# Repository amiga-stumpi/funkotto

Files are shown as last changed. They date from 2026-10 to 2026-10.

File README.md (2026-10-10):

# FunkOtto

WLAN-Adapter für den Amiga-Parallelport auf Basis des Raspberry Pi Pico 2 W.
Ziel sind eine eigene Firmware, ein SANA-II-Treiber für 68000/AmigaOS 1.3 und
ein Amiga-Konfigurationsprogramm.

## Aktueller Stand

**Aktuelle Hardwarebasis seit 08.10.2026:** Die KiCad-Dateien unter
[hardware/](hardware/) entsprechen bytegenau dem vom Nutzer bearbeiteten
`AmiWiFi_Pico2W.zip`. Dieser Stand ersetzt das zuvor importierte Rev-B2-Board.
[Importnachweis und Prüfsummen](docs/results/2026-10-08-nutzer-kicad-import.md).

Die vorhandenen Vorschauen, Bestückungsdaten und DRC-/ERC-Berichte beziehen sich
auf den vorherigen Rev-B2-Stand. Für diesen Dateiimport wurden sie nicht neu
erzeugt; die frühere DRC-Freigängigkeit ist damit kein Prüfnachweis für das
geänderte Board.

[Vorheriger Hardwarestand vom 07.10.2026](docs/results/2026-10-07-revb2.md):
Rev B2 mit U8 SN74LVC2G07DCKR (SC70-6), angepasstem Lötbild und
nativen DRC-/ERC-Prüfberichten. [Bisheriger Fortschritt](docs/results/2026-10-06-fortschritt.md).

Das Repository enthält den [Entwicklungsplan für Firmware v0.1](docs/firmware-v0.1-plan.md)
und das vollständige KiCad-Projekt mit lokalen Bibliotheken, Stückliste und Prüfberichten.
**Die erste Pico-Firmware M1 ist implementiert und als UF2 gebaut:** sichere
GPIO-Zustände, USB-Diagnose (`help`, `info`, `status`) und Watchdog.
[Build- und Testanleitung](firmware/README.md) ·
[Prüfergebnisse M1](docs/results/2026-10-08-firmware-m1.md).
**W1/W2 ist jetzt als WLAN-Testfirmware implementiert:** Scan, RAM-Konfiguration,
WPA2-Verbindung und Wiederverbindung. [Bedienung und Testablauf](firmware/WLAN_TEST.md).
Scan und erster WPA2-Join wurden am 08.10.2026 auf dem Pico bestätigt
(`LINK_UP`, erster Versuch, Join 2679 ms). Manuelles Wiederverbinden und automatische Erholung
nach AP-Ausfall sind ebenfalls bestätigt. Dauerlauf und weitere Fehlerfälle
bleiben offen. **W3 ist implementiert:** Ethernet-Rohtransport mit festen Puffern,
USB-Testprotokoll und PC-Werkzeug für ARP/ICMP. [W3-Testanleitung](firmware/W3_TEST.md) ·
[W3-Prüfstand](docs/results/2026-10-09-w3.md). Die realen ARP/ICMP-Tests sind bestanden:
12/12 und anschließend 1.000/1.000 Echo-Antworten einschließlich MTU 1500,
keine Verluste. Der 1.000er-Lauf ist anhand von JSON und PCAP geprüft.
AP-Ausfall, Wiederverbindung und erneuter Pakettest sind vom Nutzer bestätigt.
Langzeitbetrieb und die Ursache einzelner Latenzausreißer bleiben offen.
**W4 ist implementiert:** dauerhaftes Profil, `wifi save`/`wifi erase` und
Autoconnect nach Stromverlust. [W4-Anleitung](firmware/W4_TEST.md) ·
[W4-Prüfstand](docs/results/2026-10-09-w4.md). Gespeichertes Profil und erster
Kaltstart mit automatischer Wiederverbindung sind am Pico bestätigt. Auch Löschtest
und erneutes Einrichten/Verbinden/Speichern sind bestanden; die weitergehende Hardwareabnahme
bleibt offen.
Parallelport-Kommunikation und Amiga-Treiber folgen.
USB-Diagnose und Kaltstart ohne geöffnetes Terminal wurden am 08.10.2026 vom
Nutzer auf einem realen Pico bestätigt. Die elektrische M0-Abnahme bleibt offen.
**W5 wird auf Nutzerwunsch ausgelassen. M2 ist softwareseitig umgesetzt:**
PIO/DMA-Amiga-Link und 68000-Diagnosetool für HELLO/ECHO.
[M2-Testanleitung](firmware/M2_TEST.md) · [Prüfbericht](docs/results/2026-10-09-m2.md).
Standard-UF2 gesperrt, aktive Bustests nach M0. Der Nutzer hat den portfreien
`FunkOttoDiag SELFTEST` mit 64 ECHOs auf einem Amiga 500 mit 68020,
Kickstart 1.3 und Workbench 1.3 erfolgreich ausgeführt. M2 enthält noch kein WLAN.
[WLAN-Entwicklungsplan](docs/wlan-entwicklungsplan.md).

**M4-USB-Konfiguration:** eigenes Ziel `funkotto_m4_usb` auf W4-Basis,
versionierte Konfigurationsbefehle und PC-Werkzeug `tools/wifi_config.py`.
[Plan](docs/konfigurationsprotokoll-plan.md) · [Testanleitung](firmware/M4_USB_TEST.md) ·
[Protokoll](protocol/CONFIG.md) · [Prüfstand](docs/results/2026-10-10-m4-usb.md).
Trägerplatine noch nicht verfügbar; M0 und aktive M2-Abnahme bleiben offen.

**Amiga-Konfiguration vorbereitet:** `FunkOttoConfig SELFTEST` und `SIM` bieten
einen lokalen FOC1-Selbsttest und eine interaktive Adapter-Simulation mit
verdeckter Passworteingabe. Für 68000 / OS 1.3 gebaut, mit OS-Mocks geprüft;
realer A500-Test und Paralleltransport noch offen. Kein Firmwareupdate nötig.
[Umsetzungsplan](docs/amiga-konfiguration-plan.md) ·
[Amiga-Testanleitung](amiga/config/README.md) ·
[Prüfstand](docs/results/2026-10-10-amiga-config.md).

Die erste Firmware soll Parallelport-Kommunikation, WLAN-Rohpakete und ein
dauerhaft gespeichertes WLAN-Profil mit automatischer Wiederverbindung bieten.
Firmwareinstallation und Updates erfolgen vorerst über USB/BOOTSEL am Pico.
Firmwareupdates über den Amiga sind zurückgestellt.

Die Hardwarebasis ist der Nutzerstand vom 08.10.2026 unter [hardware/](hardware/),
auf Grundlage von Rev B2 und der zuvor bearbeiteten Rev-A-Datei. Ein zusätzlicher
Open-Drain-Resetpfad setzt den Pico bei Amiga-Reset oder fehlender Hostversorgung
über RUN zurück. Für v0.1 ist vorgesehen: Nach Reset startet die Firmware neu und verbindet WLAN
erneut; das gespeicherte Profil bleibt erhalten. M1 enthält diese WLAN-Funktion noch nicht.

Für USB/BOOTSEL im Sockel DB25 und USB-C-Trägerversorgung trennen und den
eigenen USB-Anschluss des Pico verwenden; alternativ den Pico herausnehmen.

Die Resetvariante ist in Schaltplan und Board umgesetzt. Pulsbreiten, Pegel,
Versorgungsfolgen und sichere Bustreiberfreigabe müssen vor aktiven Bustests
am Muster gemessen werden (M0 im Plan). Es gibt noch keine Fertigungsfreigabe.

Rev B1 bereinigt die KiCad-Netznamen, Schaltplan-/Footprintattribute,
Bibliothekskopien und Beschriftungen. DRC **mit Schaltplanvergleich** sowie ERC
melden in KiCad 10.0.6 jeweils 0 Fehler und 0 Warnungen. Bauteilpositionen und
Kupferrouting blieben bei B1 unverändert. B2 ändert U8 auf DCKR/SC70-6 und
passte ausschließlich sein lokales Routing an; die damaligen DRC- und ERC-Läufe waren fehlerfrei. Die frühere Rev-B-Prüfung war hinsichtlich
des nativen Schaltplanabgleichs unvollständig; Details und damalige Hardware-
Prüfsummen stehen im Firmwareplan. Aktuelle Prüfsummen stehen im oben verlinkten Importnachweis.

## Ideen und spätere Erweiterungen

Die [Ideenliste](docs/ideenliste.md) sammelt fortlaufend Erweiterungswünsche.
Erster Eintrag: eine später nachrüstbare Traffic-LED, optional getrennt für TX/RX.

## KiCad-Projekt öffnen

Repository herunterladen und `hardware/AmiWiFi.kicad_pro` mit KiCad 10 öffnen.
Die Bibliotheken in `hardware/` gehören zum Projekt.

- [Hinweise zum Hardwarestand Rev B2](docs/KICAD_REV_B2.txt)
- [Stückliste](docs/BOM.csv) und [Pinbelegung](docs/PINOUT.csv)
- [Vorschauen](preview/) und [Prüfberichte](validation/)

Am 08.10.2026 durch die KiCad-Dateien aus dem Nutzerarchiv ersetzt.
Die Dateien wurden beim Import nicht bearbeitet. Elektrische Musterprüfung
und Fertigungsfreigabe bleiben offen.

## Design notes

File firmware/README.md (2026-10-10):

> **M4_USB:** [WLAN-Konfiguration über USB testen](M4_USB_TEST.md). Eigenes Ziel auf W4-Basis, Parallelport gesperrt; erster realer HELLO-/Statustest mit gespeichertem Profil und LINK_UP bestanden; weitere Konfigurationsprüfungen offen.

> **M2 softwareseitig umgesetzt:** [Amiga-Diagnose und Laborablauf](M2_TEST.md).
> Nutzer-SELFTEST mit 64 ECHOs auf Amiga 500 / 68020 / Kickstart 1.3 / Workbench 1.3 bestanden.
> Standard-Build gesperrt, aktive M2-Abnahme offen; WLAN separat in W4.

> Neu: **W4** als Ziel `funkotto_w4`: dauerhaftes Profil und Autoconnect.
> [W4-Bedienung und Kaltstarttest](W4_TEST.md). Gespeichertes Profil und erster Kaltstart mit automatischer Wiederverbindung am Pico bestätigt; Löschtest und erneutes Einrichten/Verbinden/Speichern bestanden. Weitergehende Hardwareabnahme noch offen.

> W3 ist als zusätzliches Ziel `funkotto_w3` implementiert:
> [Roh-Ethernet über USB testen](W3_TEST.md). Die realen ARP/ICMP-Tests sind bestanden
> (12/12 und 1.000/1.000, MTU 1500; JSON/PCAP geprüft). AP-Ausfall mit
> Wiederverbindung und erneutem Pakettest ist vom Nutzer bestätigt.
> Langzeitbetrieb und Latenzausreißer bleiben offen.
> M1 und W1/W2 bleiben separat baubar; alle drei Ziele halten den Amiga-Bus gesperrt.

# FunkOtto – Pico-Firmware

**Neu: [W1/W2-WLAN-Testfirmware und Bedienung](WLAN_TEST.md).**
Der Standardbuild erzeugt zusätzlich `funkotto_w12.uf2` mit Scan, RAM-Profil
und WPA2-Verbindung auf Core 1. M1 bleibt als eigenes Diagnoseziel erhalten.
WLAN ist softwareseitig gebaut/getestet; der reale Funk-Test steht noch aus.

## M1-Grundversion

`0.1.0-m1` ist die erste USB-Diagnose-Firmware für **Pico 2 W / RP2350 Arm**.
Sie ist noch kein Netzwerkadapter. M1 liefert Build, sicheren Grundstart,
USB-Konsole und Watchdog. WLAN, Parallelport-Protokoll, Profilspeicherung und
SANA-II folgen in den nächsten Arbeitspaketen.

## Implementiert

- GPIO-Initialisierung vor USB/Diagnose: GP21 `FW_DATA_EN` und GP22 `FW_CTRL_EN`
  dauerhaft Low, GP20 `DATA_DIR` High (Amiga → Pico).
- GP0–GP11 und GP26 bleiben Eingänge; BUSY/ACK werden nur im Ausgangslatch
  vorbereitet. Es gibt in M1 keinen Befehl zum Einschalten der Bustreiber.
- Keine UART-Ausgabe auf den Datenpins GP0/GP1; keine Nutzung freier GP27/GP28.
- USB-CDC-Diagnose mit `help`, `info`, `status`, begrenztem Zeilenpuffer und
  begrenzter Eingabearbeit pro Hauptschleife.
- Start wartet nicht auf ein angeschlossenes USB-Terminal. USB-Ausgaben haben
  einen kurzen Timeout; ein verpasster Starttext lässt sich mit `info` abrufen.
- 8-s-Watchdog; unerwartete Pinzustände führen zur erneuten Sperrung und zum
  Watchdog-Neustart. Externe 4,7-kΩ-Pulldowns sichern die Zeit vor Firmwarestart.
- Letzte 8192 Byte des 4-MiB-Flashs für spätere Profile reserviert:
  Flashoffsets `0x003FE000` und `0x003FF000`, XIP ab `0x103FE000`.
  M1 schreibt oder löscht dort nichts. Linker und UF2-Prüfung sichern die Grenze.
- Ein weiterer 4-KiB-Sektor direkt davor (`0x103FD000`–`0x103FDFFF`) bleibt für
  den RP2350-E10-Kompatibilitätsblock reserviert. Die UF2 setzt diesen Block
  gezielt auf `0x103FDF00`; die SDK-Standardadresse `0x10FFFF00` wird vermieden.
  Diese Trennung ist vor der späteren Profilspeicherung am Muster zu testen.

Core 0 bedient Diagnose und Watchdog; Core 1 ist noch unbenutzt. Es gibt keine
eigenen PIO-/DMA-Belegungen. SDK/TinyUSB verwenden ihre USB-Interrupt- und
Timermechanismen. Die Ressourcenaufteilung mit CYW43 folgt vor M2/M3.
Die Traffic-LED und Polyfuse bleiben Einträge in der Ideenliste.

## Bauen (Linux, Referenz Ubuntu 24.04)

Versionen und Commit-IDs stehen in [`dependencies.json`](dependencies.json).
Der SDK-Build wird auf Pico SDK 2.2.0 und dessen TinyUSB-Commit geprüft;
picotool 2.2.0 wird anhand einer festen Commit-ID bezogen.

```sh
sudo apt-get update
sudo apt-get install --no-install-recommends git build-essential python3 python3-venv \
  gcc-arm-none-eabi=15:13.2.rel1-2 \
  binutils-arm-none-eabi=2.42-1ubuntu1+23 \
  libnewlib-arm-none-eabi=4.4.0.20231231-2 \
  libnewlib-dev=4.4.0.20231231-2 \
  libstdc++-arm-none-eabi-dev=15:13.2.rel1-2+26
python3 -m venv .venv
. .venv/bin/activate
python -m pip install cmake==3.31.6 ninja==1.11.1.4
python tools/bootstrap_sdk.py
python tools/check_board_contract.py
python tests/run_host_tests.py
python -m unittest discover -s tests -p 'test_*.py'
cmake -S firmware -B build/m1 -G Ninja \
  -DPICO_SDK_PATH="$PWD/.deps/pico-sdk" \
  -DCMAKE_BUILD_TYPE=Release \
  -DFUNKOTTO_SOURCE_ID="$(git rev-parse --short=12 HEAD)"
cmake --build build/m1 --parallel
python tools/check_firmware_artifacts.py build/m1
python tools/check_firmware_artifacts.py build/m1 --target funkotto_w12
```

Beim ersten Build werden SDK, TinyUSB, CYW43 und picotool benötigt; Netzwerkzugang ist
dafür erforderlich. Warnungen zu nicht initialisierten lwIP-/Bluetooth-Submodulen sind erwartbar:
W1/W2 nutzt CYW43 ohne diese Bibliotheken. Das SDK meldet dabei pauschal fehlende
volle WLAN-Unterstützung; unser eigenes Poll-Target wird trotzdem gebaut.
In einer Umgebung ohne Zugriff auf `/proc` kann LeakSanitizer nicht arbeiten;
für die heapfreien C-Tests dort `ASAN_OPTIONS=detect_leaks=0` setzen.
AddressSanitizer und UndefinedBehaviorSanitizer bleiben dabei aktiv.

Ergebnisse: `funkotto_m1.uf2`, `funkotto_m1.elf`, `funkotto_m1.elf.map`,
`funkotto_m1.bin` und `manifest.json` mit Quellen-/Artefaktprüfsummen und
Werkzeugversionen. W1/W2 liefert gleichnamige Dateien mit Präfix
`funkotto_w12` und `funkotto_w12-manifest.json`. Mit
`-DFUNKOTTO_BUILD_WIFI=OFF` lässt sich ausschließlich M1 bauen. Die CI baut und prüft dieselben Ziele. SDK-Dateipfade werden
im Zielcode normalisiert; eine Zusage für beliebige andere Toolchainstände
oder bitidentische Debug-Dateien ergibt sich daraus nicht.

## Erster Test am Pico

1. Am einfachsten den Pico aus dem Trägersockel nehmen. Für den USB-Service im
   Sockel **DB25 und USB-C-Trägerversorgung abziehen**. USB-C am Träger ist nur
   Versorgung, nicht die Programmierschnittstelle.
2. BOOTSEL gedrückt halten und den eigenen USB-Port des Pico mit dem PC verbinden.
3. `funkotto_m1.uf2` auf das BOOTSEL-Laufwerk kopieren. Der Pico startet neu.
4. Den neuen seriellen USB-Port öffnen (z. B. 115200, 8N1, keine Flusssteuerung).
   Befehle mit Enter abschließen. Die eingestellte Baudrate ist bei USB-CDC
   kein physischer UART-Takt.
5. `info`, danach `status` eingeben. Erwartet: `stage=M1`, `bus_locked=1`,
   `output_mask=0x00700000`. Nur die drei Steuer-GPIOs 20/21/22 sind Ausgänge.
6. Pico stromlos machen, erneut verbinden und wieder `status` abfragen.

`safe_init_us` ist der interne Timerstand nach GPIO-Initialisierung. Er ist
**keine Messung Versorgung → Parallelport-Bereitschaft**; M1 bietet noch keine
Parallelport-Antwort. Ohne WLAN-Initialisierung leuchtet auch die Pico-WLAN-LED
nicht automatisch. Ein ausgeschaltetes Terminal verhindert den Firmwarestart nicht.

Messungen am Träger gemäß M0 bleiben offen. Der Nutzer hat am 08.10.2026 USB-Status und Kaltstart ohne geöffnetes Terminal
auf dem Pico bestätigt ([Bericht](../docs/results/2026-10-08-firmware-m1.md)).
Elektrische Pegel, Reset-Pulsbreiten und Watchdog-Fehlerinjektion bleiben ungeprüft.
Die nächsten Schritte stehen im [WLAN-Plan](../docs/wlan-entwicklungsplan.md).

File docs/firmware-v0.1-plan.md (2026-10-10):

# FunkOtto: Plan für die erste funktionale Firmware v0.1

Stand: 10.10.2026 · Status: M1 und WLAN W1–W4 umgesetzt, Grundfunktionen am Pico bestätigt; M2 softwareseitig umgesetzt, W5 ausgelassen, M0 offen

## 1. Ziel und Entscheidung

FunkOtto verbindet den Amiga-Parallelport über einen Raspberry Pi Pico 2 W mit
WLAN. Die erste funktionale Firmware soll vom Amiga erkannt und konfiguriert
werden, Zugangsdaten stromausfallsicher speichern, sich nach dem Einschalten
selbstständig verbinden und Ethernet-Frames in beide Richtungen übertragen.

**Firmwareinstallation und Firmwareupdates erfolgen vorerst ausschließlich über
USB/BOOTSEL am Pico.** Kein Amiga-Flasher, kein SWD über DB25, kein OTA und keine
A/B-Firmwarepartitionen in v0.1. Zwei kleine Konfigurationssektoren dienen nur dem
WLAN-Profil; sie sind keine Firmware-Update-Slots.

Die Firmware wird als Ethernet-Adapter entwickelt: Der spätere Amiga-TCP/IP-Stack
übernimmt IP-Adresse, DHCP, DNS und TCP/UDP. Der Pico arbeitet als WLAN-Station mit
einer MAC-Adresse. Keine NAT-Funktion, kein WLAN-Modem mit AT-Kommandos und kein
Mehr-MAC-Bridging. Zunächst WPA2-Personal im 2,4-GHz-Netz und ein gespeichertes
Profil. Weitere Authentifizierungsarten erst nach gesonderter Prüfung.

Der SANA-II-Treiber und die Intuition-Oberfläche bleiben eigenständige Folgepakete.
Für v0.1 wird jedoch ein kleines 68000-/OS-1.3-kompatibles Diagnoseprogramm
benötigt, das reale Amiga-Kommunikation, Konfiguration und Rohpakete testet.
Ein erfolgreicher PC-Test allein erfüllt das Ziel nicht.

## 2. Definition: Wann ist v0.1 funktional?

- Der Amiga liest Identität, Firmware-/Protokollversion und Status zuverlässig.
- Ein ungeflashter Pico erhält eine reproduzierbar gebaute UF2 über USB.
- SSID und Passwort können über den Amiga gesetzt, geprüft, gespeichert und gelöscht werden.
- Nach vollständiger Stromunterbrechung verbindet sich der Pico ohne Konfigurationstool erneut.
- Bei unerreichbarem Access Point bleibt der Parallelport bedienbar; Verbindungsversuche werden wiederholt.
- Ethernet-Frames kommen vom Amiga zum WLAN und zurück. ARP und ein ICMP-Echo-Test mit dem Diagnoseprogramm sind nachgewiesen.
- Datenfehler, volle Puffer, Timeout, Hostneustart und WLAN-Ausfall erzeugen definierte Zustände statt Buskollisionen oder Hänger.
- Firmware, Buildanleitung, Protokoll, GPIO-Zuordnung und tatsächliche Messberichte sind versioniert.

Der Start unter 100 ms bis zur Parallelport-Bereitschaft ist ein **zu messendes
Optimierungsziel**, keine bestätigte Eigenschaft. WLAN-Verbindungszeit wird
separat gemessen. Höherer Durchsatz als eine Plipbox ist ein späteres Vergleichsziel.

## 3. Verbindliche Hardwarebasis: Nutzerstand vom 08.10.2026

Basis ist das vom Nutzer bearbeitete `AmiWiFi_Pico2W.zip`, unverändert importiert
mit Commit `d47ea64065e99507edfb3ae9dc4aa1727e00eb0b`. Es ersetzt den bisherigen
Rev-B2-Stand. [Importnachweis](results/2026-10-08-nutzer-kicad-import.md).
M1 prüft die folgende GPIO-Zuordnung und die Reset-/Freigabenetze direkt gegen
das aktuelle PCB. Dieser Netzabgleich ersetzt weder DRC/ERC noch Messungen.
Die Firmwarearbeit verändert keine KiCad-Dateien.

| Funktion | Pico-GPIO | Physische Modul-Pins |
| --- | --- | --- |
| Parallel D0–D7 | GP0–GP7 | 1, 2, 4, 5, 6, 7, 9, 10 |
| STROBE_N, Eingang | GP8 | 11 |
| SEL, Eingang | GP9 | 12 |
| BUSY, Ausgang | GP10 | 14 |
| POUT, Ausgang | GP11 | 15 |
| DATA_DIR | GP20 | 26 |
| FW_DATA_EN | GP21 | 27 |
| FW_CTRL_EN | GP22 | 29 |
| ACK_N, Ausgang | GP26 | 31 |
| Hardware-Reset RUN, aktiv Low | kein GPIO | 30 |

`DATA_DIR=1` bedeutet Amiga→Pico; `DATA_DIR=0` Pico→Amiga.
Der Datenbus darf erst nach einer bestätigten Richtungsübergabe aktiv werden.
Die Pico-Pins 16–25 sind im Trägersockel nicht vorhanden.

### Gewählte Resetvariante

**Jeder am Adapter anliegende Hardware-Amiga-Reset setzt auch den Pico zurück.**
U5/U6 sperren weiterhin die Bustreiber. Zusätzlich verknüpft U8, ein
SN74LVC2G07DCKR (SC70-6/DCK) mit zwei nichtinvertierenden Open-Drain-Ausgängen, `RESET_IN`
und `HOST_PRESENT`. Seine Ausgänge liegen gemeinsam an `PICO_RUN_N` und
Pico-Modulpin 30 (`RUN`). Ein Low an einem Eingang zieht RUN auf Low.
Nur bei beiden High gibt U8 RUN frei; der interne Pico-Pullup zieht auf 3,3 V.
Keine direkte 5-V-Verbindung an RUN; kein zusätzlicher Pico-GPIO erforderlich.

U8-Pins: 1 RESET_IN, 2 GND, 3 HOST_PRESENT, 4 PICO_RUN_N, 5 +3V3_IF,
6 PICO_RUN_N. C11: 100 nF an VCC/GND; R36: 100 kOhm RESET_IN/GND;
TP7: RUN-Messpunkt. Bestehende FW_ENABLE-Pulldowns R28/R29 bleiben 4,7 kOhm.
Keinen Push-Pull-Puffer als Ersatz für U8 einsetzen.

Nach Reset startet die Firmware vollständig neu: sichere GPIOs, leere
PIO-/DMA-Zustände und Queues, neue Protokollsitzung, gespeichertes WLAN-Profil
lesen, WLAN neu initialisieren und verbinden. **Die WLAN-Verbindung bleibt bei
einem Hardware-Amiga-Reset nicht bestehen.** Profile im Flash bleiben erhalten;
ein unterbrochener Schreibvorgang muss auf den letzten gültigen Stand zurückfallen.
Ein Software-Neustart ohne elektrischen Resetimpuls erfordert weiterhin die
Protokoll-Resynchronisation. `LINK_RESET` kann eine gesunde WLAN-Verbindung erhalten.

### USB/BOOTSEL mit eingebautem Pico

**DB25 und USB-C-Versorgung des Trägers trennen**, dann BOOTSEL halten und den
Pico über seinen eigenen USB-Anschluss verbinden. D1 isoliert VSYS von der
Trägerversorgung, U8 bleibt unversorgt und seine Ioff-Ausgänge hochohmig.
Alternativ den Pico aus dem Sockel nehmen. Ein versorgter Träger ohne Amiga
hält RUN absichtlich Low und verhindert diesen USB-Servicebetrieb.
Die USB-C-Buchse des Trägers liefert nur Strom, keine Firmware-Datenverbindung.
Diese Versorgungsfolge und fehlende Rückspeisung sind am Muster zu verifizieren.

### M0 bleibt die elektrische Abnahme

Die Resetarchitektur ist festgelegt und in KiCad umgesetzt. Das ist noch kein
Messnachweis. Vor dem ersten aktiven Bustest:

1. RESET_IN, HOST_PRESENT, RUN/TP7 und beide OE_N-Signale aufzeichnen;
   Pegel und RUN-Low-Dauer gegen die Datenblattanforderungen prüfen.
2. Amiga-Reset während Pico→Amiga und Amiga→Pico testen; kein Wiederanlauf
   alter Busausgänge nach Resetfreigabe. FW_ENABLEs bleiben beim Boot aus.
3. Steuerpfad erst mit vorbereiteten Idle-Pegeln aktivieren; neue HELLO-Sitzung
   und bestätigte Richtungsübergabe vor Datenausgabe verlangen.
4. Beide Einschaltreihenfolgen, Host aus/an, Trägerversorgung und Pico-USB sowie
   Reset während Flash-Schreiben/Löschen prüfen.

Bis zur Abnahme bleiben aktive Datenbustests gesperrt. Softwarebau, Parser-,
Speicher- und isolierte WLAN-Tests können bereits laufen.

**Historischer Nachweis, nicht für das aktuelle Nutzerboard:**
Digitale Prüfung von B2 mit KiCad 10.0.6: **0 DRC-Fehler/0 Warnungen, 0 offene
Verbindungen, 0 Schaltplanabweichungen; ERC 0 Fehler/0 Warnungen.** DRC ausdrücklich
mit `--schematic-parity --all-track-errors`. Exakte Netznamen inklusive `/` und
NC-Netzen abgeglichen; kein Entfernen von Namenspräfixen im Vergleich.

Korrektur gegenüber dem zuvor gelieferten Rev-B-Paket: Der alte CLI-Lauf ließ
den nativen Schaltplanvergleich aus. Daher blieben Netznamen- und Attributkonflikte
unentdeckt. B1 synchronisiert diese Daten und die projektlokalen Footprints,
kennzeichnet die realen Versorgungseinspeisungen mit PWR_FLAG und verwendet
für U4 ein Symbol für die fest verdrahtete Richtung B→A. Das U7-Symbol bildet
ausschließlich die 30 tatsächlich bestückten Sockelkontakte ab. Bestückungsdruck
und Bibliothekskopien sind bereinigt, ohne neue Prüfausnahmen anzulegen.
Diese B1-Korrektur ließ Padgeometrien, Platzierung und Kupfer unverändert.
B2 ändert ausschließlich das U8-Gehäuse und sein lokales Routing; die Resetfunktion
bleibt gleich. [B2-Prüfbericht](results/2026-10-07-revb2.md).
Keine Fertigungsfreigabe; elektrische Musterprüfungen bleiben offen.

Aktuelle Hardware-Referenzen, SHA-256:

- Schaltplan: `7c79beedb5473c872b8ad4855c7a03fb04484a50e73ab5bca5bac22929186a50`
- PCB: `b2f32df78c15e37ceb1bc0433f0356848106e7a86a1e82df63c3da5a7e26928c`
- Frühere Rev-B2-PCB-Prüfsumme: `a7a9cbb19c9f8817d6666fb08a87a784668ab8e951d3fde8aa5edc5f07c89981`

## 4. Architektur und Build

C/C++ mit Raspberry Pi Pico SDK, Ziel `PICO_BOARD=pico2_w`, Arm-Build für RP2350.
M1 legt SDK 2.2.0, TinyUSB, picotool und Buildwerkzeuge in
[`firmware/dependencies.json`](../firmware/dependencies.json) fest. Kein gleitendes `master` als reproduzierbare Buildabhängigkeit.
CI liefert UF2, ELF, MAP und ein Manifest mit Versions- und Prüfsummenangaben.
Keine WLAN-Zugangsdaten im Quelltext, Repository, Buildartefakt oder Testlog.

Geplante Aufteilung:

| Modul | Aufgabe |
| --- | --- |
| `board` | GPIOs, sichere Startpegel, Freigaben, Hardwarekennung |
| `parallel` | PIO, DMA, Byte-/Blocktransfer, Richtungswechsel und Timeout |
| `protocol` | Parser, CRC, Sitzungen, Kommandos, Antworten |
| `wifi` | CYW43-Initialisierung, Scan, Join, Wiederverbindung und Status |
| `ethernet` | Rohframes, MAC, TX/RX-Ringe, Filter und Zähler |
| `config` | RAM-Profil, zwei Flashsektoren, Speichern/Löschen |
| `diagnostics` | Laufzeit-/Fehlerzähler, Watchdog, optionale USB-Ausgaben |

Core 0 besitzt Parallelport, Protokoll und Pufferübergaben. Core 1 besitzt WLAN
und alle CYW43-Aufrufe. Die ersten Bring-up-Schritte dürfen noch einkernig laufen;
vor der Integration wird die Zuständigkeit verbindlich umgesetzt. Zwischen den
Kernen liegen begrenzte Queues und eindeutig übergebene Puffer. `volatile`
ersetzt keine Synchronisierung. Interrupts erledigen nur kurze Zustandsübergaben.
Flash-Schreiben erfordert einen koordinierten Stillstand beider Kerne und DMA.

PIO-State-Machines, DMA-Kanäle, IRQs und SRAM-Budget in einer Ressourcentabelle
festhalten. WLAN verwendet eigene SDK-Ressourcen; keine festen PIO-/DMA-Nummern
annehmen, die mit CYW43 kollidieren. Zunächst je acht feste 1600-Byte-TX-/RX-Puffer
als Budgetansatz; tatsächlichen Gesamtverbrauch einschließlich WLAN messen.

### Startfolge

1. Daten-GPIOs Eingang, beide FW_ENABLEs aus, DATA_DIR auf Amiga→Pico.
2. Steuer-Ausgangswerte vorbereiten, insbesondere ACK_N inaktiv; PIO/FIFOs leeren.
3. Timer, Protokoll, Linkzustand und sichere Freigabesequenz initialisieren.
4. Steuerpfad mit sicheren Idle-Pegeln freigeben und Parallelport-Status
   bereitstellen; Daten-Ausgabe erst nach neuer Sitzung/Richtungsübergabe.
   Kein Warten auf USB-Terminal oder WLAN.
5. Profil prüfen und WLAN auf seinem eigenen Ausführungspfad initialisieren.
6. Bei gültigem Profil automatisch verbinden, sonst `UNCONFIGURED` melden.

`GET_INFO` funktioniert vor WLAN-Bereitschaft. Noch unbekannte Stations-MAC mit
Gültigkeitsbit ausweisen und später erneut abfragbar machen; kein erfundener
MAC-Wert. Frühbereitschaft darf nicht durch einen blockierenden WLAN-Init auf
Core 0 vorgetäuscht werden. Der Watchdog überwacht den Fortschritt beider Kerne,
nicht nur einen regelmäßig laufenden Timer.

## 5. Parallelport-Protokoll v1

Die folgenden Angaben bleiben der Integrationsrahmen. M2 implementiert das
[Diagnoseprofil B1536](../protocol/M2.md) mit konkreter Host-Registerfolge,
PIO/DMA und Fehlerrückkehr. Reale Oszillogramme und Timingabnahme fehlen noch.

- Halbduplex, Amiga als Transaktionsmaster. Pico sendet Daten ausschließlich
  innerhalb eines ausdrücklich angeforderten Lesevorgangs.
- SEL steuert die Linkphase, STROBE markiert Portzugriffe. BUSY ist Handshake/
  Rückdruck; POUT zeigt wartende Daten oder Antworten. ACK_N ist zunächst
  optional und erst nach erfolgreichem Polling-Betrieb als Paketereignis aktiv.
- Zuerst langsamer Byte-Handshake für den Hardwaretest, danach begrenzte Blöcke
  mit einmaligem Block-Handshake. Keine garantierte Spitzenrate in v0.1.
- Datenrichtungen ausschließlich mit deaktiviertem Translator und abgestimmter
  CIA-Datenrichtung wechseln. Erstes Lesebyte vorladen; notwendige Dummy-Zyklen
  ausdrücklich definieren und prüfen. Automatische CIA-STROBE-Impulse nicht
  mit einer frei programmierbaren GPIO-Taktquelle verwechseln.
- Anfangs maximal ein offener Auftrag; große Pakete dürfen in bestätigte
  Teilblöcke zerlegt werden. Byteabstand und Timeout sind Mess-/Protokollwerte,
  keine von der Amiga-CPU-Geschwindigkeit abhängigen NOP-Schleifen.

Rahmenvorschlag: 8-Byte-Header mit Magic `0x4157`, Version, Opcode, Payload-Länge
und Sequenznummer, danach Payload und CRC16/CCITT-FALSE über Header+Payload.
Mehrbytewerte big endian. Explizit byteweise kodieren, keine C-Strukturen direkt
übertragen. Bei Protokollfreigabe alle Feldbreiten, Statuswerte und CRC-Testvektoren
festschreiben. Bisherige Magic bleibt zur Kontinuität des Hardwareplans erhalten.

Kontrollpayload maximal 1518 Bytes; Ethernet zunächst ungetaggt, MTU 1500,
maximal 1514 Bytes einschließlich Ethernet-Header, ohne FCS. VLAN wird nicht als
unterstützt gemeldet. Mindestlänge und Padding beim CYW43-Senden empirisch prüfen.
Parser prüft Länge vor jedem Kopieren, Versionsverträglichkeit und CRC vor jeder
Zustandsänderung. Unbekannte Kommandos erzeugen `UNSUPPORTED`.

| Kommandogruppe | Geplante Kommandos |
| --- | --- |
| Erkennung | `HELLO`, `GET_INFO`, `GET_STATUS`, `GET_STATS` |
| Diagnose | `ECHO`, `LINK_RESET` |
| WLAN | `WIFI_SCAN`, `SCAN_NEXT`, `CONNECT`, `DISCONNECT` |
| Profil | `SET_PROFILE`, `SAVE_PROFILE`, `ERASE_PROFILE` |
| Daten | `TX_FRAME`, `RX_FRAME` |

`HELLO` etabliert eine neue Sitzung mit Epochkennung. Alte Antworten, Sequenzen
und DMA-Reste dürfen nach Reset keine neue Sitzung beeinflussen. Wiederholung
desselben gültigen Auftrags liefert das gespeicherte Ergebnis statt erneutem
Senden eines Ethernet-Pakets. Genau-einmal-Zustellung über einen Pico-Stromausfall
wird nicht behauptet; bei unklarer TX-Zustellung Status entsprechend melden.

Timeout, abgebrochener Rahmen und verlorene Synchronisation führen zu BUSY,
gesperrtem Datenbus, geleerten Teilrahmen und neuer Synchronisation. Fehler beim
Parallelport sollen eine gesunde WLAN-Verbindung möglichst nicht neu starten.
Davon ausgenommen ist der elektrische Amiga-Reset: Er setzt über RUN den
gesamten Pico zurück und erfordert einen neuen WLAN-Verbindungsaufbau.

## 6. WLAN und Roh-Ethernet

V0.1 benötigt echte Ethernet-Rohframes. Die „RAW API“ von lwIP ist nicht dieselbe
Schnittstelle. Auch `pico_cyw43_arch_none` allein darf nicht ungeprüft als fertiger
Ethernet-Adapter behandelt werden. M3 enthält deshalb einen frühen Integrations-
versuch mit der festgelegten SDK-Version: TX über `cyw43_send_ethernet` und ein
eigener RX-Einstieg, etwa `cyw43_cb_process_ethernet`, mit überprüftem Callback-
Kontext, Puffereigentum und Linkzustandsbehandlung. Standard-Stub-Callbacks dürfen
nicht unbemerkt aktiv bleiben. SDK-Anpassungen in einem kleinen Adapter kapseln.

Pico-IP-Stack, eigener DHCP-Client oder ein lokaler Ping vom Pico sind kein Ersatz
für diesen Rohframe-Nachweis. Linkbereitschaft meint WLAN-Assoziation und
Authentifizierung, nicht eine vom Pico bezogene IP-Adresse. Die WLAN-Stations-MAC
wird später dem Amiga als Netzwerkkartenadresse mitgeteilt.

Nichtblockierender Zustandsautomat:
`UNCONFIGURED → INITIALIZING → CONNECTING → LINK_UP` sowie `RETRY_WAIT` und `ERROR`.
Ein Verbindungsversuch erhält zunächst 15 s als anpassbaren Grenzwert. Danach
Wiederholung mit 1/2/4/8/16/30 s Abstand, maximal 30 s. Manuelles `DISCONNECT`
verhindert automatische Neuversuche bis `CONNECT` oder Neustart. Falsches Passwort
wird als solches gemeldet, sofern der Treiber es unterscheidet; keine schnelle
Endlosschleife. Länderkennung für Deutschland korrekt konfigurieren.

Scan wird auf ausdrücklichen Auftrag gestartet, mit begrenzter Ergebniszahl und
Timeout. Scan unter Last darf für v0.1 mit `BUSY` abgewiesen werden. SSIDs sind
Bytefolgen bis 32 Bytes; keine ungeprüften C-Strings. Zunächst WPA2-Passphrasen mit
8–63 Zeichen; 64-stellige Hex-Schlüssel sind ohne separate Implementierung nicht
unterstützt. Das Statuskommando liefert niemals das Passwort.

Empfangene Frames werden vor Ende des Callbacks in eigene Puffer kopiert.
TX-Puffer erst nach der bestätigten Übernahme gemäß SDK-Vertrag freigeben.
Bei vollen Ringen: eindeutiger Rückdruck für Host-TX, gezählter Drop für WLAN-RX;
nie ungelesene Frames still überschreiben. Broadcast muss für ARP/DHCP funktionieren.
Multicast und optionale Filter erst nach eigenem Test als Fähigkeiten melden.

## 7. Dauerhafte WLAN-Konfiguration

Ein Profil enthält Schema-Version, SSID-Länge/-Bytes, Authentifizierung,
Passwort-Länge/-Bytes, Länderkennung, Sequenznummer und CRC32. Zwei getrennte
Flashsektoren mit jeweils 4096 Bytes am Flashende reservieren; Kapazität aus dem
Board-/SDK-Ziel übernehmen und im Build prüfen. Linkerskript und UF2 dürfen diese
8192 Bytes nicht als Firmware belegen. CI prüft die Adressbereiche.

In M1 bereits reserviert: Profile ab XIP `0x103FE000`; zusätzlich der davorliegende
4-KiB-Sektor ab `0x103FD000` ausschließlich für den RP2350-E10-UF2-Block bei
`0x103FDF00`. Der normale Firmwarebereich endet davor. Damit liegt auch dieser
SDK-Kompatibilitätsblock außerhalb der Profile. Der UF2-Prüfer kontrolliert
beide Blocktypen. Ein realer Profilerhalt über BOOTSEL-Updates ist in M4 zu testen.

`SET_PROFILE` ändert nur die RAM-Konfiguration, `CONNECT` testet sie.
`SAVE_PROFILE` speichert nach ausdrücklicher Benutzeraktion. Ablauf:

1. Neue Hostaufträge pausieren, Link/DMA beruhigen, Flash-Operation ankündigen.
2. Inaktiven Sektor löschen und Datensatz mit höherer Sequenz schreiben.
3. Inhalt zurücklesen und CRC prüfen; Commit-Marker in separater Flashseite zuletzt schreiben.
4. Erst danach Erfolg melden; bisheriges gültiges Profil bis dahin erhalten.
5. Betrieb und Hostkommunikation wieder freigeben.

Die RAM-Ausführung, Interrupts, zweiter Kern und sämtliche Flash-lesenden DMA-
Zugriffe müssen den Anforderungen von `flash_safe_execute` entsprechen.
Eine Funktionsmarkierung „läuft aus RAM“ allein genügt nicht. WLAN darf beim
seltenen Speichern kurz pausieren oder neu verbinden; das muss sichtbar sein.

Beim Start den neuesten vollständig gültigen Datensatz verwenden. Sind beide
ungültig, `UNCONFIGURED` statt Bootschleife. Sequenzüberlauf berücksichtigen.
`ERASE_PROFILE` schreibt zunächst einen gültigen, jüngeren Löschdatensatz,
bevor alte Zugangsdaten entfernt werden. Nach Stromausfall darf nicht versehentlich
das ältere Profil reaktiviert werden. Erfolg erst nach vollständigem Löschen melden;
unvollständige Bereinigung beim nächsten Start beenden. Keine automatische
Flash-Schreiboperation bei jedem Reconnect.

Zugangsdaten sind gegen versehentlichen Verlust abgesichert, nicht gegen physischen
Flash-Zugriff verschlüsselt. Normale USB-Updates sollen das Profil erhalten, wenn
Image und Speicherlayout es auslassen. Ein vollständiges Flash-Löschen entfernt es.
Dieses Verhalten mit dem konkreten Updateverfahren testen und dokumentieren.

## 8. Arbeitspakete, Reihenfolge und Abnahme

| Schritt | Ergebnis | Abnahme |
| --- | --- | --- |
| M0 Hardware-/Protokollreview | Reset-/Hostverhalten und sichere Freigaben geklärt | Rev-B-RUN-Pfad und OE-Gating gemessen; kein Wiederanlauf mit altem Datenbus |
| M1 Build und Grundstart | SDK-Pin, CI, UF2, sichere GPIOs, Versionsausgabe | Build aus frischem Checkout; Start ohne USB-Terminal; Datenbus bleibt gesperrt |
| M2 Amiga-Link | PIO/DMA, Polling-Diagnosetool, HELLO/ECHO, Fehlerfälle | Nach M0 reale 68000-/OS-1.3-Transfers in beide Richtungen, kein Buskonflikt |
| M3 WLAN-Rohdaten | Scan, Join, Stations-MAC, Roh-TX/RX | Frame-Nachweis an einem zweiten LAN-Rechner; kein Pico-IP-Stack als Ersatz |
| M4 Konfiguration | Amiga-Kommandos, Flashprofil, Autoconnect | 100 Kaltstarts; gezielte Stromunterbrechung und RUN-Reset in jeder Schreib-/Löschphase |
| M5 Integration | Ethernet-Ringe, Rückdruck, Status und Recovery | ARP/ICMP vom Amiga-Diagnosetool über FunkOtto; AP-Ausfall und Hostreset überstanden |
| M6 Freigabe v0.1 | Releasekandidat, Installationsanleitung, Messbericht | 24-h-Dauerlauf ohne Datenkorruption/Buskollision; alle Einschränkungen dokumentiert |

**Fortschritt am 08.10.2026:** M1-Quellen, USB-Konsole, GPIO-Sperre, Watchdog,
Buildworkflow und automatisierte Prüfungen sind vorhanden. Zwei lokale Builds
aus getrennten Quellverzeichnissen liefern bytegleiche UF2/BIN-Dateien.
GPIO-/Parser-Hosttests und Artefaktprüfungen bestehen. Der Nutzer hat USB-Status
und Kaltstart ohne geöffnetes Terminal am realen Pico bestätigt. Watchdog-
Fehlerinjektion und elektrische Musterabnahme bleiben offen.
Die vorgezogene isolierte M3-Entwicklung beschreibt der
[WLAN-Entwicklungsplan](wlan-entwicklungsplan.md).
**Fortschritt am 09.10.2026:** Die isolierte WLAN-Entwicklung W1–W4 ist
umgesetzt. Rohframe-Transport (1.000/1.000 Pings), Wiederverbindung sowie
Speichern, Kaltstart-Autoconnect, Löschen und erneutes Speichern sind am Pico
bestätigt. [W3-Prüfstand](results/2026-10-09-w3.md) ·
[W4-Prüfstand](results/2026-10-09-w4.md).
W5 (WLAN-Stabilisierung) wird auf ausdrücklichen Nutzerwunsch ausgelassen;
dies betrifft nicht M5 (Integration). M2 ist softwareseitig umgesetzt: eigener
PIO/DMA-Build, gemeinsame Protokolldefinitionen und 68000-HUNK-Diagnose.
[Prüfstand](results/2026-10-09-m2.md). Nutzer-SELFTEST mit 64 ECHOs bestanden;
Testsystem: Amiga 500 mit 68020, Kickstart 1.3 und Workbench 1.3.
Realer 68000-Lauf und aktive M2-Abnahme bleiben offen.
M0 bleibt vor aktiven Bustests erforderlich. M4 ist durch die vorhandene
Flashprofil-/Autoconnect-Basis vorbereitet; Amiga-Konfigurationskommandos und
die weitergehende Abnahme fehlen noch. M2-Hardwareabnahme sowie M5–M6 bleiben offen.

M1 und isolierte M3-Arbeiten können vor Abschluss M0 beginnen. M2-Bustests sind
von M0 abhängig; M5 benötigt M2–M4. Keine Kalenderzusage ohne verfügbares Muster,
Messungen und geklärten Resetpfad. Optimierung erfolgt nach funktionaler Abnahme.

Das Amiga-Diagnoseprogramm verwendet ausschließlich 68000-/V34-taugliche APIs,
reserviert die Parallelport-Ressourcen und stellt sie beim Beenden wieder her.
Es läuft zunächst exklusiv ohne SANA-II-Treiber; später greift das Prefs-Tool über
dessen Device-Schnittstelle zu. Beide dürfen nie gleichzeitig die CIA steuern.
Ein kleiner ARP/ICMP-Test verwendet eine explizit gewählte, freie Test-IP; ein
vollständiger TCP/IP-Stack wird nicht in das Diagnoseprogramm eingebaut.

### Vorbereitung ohne Trägerplatine (10.10.2026)

Der Nutzer hat noch keine FunkOtto-Trägerplatine zur Verfügung. M0-Messungen
sind deshalb noch nicht möglich; die zuvor beschriebene Messfolge ist eine
Anleitung, kein durchgeführter Test. Der einzelne Pico 2 W und der Amiga 500
mit 68020, Kickstart 1.3 und Workbench 1.3 stehen für getrennte Softwaretests
zur Verfügung. W5 bleibt ausgelassen.

Empfohlene Reihenfolge für die weitere Softwarearbeit; die folgenden Erweiterungen
waren zunächst geplant. Die Konfigurationsbefehle und der USB-Prüfzugang sind
inzwischen als eigenes Ziel `funkotto_m4_usb` softwareseitig umgesetzt;
[Umsetzungsplan](konfigurationsprotokoll-plan.md),
[Prüfstand](results/2026-10-10-m4-usb.md). Amiga-Client und SANA-II sind weiter offen:

1. **M4-Konfigurationsbefehle vorbereiten.** Gemeinsame Operationen für Status,
   Scan/Ergebnisse, RAM-Profil, Verbinden/Trennen sowie explizites Speichern/Löschen
   auf die bestehende W4-Basis aufsetzen. Binärformate, Versions-/Fähigkeitskennung,
   Auftragskennung und asynchrone Abschlussmeldung festlegen. Wiederholte
   Übertragung desselben Auftrags darf insbesondere keine erneute Flashoperation
   auslösen. M2-Diagnoseprotokoll und bestehende USB-Diagnose versioniert erhalten;
   neue Funktionen nur bei passender gemeldeter Fähigkeit verwenden.
2. **USB-Prüfzugang am einzelnen Pico.** Dieselben Kommandohandler über einen
   ausdrücklich aktivierten PC-Testtransport ansprechen, ohne Parallelportfreigabe.
   Vorhandene Konsole und WLAN-Profile erhalten. Längen-/Statusfehler, besetzte
   Auftragsqueue, Wiederholungen und veraltete Sitzungen prüfen. Passwörter niemals
   in Antworten, Konsolenlogs, Reports oder Testmitschnitten ausgeben; für
   Protokollmitschnitte ausschließlich synthetische Zugangsdaten verwenden.
3. **Amiga-Konfiguration zuerst als Shellprogramm.** 68000-/V34-kompatiblen Client
   mit austauschbarem Transport entwickeln. Ein expliziter Simulationsmodus
   erlaubt auf dem A500 Eingabe, SSIDs mit Leerzeichen, verdeckte Passworteingabe,
   Statusanzeige, Fehlerbehandlung und Abbruch zu testen, ohne CIA-Zugriffe.
   Er simuliert einen Adapter im Programm; damit ist noch keine Verbindung
   zwischen Amiga und USB-Pico hergestellt. Speichern/Löschen nur ausdrücklich.
   Danach kann die Intuition-Oberfläche auf derselben Clientlogik aufbauen.
4. **M5 und SANA-II vorbereiten.** Paket-/Konfigurationsschnittstelle, Pufferbesitz,
   Rückdruck und Fehlerabbildung mit simuliertem Transport prüfen. Anschließend
   Device-Grundgerüst und Request-/Abort-/Close-Lebenszyklen vorbereiten.
   Paketbenachrichtigung über ACK/CIA-Interrupt konzeptionell und in Simulation
   prüfen; die M2-Pollingdiagnose legt den späteren Treiberbetrieb nicht fest.
   Kein Durchsatz- oder Interrupt-Timingnachweis ohne Trägerplatine.

Abnahme dieser Vorarbeiten: PC/Pico-USB-Test und portfreier Amiga-Test werden
getrennt dokumentiert. M0 und die aktive M2-Abnahme bleiben offen. Sobald die
Platine vorliegt: Versorgung/Reset/Sperrzustände messen, danach kontrollierte
M2-Transfers und erst anschließend den vorbereiteten Konfigurationsclient über
den echten Parallelport testen. Diese Vorarbeiten ersetzen keine M5-Hardwareabnahme.

### Prüfmatrix

- Hosttests: Parser, CRC-Vektoren, Längengrenzen, abgeschnittene Rahmen,
  Duplikate, Sequenzüberlauf, Queue-Überlauf und simulierte Flashabbrüche.
- Hardware: beide Richtungen mit 00/FF/55/AA, Walking-Bit und Pseudozufallsdaten;
  mindestens 100.000 Transfers mit unterschiedlichen Längen und Langzeitlauf.
- WLAN: korrektes/falsches Passwort, fehlender AP, AP-Neustart, Funkverlust,
  nicht gespeichertes Profil und vollständiger Stromverlust.
- Reset: Amiga-Neustart während Kommando, Senden, Empfangen und Flashspeichern;
  beide Einschaltreihenfolgen sowie Pico-Neustart bei laufendem Amiga.
- Bootmessung: stabile Versorgung→erste Antwort, WLAN-Init, WLAN-Link und
  Amiga-Netzwerkbereitschaft getrennt; Minimum/Median/Maximum dokumentieren.
- OS-Test: echter 68000-Amiga mit OS 1.3. Emulator prüft ABI/Fehlerpfade,
  nicht das elektrische CIA-Timing.

Der vorhandene 8-Kanal-/24-MHz-Analysator kann Handshakeabläufe in mehreren
Messdurchgängen erfassen. Für Pegel, Überschwingen und genaue Flanken ist das
Oszilloskop nötig; eine digitale 24-MHz-Abtastung beweist keine analoge Signalgüte.

## 9. Geplante Repository-Ergebnisse

- `firmware/`: Build, Quellen und Boarddefinition.
- `protocol/`: freigegebene Protokollspezifikation und gemeinsame Definitionen.
- `amiga/diag/`: erstes Diagnose-/Konfigurationsprogramm.
- `tests/`: Hosttests, Prüfvektoren und Hardwaretest-Anleitungen.
- `docs/results/`: Messberichte mit Hardware-, Firmware- und Testumgebungsversion.
- `.github/workflows/`: reproduzierbare Builds und aussagekräftige Prüfungen.

Später: `amiga/device/` für SANA-II und `amiga/prefs/` für die OS-1.3-GUI.
Es werden keine Dummy-Treiber oder leeren Tests als fertige Funktionen ausgegeben.
Implementiert sind M1, WLAN W1–W4 sowie M2-Diagnoseprotokoll, PIO/DMA und
Amiga-CLI. SANA-II, Amiga-WLAN-Konfiguration, gemeinsame Integration und
weitergehende Hardwareabnahmen bleiben ausstehend.

## 10. Quellen und Referenzen

Technische Quellen geprüft am 05.10.2026. Vor Implementierung M1/M3 die tatsächlich
verwendeten SDK-/Treiberstände festschreiben; Beispiele ersetzen keine Messung.

- [Pico 2 W Datenblatt](https://datasheets.raspberrypi.com/picow/pico-2-w-datasheet.pdf)
- [Pico SDK: Netzwerk und CYW43](https://www.raspberrypi.com/documentation/pico-sdk/networking.html)
- [Pico SDK: Flash und Multicore](https://www.raspberrypi.com/documentation/pico-sdk/high_level.html)
- [CYW43-Treiber: Ethernet und Join](https://github.com/georgerobotics/cyw43-driver/blob/main/src/cyw43_ctrl.c)
- [Pico SDK Architekturdefinitionen](https://github.com/raspberrypi/pico-sdk/blob/master/src/rp2_common/pico_cyw43_arch/include/pico/cyw43_arch.h)
- [TI SN74LVC2G07: Open-Drain-Puffer, Ioff, Pinbelegung](https://www.ti.com/lit/gpn/sn74lvc2g07)
- Eigener PCB-Netzabgleich des Nutzerstands vom 08.10.2026 für die M1-Pinbelegung.
- [Festgelegter SDK-Stand und Werkzeuge](../firmware/dependencies.json).

Vor Wiederverwendung fremden Codes dessen Lizenz prüfen und Hinweise erhalten.
Dieser Plan entscheidet noch nicht über die Lizenz des späteren FunkOtto-Codes.

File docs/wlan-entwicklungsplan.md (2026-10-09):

# FunkOtto: Entwicklungsplan WLAN

Stand: 09.10.2026. Planung auf Grundlage von M1 (`ae67bce3b2dc`), Pico SDK 2.2.0
und dem unveränderten Nutzerboard. W1/W2 sind softwareseitig umgesetzt; Scan und erster WPA2-Join am Pico bestätigt.
Manuelles Wiederverbinden und automatische Erholung nach AP-Ausfall sind ebenfalls
am Pico bestätigt. Weitere Fehlerfälle und Dauerlauf bleiben offen.
[Implementierungsbericht](results/2026-10-08-wlan-w12.md) ·
[Testanleitung](../firmware/WLAN_TEST.md).

**Aktueller Beschluss (09.10.2026): W5 wird auf Wunsch des Nutzers ausgelassen.**
W1–W4 sind umgesetzt; Rohdatenübertragung und die W4-Grundfunktionen sind am
Pico bestätigt. W5 wird als übersprungen geführt, nicht als bestandener Test.
Der separate Stabilisierungsschritt einschließlich 24-h-Lauf und zusätzlicher
Treiberneustart-/Messarbeiten entfällt aus der aktuellen Umsetzung. Die bislang
nicht ausgeführten Tests bleiben im Prüfstand als ungetestet nachvollziehbar.
M2 (Amiga-Link) ist inzwischen softwareseitig umgesetzt;
[Prüfstand](results/2026-10-09-m2.md). Aktive Bustests setzen weiterhin M0 voraus. Die noch offenen erweiterten W4-Prüfungen werden separat geführt.

## Ziel und Ausgangspunkt

Der Pico soll WLAN-Netze finden, sich mit einem 2,4-GHz-WPA2-Personal-Netz verbinden,
Ethernet-Frames übertragen und später ein Profil dauerhaft speichern. Nach einem
Kaltstart oder Amiga-Hardware-Reset soll er damit automatisch erneut verbinden.
Die spätere IP-Konfiguration, DHCP, DNS und TCP/UDP übernimmt der Amiga-Stack.
Der Pico erhält für den normalen Betrieb keinen eigenen IP-Stack und arbeitet
mit einer Stations-MAC, die später auch der Amiga-Treiber verwendet.

Am 08.10.2026 hat der Nutzer USB-Diagnose und anschließend ausdrücklich den
Kaltstart ohne geöffnetes Terminal bestätigt. Beide Statusausgaben melden
`bus_locked=1`, `output_mask=0x00700000` und `watchdog_boot=0`.
[Nachweis und Grenzen](results/2026-10-08-firmware-m1.md).
Das bestätigt den Grundstart; Watchdog-Fehlerinjektion, elektrische Pegel und der
Resetpfad am Träger sind damit nicht gemessen.

Die WLAN-Stufen werden zunächst am einzelnen Pico über USB abgenommen. GP21/22
bleiben Low; GP0–11 und GP26 bleiben Eingänge. Die vorhandene Ausgangsmaske gilt
nur für die Adapter-GPIOs, nicht für die zusätzlich benötigten internen WLAN-Pins.
Die KiCad-Dateien bleiben unverändert. M0 sperrt weiterhin aktive Amiga-Bustests,
aber nicht isolierte WLAN-Arbeiten. M3 wird vor M2 begonnen; die USB-Teile von M4
können folgen, seine vollständige Amiga-Abnahme bleibt später erforderlich.

## Architekturentscheidung

Core 0 behält USB, Befehlsparser, sichere Adapter-GPIOs und die zentrale
Watchdog-Entscheidung. Core 1 besitzt WLAN-Zustandsautomat, CYW43-Treiber und
Ethernet-TX/RX. Aufträge, Ereignisse und Pakete werden über begrenzte Queues mit
klarer Pufferübergabe ausgetauscht. Keine CYW43-Aufrufe direkt aus der USB-Konsole;
keine USB-Ausgabe und kein Flash-Schreiben aus Empfangs-Callbacks.

Als Startarchitektur wird ein auf Core 1 initialisierter `async_context_poll`
mit CYW43 ohne lwIP gewählt. Die SDK-Arbeit wird dort regelmäßig ausgeführt;
zwischen Arbeiten wird auf Ereignis oder nächsten Termin gewartet. Dieses lokale
Pico-Polling erzeugt kein Amiga-Polling und legt dessen spätere IRQ-Strategie nicht fest.
Lange SDK-Aufrufe können Core 1 belegen: Initialisierung, Scan und Senden deshalb
messen; USB auf Core 0 darf dadurch nicht unbedienbar werden.

Besonderheiten des festgelegten SDK-Stands:

- `pico_cyw43_arch_none` benutzt einen Hintergrundkontext. Es ist kein fertiger
  Roh-Ethernet-Adapter: Standard-Callbacks für Link und Empfang können `panic`
  auslösen. Vor dem ersten Verbindungsversuch eigene Implementierungen für
  `cyw43_cb_tcpip_init/deinit`, `cyw43_cb_tcpip_set_link_up/down` und
  `cyw43_cb_process_ethernet` bereitstellen; Symbolauflösung im ELF prüfen.
- Das vorgefertigte Target `pico_cyw43_arch_poll` liegt in SDK 2.2.0 innerhalb der
  lwIP-Verfügbarkeitsbedingung. Für den geplanten Build ohne lwIP wird eine kleine
  projektlokale CMake-Verknüpfung aus `pico_cyw43_arch` und
  `pico_async_context_poll` mit `PICO_CYW43_ARCH_POLL=1`, `CYW43_LWIP=0` gebaut.
  Keine SDK-Quelldateien verändern. Dieser Build ist ein explizites W1-Prüftor.
- `LINK_UP` kommt aus dem authentifizierten STA-Link-Callback des Treibers.
  Ein bloß gestarteter Join oder ein TCP/IP-Status ohne IP-Adresse reicht nicht.
  Fehlerstatus und Linkverlust zusätzlich auswerten; Ereignisse einer alten
  Verbindung durch eine Sitzungskennung verwerfen.

Der Watchdog wird nur bei nachgewiesenem Fortschritt beider Kerne bedient.
Die reguläre Wiederverbindungswartezeit ist kein Stillstand: Core 1 arbeitet
weiter und liefert Lebenszeichen. Für WLAN-Initialisierung und Flash-Pausen
werden begrenzte, gemessene Sonderzustände vorgesehen. Kein dauerhaftes Füttern
allein aus einem Timer-IRQ. Die bestehende 8-s-Frist wird gegen die reale maximale
SDK-Blockierdauer geprüft, bevor sie für WLAN unverändert übernommen wird.

## Arbeitspakete und Abnahme

| Stufe | Umsetzung | Abnahme / Ergebnis |
| --- | --- | --- |
| W1 – Treiberbasis | CYW43-Abhängigkeit festlegen, Core 1, eigener SDK-Adapter und Callbacks, Initialisierung mit Länderkennung DE, MAC und Fehlerstatus | Neuer Build/CI bestehen; MAC gültig; USB ohne Terminal und bei Initialisierungsfehler bedienbar; Bus bleibt gesperrt |
| W2 – Scan und Verbindung | Asynchroner Scan, RAM-Profil, WPA2-Join, Status, Abbruch und Wiederverbindung | Reales Netz gefunden und authentifiziert; falsches Passwort/fehlender AP führen zu begrenzten Versuchen; AP aus/an erholt sich; USB bleibt bedienbar |
| W3 – Ethernet-Rohdaten | TX/RX-Adapter, feste Ringe, Längenprüfung, Zähler und USB-Testtransport | Rohframes in beide Richtungen mit LAN-Gegenstelle nachgewiesen; ARP/ICMP über den Testtransport; volle Puffer ohne Korruption |
| W4 – Dauerhaftes Profil | Zwei Flashsektoren, CRC/Sequenz/Commit, explizites Speichern/Löschen, automatischer Join nach Start | Kaltstart ohne USB-Konsole verbindet; unterbrochene Flashoperationen sind beherrscht; Profil bleibt beim normalen UF2-Update erhalten |
| W5 – Stabilisierung (**ausgelassen**) | Auf Nutzerwunsch vom 09.10.2026 kein eigener Umsetzungsschritt | Kein W5-Abnahmenachweis; kein vorgeschaltetes W5-Gate für M2/M5 |

**Erste auszuliefernde Test-UF2: W1 + W2.** Damit kann der Nutzer scan/connect/status
auf seinem einzelnen Pico prüfen. Zugangsdaten liegen dabei zunächst nur im RAM.
Erst nach erfolgreichem Rohframe-Nachweis W3 wird die dauerhafte Speicherung W4
freigegeben. Jede umgesetzte Stufe liefert Quellen, UF2, Manifest, Testanleitung und Bericht.

### W1: reproduzierbare Basis und Ressourcen

Den zum SDK gehörenden CYW43-Commit
`dd7568229f3bf7a37737b9e1ef250c26efe75b23` in `dependencies.json` ergänzen;
Bootstrap/CI und Manifest um Treiber- und Funkfirmware-Prüfsummen sowie benötigte
Lizenzhinweise erweitern. Bluetooth und lwIP bleiben ausgeschaltet. Den
bestehenden M1-Build als Diagnose-/Regressionstarget erhalten.

Vor und nach WLAN-Init Adapterpins prüfen. Interne CYW43-Pins GP23/24/25/29 gemäß
Pico-2-W-Boarddefinition nutzen; GP27/28 nicht zweckentfremden. Belegte PIO-Blöcke,
State Machines, DMA-Kanäle, IRQs, Timer, Flash, SRAM und beide Core-Stacks erfassen.
SDK-Ressourcen dynamisch reservieren, keine vermeintlich freien Nummern für den
späteren Parallelport fest eintragen. Belegungsfehler als Fehler melden.

### W2: Konfiguration und Wiederverbindung

Geplante USB-Bedienung (noch keine vorhandenen M1-Befehle):

| Befehl | Wirkung |
| --- | --- |
| `wifi status` | Zustand, gültige MAC, Link, RSSI soweit verfügbar, Fehler, Versuche und RAM/gespeichert-Status |
| `wifi scan` | Begrenzten Scan starten; Ergebnisliste mit SSID, BSSID, Kanal, RSSI und Authentifizierung |
| `wifi set` | Geführte Eingabe von SSID und Passwort; ausschließlich RAM ändern |
| `wifi connect` / `wifi disconnect` | Join starten beziehungsweise beenden und automatische Wiederholung stoppen |
| `wifi stats` | TX/RX, Drops, Queue-Höchststände und Linkwechsel |
| `wifi save` / `wifi erase` | Erst ab W4: ausdrücklich speichern beziehungsweise dauerhaft löschen |

SSID intern als Länge plus maximal 32 Bytes führen, Passwort zunächst als
8–63 Zeichen WPA2-Passphrase. Geführte Eingabe unterstützt Leerzeichen; zusätzlich
SSID als Hex-Bytes vorsehen, damit nicht druckbare Namen darstellbar bleiben.
Scan-Ausgaben sicher escapen, nie fremde Steuerzeichen ins Terminal übernehmen.
Versteckte SSIDs können manuell konfiguriert werden; ein Scan muss sie nicht finden.

Der bisherige 48-Byte-M1-Zeilenpuffer reicht für diese Eingaben nicht. WLAN-Konsole
mit eigenem begrenztem Puffer (zunächst 256 Bytes) und Zustandsparser ergänzen.
Überlange/ungültige Eingaben komplett verwerfen; kein Ausführen abgeschnittener
Reste. Passwort nicht zurücksenden, nicht in Status/Fehler/Logs aufnehmen;
Terminal-Lokalecho beim Eingeben ausschalten. Temporäre Kopien nach Nutzung
löschen. Keine echten Zugangsdaten in GitHub, Tests oder UF2 einkompilieren.

Zustände: `INITIALIZING`, `UNCONFIGURED`, `DISCONNECTED`, `CONNECTING`, `LINK_UP`,
`RETRY_WAIT`, `ERROR`; Scan läuft als gesonderter begrenzter Auftrag. Zunächst
höchstens 32 Scanergebnisse und 10 s Scanfrist, bei Überlauf sichtbarer Hinweis.
Scan während Join oder später unter Paketlast darf mit `BUSY` abgewiesen werden.

Join zunächst mit 15 s Frist; Wiederholung nach 1/2/4/8/16/30 s, danach maximal
30 s Abstand. Neue Konfiguration/Disconnect bricht alte Aufträge logisch ab.
`disconnect` unterdrückt automatische Versuche bis `connect` oder Neustart.
Fehlercode `BADAUTH` nur melden, wenn der Treiber ihn liefert; generischer Timeout
ist kein sicherer Beleg für ein falsches Passwort. Start mit gespeichertem Profil
verbindet automatisch, ohne Profil bleibt er bedienbar in `UNCONFIGURED`.
Energiesparen zunächst abschalten; Latenz und Verbrauch später gesondert bewerten.

### W3: Rohframes vor Amiga-Integration nachweisen

Stand 09.10.2026: als `funkotto_w3` implementiert, einschließlich USB-Testmodus,
PC-ARP/ICMP-Werkzeug und automatisierter Queue-/Protokolltests. **Reale ARP/ICMP-Tests
bestanden (12/12 und 1.000/1.000, MTU 1500, keine Verluste; JSON/PCAP geprüft)**.
AP-Ausfall mit Wiederverbindung und erneutem Pakettest ist vom Nutzer bestätigt.
Damit kann W4 als nächster Entwicklungsschritt beginnen. Langzeitbetrieb und
die Ursache einzelner Latenzausreißer bleiben offen: [Testablauf](../firmware/W3_TEST.md),
[Prüfstand](results/2026-10-09-w3.md). W4 beginnt nach dem realen Rohframe-Nachweis.

TX über `cyw43_send_ethernet(..., is_pbuf=false)`, RX über den eigenen Callback.
Die unteren Treiberfunktionen hinsichtlich Kopieren/Übernahmedauer prüfen:
TX-Puffer erst nach bestätigter Übernahme freigeben; RX-Daten vor Callback-Ende
in eigenen Speicher kopieren. Callback führt keine Warteoperation und keinen
rekursiven Sendebefehl aus. STA-Eingang und Paketlänge vor dem Kopieren prüfen.

Anfangs je acht 1600-Byte-Puffer für TX/RX: 25.600 Byte Nutzspeicher plus Metadaten.
Ungetaggte Frames bis 1514 Bytes ohne FCS, MTU 1500. Ethernet-Mindestlänge/Padding
mit dem konkreten Treiber nachweisen. TX voll ergibt `BUSY`; RX voll verwirft
gezählt. Keine ungelesenen Pakete überschreiben. Bei Linkwechsel alte Aufträge
und Pakete definiert beenden; erfolgreiches SDK-Senden bedeutet keine bestätigte
Zustellung bei der Gegenstelle. Broadcast für ARP/DHCP einplanen und testen.

Ein PC-Testwerkzeug nutzt eine explizit aktivierte gerahmte USB-Diagnosesitzung
mit Typ, Länge, Sequenz und CRC. In diesem Modus keine ungerahmten Textausgaben
zwischen Paketen; Binärdaten nicht durch den Kommandozeilenparser leiten.
Der PC erzeugt ARP/ICMP-Testframes mit Stations-MAC und freier Test-IP; der Pico
transportiert sie unverändert. Eine zweite LAN-Gegenstelle beantwortet/mitschneidet
sie. AP-Client-Isolation ausschließen oder als Umgebungsfehler dokumentieren.
Beide Richtungen durch Sequenzen/Nutzdatenvergleich und Mitschnitt belegen.
Dieser USB-Test ist kein SANA-II-Ersatz und kein Amiga-Durchsatzbenchmark.

### W4: Speichern und Autoconnect

Stand 09.10.2026: implementiert als `funkotto_w4`, einschließlich Journal,
Löschdatensatz/Bereinigung, SDK-Flashsperre und Boot-Autoconnect.
[Bedienung/Hardwaretest](../firmware/W4_TEST.md) · [Prüfbericht](results/2026-10-09-w4.md).
Ein realer Status bestätigt ein gültiges gespeichertes Profil und `LINK_UP`.
Der erste Kaltstart mit automatischer Wiederverbindung wurde vom Nutzer
ausdrücklich als bestanden bestätigt. Auch der Löschtest im beschriebenen
Neustartablauf und die erneute Einrichtung/Verbindung/Speicherung sind durch Nutzerstatus
belegt. Wiederholte Kaltstarts und die übrige Hardwareabnahme bleiben offen.

Bestehendes Layout behalten: Profil A bei Flashoffset `0x003FE000`, Profil B
bei `0x003FF000`, je 4096 Byte; Firmware vor XIP `0x103FD000` begrenzen und den
separaten E10-Sektor schützen. UF2-/Linkerprüfungen auf die WLAN-Ziele erweitern.

Datensatz mit Schema, Längen, Authentifizierung, Land, SSID/Passphrase, Sequenz,
CRC32 und zuletzt geschriebenem Commit-Marker. Inaktiven Sektor verwenden;
vor Erfolg zurücklesen und prüfen. Bei Start neuesten gültigen Stand wählen,
auch bei Sequenzüberlauf; unbekanntes Schema als inkompatibel melden. Beschädigte
oder leere Profile erzeugen `UNCONFIGURED`, keine Bootschleife.

Speichern ausschließlich nach `wifi save`, nicht bei jedem Reconnect. Vor
Flashoperation beide Kerne und alle XIP-lesenden DMA-Zugriffe koordiniert
anhalten; SDK-Flash-Sicherheitsmechanismen passend zur Multicore-Architektur
initialisieren und prüfen. WLAN darf dafür sichtbar getrennt und danach wieder
verbunden werden. Keine Locks halten, die den angehaltenen Kern benötigen.
Fehlende Ruhebestätigung beendet den Auftrag ohne Flashänderung.

Löschen zuerst durch jüngeren gültigen Löschdatensatz absichern, dann alte
Geheimnisse entfernen. Nach Unterbrechung darf das ältere Profil nicht erneut
aktiv werden; Bereinigung beim Start fortsetzen. Erfolg erst nach Bereinigung.
Profile sind unverschlüsselt im Flash; Schutz vor Verlust ist keine Verschlüsselung.

## Prüfprogramm und Fertigkriterien

Automatisiert: Zustandsübergänge mit simuliertem Treiber und Zeit, Scan-/Parsergrenzen,
Queue-Überlauf, stale Ereignisse, Heartbeat-Ausfall, CRC, Sequenzüberlauf sowie
Stromausfallmodell an jeder Schreib-/Löschphase. Buildprüfungen: echte Callback-
Symbole, kein lwIP/UART, reservierte Flashbereiche und unveränderte Pinzuordnung.

Am Pico: korrektes/falsches Passwort, kein AP, AP-Neustart, Funkverlust,
Disconnect/Connect, USB ab/an, Betrieb ohne Terminal, Scanabbruch, volle Ringe,
Linkwechsel unter Last und absichtlicher Core-1-Stillstand für Watchdog-Nachweis.
WLAN-Initzeit, Joinzeit, Reconnectzeit und USB-Antwortlatenzen getrennt messen;
`safe_init_us` bleibt ausschließlich ein interner Timerstand.

W4-Abnahme: 100 Kaltstarts mit gültigem Profil, zusätzliche gezielte
Stromunterbrechungen in den Flashphasen und normaler BOOTSEL-Update-Test mit
anschließendem Profilvergleich. Elektrische RUN-/Amiga-Resettests erst am
abgenommenen Träger nachholen. Der ursprünglich für W5 vorgesehene 24-h-Test
mit bidirektionalem Paketverkehr, Verlust-/Korruptions- und Reset-Auswertung
wird gemäß Nutzerentscheidung ausgelassen und gilt nicht als bestanden.
Realtests werden durch Nutzerprotokolle bestätigt, nicht aus CI-Erfolg abgeleitet.

Mit W1–W4 sind WLAN und USB-Konfiguration separat nutzbar; W5 wird ausgelassen. Zur vollständigen
FunkOtto-v0.1 fehlen weiterhin M0, Amiga-Link, dessen Konfigurationsbefehle und
Integration; SANA-II und OS-1.3-Oberfläche bleiben eigene Folgepakete.

## Geplante Dateien und überprüfte Quellen

Module: `firmware/src/wifi.c`, `wifi_sdk.c`, `ethernet.c`, `config.c` und zugehörige
Header; Tests mit Treiber-/Flash-Mocks; `tools/wifi_diag.py` für die PC-Abnahme.
WLAN-Ziele und Manifest neben M1; Schnittstellen so anlegen, dass USB und später
Amiga dieselben Konfigurations-/Paketoperationen aufrufen.

Quellen geprüft am 08.10.2026; Architekturentscheidungen oben sind Projektplanung:

- [SDK-Netzwerk-API](https://www.raspberrypi.com/documentation/pico-sdk/networking.html).
- [SDK 2.2.0 CMake-Targets](https://github.com/raspberrypi/pico-sdk/blob/a1438dff1d38bd9c65dbd693f0e5db4b9ae91779/src/rp2_common/pico_cyw43_arch/CMakeLists.txt).
- [SDK-Callbacks ohne lwIP](https://github.com/raspberrypi/pico-sdk/blob/a1438dff1d38bd9c65dbd693f0e5db4b9ae91779/src/rp2_common/pico_cyw43_driver/cyw43_driver.c).
- [Festgelegter CYW43-Stand: Join, Link-Ereignisse und Ethernet-TX](https://github.com/georgerobotics/cyw43-driver/blob/dd7568229f3bf7a37737b9e1ef250c26efe75b23/src/cyw43_ctrl.c).
- [Pico-2-W-Pinbelegung des SDK](https://github.com/raspberrypi/pico-sdk/blob/a1438dff1d38bd9c65dbd693f0e5db4b9ae91779/src/boards/include/boards/pico2_w.h).

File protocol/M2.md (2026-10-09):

# M2: Diagnoseprotokoll v1, Profil B1536

Stand 09.10.2026. Implementierte Bring-up-Spezifikation; elektrische Zeiten und
Oszillogramme sind noch nicht am Nutzerboard bestätigt. M2 ist ein eigener Build
ohne WLAN. Das spätere Ethernet-/SANA-II-Protokoll und Blockoptimierungen werden
in M5 darauf aufgebaut. W5 bleibt gemäß Nutzerentscheidung ausgelassen.

## Signalvertrag

| Signal | Pico | Amiga | Verwendung in M2 |
| --- | --- | --- | --- |
| D0–D7 | GP0–7 | CIAA PRB `$BFE101`, DDRB `$BFE301` | Halbduplex-Daten |
| STROBE_N | GP8 Eingang | CIAA PC, automatisch bei PRB-Zugriff | Ein Impuls pro geschriebenem **oder gelesenem** Byte |
| SEL | GP9 Eingang | CIAB PRA `$BFD000`, Bit 2 | 0 Empfang des Pico, 1 Antwort/Synchronisation |
| BUSY | GP10 Ausgang | CIAB PRA Bit 0 | Dauerhaftes alternierendes Quittungsbit, **kein kurzer Puls** |
| POUT | GP11 Ausgang | CIAB PRA Bit 1 | Bestätigung der Phase / Antwort vorgeladen |
| ACK_N | GP26 Ausgang | CIAA FLAG | Bleibt High; in dieser Polling-Diagnose kein IRQ |
| DATA_DIR | GP20 | Translator U2 | 1 Amiga→Pico, 0 Pico→Amiga |
| FW_DATA_EN / FW_CTRL_EN | GP21 / GP22 | OE-Gating U5/U6 | Beim Boot aus; Richtung nur mit DATA_EN=0 ändern |

BUSY beginnt in jeder Datenphase bei 0 und wechselt nach jedem Byte. Der Host
wartet immer auf den **anderen** Wert; ein verpasster kurzer Puls ist damit kein
Problem. POUT ist bei Empfang 0, bei vorgeladener Antwort 1. Die Datenrichtung ist
eine Vereinbarung beider Seiten, keine automatische Erkennung der CIA-DDRB.
Der Host muss die unten angegebene Reihenfolge einhalten.

### Synchronisation und Empfang

1. Host reserviert `MR_PARALLELPORT=2` und `MR_PARALLELBITS=3` exklusiv über
   `misc.resource`. BUSY/POUT sind Eingänge, SEL Ausgang. Timer-PB-Ausgabe und
   CIAB-Serial-Ausgabe werden bei Konflikt abgewiesen, nicht umprogrammiert.
2. Host setzt **DDRB=0**, dann SEL=1 und wartet auf POUT=1. Der Pico bestätigt
   ohne Datenausgabe, außer eine bereits angeforderte Antwort liegt vor. Auch
   dann sind die Host-Datenpins bereits Eingänge.
3. Host setzt SEL=0 und wartet auf **POUT=0 und BUSY=0**. Vor dieser Bestätigung
   sperrt der Pico U2, leert alte PIO-/DMA-Zustände, stellt auf Empfang um und
   startet RX-DMA. Erst danach darf der Host DDRB=255 setzen.
4. Genau 1536 PRB-Schreibzugriffe. Nach jedem Zugriff den BUSY-Wechsel abwarten,
   POUT muss 0 bleiben. RX-PIO liest bei STROBE Low, wartet auf High und schiebt
   das Byte in den FIFO. Erst ein erfolgreicher PUSH wird quittiert.
5. Die feste Blockgröße begrenzt DMA und Parser. Ein volles FIFO verzögert die
   Quittierung; kein ungeprüftes Kopieren und kein Überschreiben des Empfangsblocks.

### Richtungsübergabe und Antwort

1. Nach der letzten Schreibquittung setzt der Host **DDRB=0 vor SEL=1**.
2. Nur ein gültiger Request kann eine Antwort auslösen. Vor der ersten Sitzung
   muss er ein gültiges HELLO sein. Der Pico sperrt U2 und stellt die PIO-Pins
   auf Ausgabe um. TX-DMA lädt das erste Byte; PIO-IRQ-Flag 0 bestätigt das
   Vorladen. DATA_DIR wird 0, eine interne Wartezeit von 2 µs folgt, SEL wird
   erneut geprüft. Danach werden U2 und POUT freigegeben.
3. Host wartet auf POUT=1/BUSY=0. Der **erste** PRB-Lesezugriff liest bereits das
   erste Antwortbyte; kein Dummy-Zugriff. Sein nachlaufender STROBE quittiert
   die Übernahme. PIO wartet auf STROBE High, lädt das nächste Byte und wechselt
   dann BUSY. Host wartet vor jedem weiteren Lesen auf diesen Wechsel.
4. Nach Byte 1536 wechselt BUSY ein letztes Mal, PIO setzt IRQ-Flag 1 und hält
   das letzte Byte. **DMA-Fertig allein ist keine letzte Bytequittung.**
5. Host setzt SEL=0, weiterhin DDRB=0. Pico sperrt U2 vor jeder Richtungsänderung
   und bestätigt den erneuten Empfang erst mit POUT=0/BUSY=0.

PIO IRQ-Flags werden vom Pico-Hauptloop abgefragt; es gibt keine CIA-ACK-Interrupts
und keinen SANA-II-Interrupt-Handler in M2. Polling ist hier ausschließlich für
das Diagnoseprogramm vorgesehen, nicht als Architekturentscheidung für SANA-II.

## Fehler, Abbruch und Zeitgrenzen

- Standard-UF2: `FUNKOTTO_M2_ACTIVE=OFF`, beide Bustreiber dauerhaft gesperrt.
- Labor-Build: zunächst ebenfalls gesperrt; erst `link arm M0-VERIFIED` erlaubt
  den Steuerpfad. `link lock` sperrt Daten zuerst und gibt PIO/DMA wieder frei.
- Pico: 2 s ohne DMA-Fortschritt, maximal 10 s je Übertragungsphase. Es wird
  immer zuerst DATA_EN deaktiviert; danach DMA abbrechen, FIFOs leeren,
  GPIO-Datenpins Eingänge, Richtung Empfang. Fehlerzustand: BUSY=1/POUT=0.
- Teilrahmen, CRC-/Paddingfehler oder vorzeitiger Phasenwechsel verwerfen die
  Sitzung. Neue Synchronisation und HELLO sind nötig. Eine vollständig gelesene
  Antwort erhält beim normalen Richtungswechsel die Sitzung.
- Host: Zeitlimit von 120 CIAA-TOD-Ticks (2 s NTSC, 2,4 s PAL), 24-Bit-Wrap
  berücksichtigt; Ctrl-C in jeder Wartephase. Eine zusätzliche Iterationsgrenze
  verhindert endloses Warten bei stehendem TOD. Sie dient nicht zur Kalibrierung.
- Cleanup fordert erneut Empfang an. Nur nach dessen Bestätigung werden DDRB
  und die gespeicherten Portwerte restauriert. Ohne Bestätigung bleiben Daten
  und die drei Statusleitungen Eingänge. Oberste fünf CIAB-PRA/DDRA-Bits werden
  atomar erhalten, damit serielle Leitungen anderer Software nicht zurückgesetzt
  werden. Bei vorherigen Eingängen ist nur der gelesene Pinwert bekannt, nicht
  ein verborgener Ausgangslatch. Ressourcen werden auch im Fehlerfall freigegeben.
- Elektrischer Amiga-Reset setzt den Pico über RUN zurück. Softwareabbruch
  resynchronisiert über SEL. Keine Zustellgarantie über Stromverlust hinweg.

## Rahmen und Befehle

Jede Richtung überträgt exakt **1536 Bytes**, auch bei leerem ECHO. Das ist ein
bewusst einfaches Diagnoseprofil, noch kein Durchsatzbenchmark.

| Offset | Länge | Inhalt |
| --- | --- | --- |
| 0 | 2 | Magic `41 57` |
| 2 | 1 | Version 1 |
| 3 | 1 | Opcode, bei Antwort Bit 7 gesetzt |
| 4 | 2 | Payload-Länge 0…1518, big endian |
| 6 | 2 | Sequenz, big endian |
| 8 | n | Payload |
| 8+n | 2 | CRC16/CCITT-FALSE über Header+Payload, big endian |
| 10+n | Rest | Nullpadding bis 1536; ebenfalls auf Null geprüft |

CRC: Polynom 0x1021, Start 0xffff, keine Reflexion, kein finales XOR;
`123456789` → `29b1`. Alle Mehrbytefelder werden byteweise verarbeitet, auch an
ungeraden Adressen des 68000. C-Strukturen werden nicht auf den Bus kopiert.

| Opcode | Request-Payload | Erfolgreiche Antwort-Payload |
| --- | --- | --- |
| 1 HELLO | 8-Byte-Hostnonce, Sequenz 0 | Status(1), Nonce(8), Sitzung(4), Version(1), ECHO-Maximum(2)=1500, Blockgröße(2)=1536 |
| 2 GET_INFO | Sitzung(4) | Status(1), Sitzung(4), ASCII `FunkOtto M2` ohne NUL |
| 3 ECHO | Sitzung(4), 0…1500 Nutzbytes | Status(1), Sitzung(4), identische Nutzbytes |
| 4 LINK_RESET | Sitzung(4) | Status(1), bisherige Sitzung(4); danach HELLO erforderlich |

Status: 0 OK, 1 falsche Sitzung, 2 falsche Sequenz, 3 unbekannter Befehl,
4 falsche Payload-Länge. Sitzungs-/Sequenzfehler haben nur das Statusbyte als
Payload und ändern die erwartete Sequenz nicht. Gültige erwartete Befehle,
einschließlich UNSUPPORTED/LENGTH-Antworten, verbrauchen ihre Sequenz.
HELLO setzt die nächste Sequenz auf 1; danach modulo 65536.

Eine byteidentische Wiederholung des letzten Auftrags liefert die gespeicherte
Antwort. Gleiche Sequenz mit anderem Inhalt wird abgelehnt. Nichtidentisches
HELLO erzeugt eine neue Sitzung; Abbruch verwirft den Replay-Cache. Sitzungen
haben einen zufälligen 32-Bit-Startwert pro Boot und einen laufenden Zähler;
sie sind ein Schutz gegen alte Transfers, keine Authentifizierung.

## Ressourcen und Nachweise

Ein freier PIO-Block wird dynamisch gewählt und komplett reserviert (vier SMs
beansprucht, SM0 benutzt, 30/32 Instruktionen, Flags 0/1). Zwei freie DMA-Kanäle
werden dynamisch reserviert. Bei Teilfehler werden beide Ressourcenarten
zurückgegeben. Es gibt keine festen DMA-Nummern und keine Allokation pro Frame.
RX/TX verwenden je 1536 32-Bit-Wörter; Byteblöcke und Replay-Cache sind statisch.
Core-0-Stack 4096 Bytes. WLAN/Flashschreiben sind im M2-Ziel nicht eingebunden.
Die spätere gemeinsame Ressourcen-/Flashkoordination gehört zu M5.

Tests: [Prüfbericht](../docs/results/2026-10-09-m2.md).
Die PIO-Instruktionstests prüfen logische Abläufe, keine analogen Pegel oder
Amiga-Zeiten. Für belastbare Freigabe fehlen reale Oszillogramme, RUN/OE-Messungen
und Transfers auf 68000/OS 1.3.

Primärquellen: Commodore Hardware Reference Manual,
[8520: Register und PC/FLAG-Handshake](https://www.theflatnet.de/pub/cbm/amiga/AmigaDevDocs/hard_f.html),
[Exec Resources](https://wiki.amigaos.net/wiki/Exec_Resources),
sowie die lokalen PIO-/DMA-Header des festgelegten Pico SDK 2.2.0 und der
[Pinvertrag](../docs/firmware-v0.1-plan.md). Bibliotheksvektoren und OS-Strukturen
im Amiga-Startcode bleiben zusätzlich am echten V34-System zu prüfen.

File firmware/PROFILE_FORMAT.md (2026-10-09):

# W4 profile journal, schema 1

Two fixed 4096-byte sectors on the Pico 2 W's 4 MiB flash:

| Slot | Flash offset | XIP address |
| --- | --- | --- |
| A | 0x003fe000 | 0x103fe000 |
| B | 0x003ff000 | 0x103ff000 |

Application ends below 0x103fd000; RP2350-E10 has its own sector at
0x103fd000..0x103fe000. UF2 validation prohibits application writes into both
areas except the explicitly checked E10 compatibility block at 0x103fdf00.
Only W4 includes the journal writer. No filesystem, dynamic packet allocation,
encryption or flash write on ordinary connection/retry.

## Stable envelope

Each sector contains a 256-byte data page and a separate 256-byte commit page;
the remaining 3584 bytes must be 0xff. Multibyte fields use big endian.
CRC32 uses the ISO-HDLC polynomial, initial/final XOR all ones.

| Data page offset | Bytes | Meaning |
| --- | --- | --- |
| 0 | 4 | ASCII FOP4 |
| 4 | 2 | Payload schema = 1 |
| 6 | 1 | Kind: 1 profile, 2 delete tombstone |
| 7 | 1 | Auth: 1 WPA2 AES PSK; tombstone 0 |
| 8 | 4 | Sequence modulo 2^32 |
| 12 | 2 | Country DE |
| 14 | 1 | SSID length 1..32; tombstone 0 |
| 15 | 1 | Passphrase length 8..63 printable ASCII; tombstone 0 |
| 16 | 32 | SSID bytes, unused bytes 0xff; embedded zero allowed |
| 48 | 63 | Passphrase bytes, unused bytes 0xff |
| 111 | 141 | 0xff |
| 252 | 4 | CRC32 of data bytes 0..251 |

For tombstones bytes 16..251 are all 0xff, with no credentials.
Commit page: ASCII FOCM at 0, sequence at 4, data-page CRC at 8, bitwise inverse
of sequence at 12, bytes 16..255 all 0xff. The meaningful commit occupies its
first 16 bytes; no second programming of the data page is needed. Commit page
is only programmed after full erase verification and data-page readback.

The envelope remains fixed for future payload schemas. An intact envelope
with unsupported schema/kind/auth/country can participate in sequence selection
but is never used as credentials. If newest, it blocks autoconnect and normal
save until explicit erase. Invalid CRC/commit/length/padding is ignored;
fall back to the other valid slot. Neither valid: EMPTY if both sectors are
all 0xff, otherwise CORRUPT, with no credentials or automatic connection.

For two valid records, A is newer than B iff unsigned (A.seq-B.seq) is in
1..0x7fffffff. Equal or exactly half-range-separated sequences are AMBIGUOUS,
fail closed and block normal save. A tombstone is a record and participates in
the same ordering. This handles normal sequence wrap without preferring stale data.

## Save and delete

Save uses the other sector and next sequence: erase, verify all 0xff, program
data, compare, program commit, compare, reload and select the new record.
The previous valid slot is retained as fallback. Saving identical logical
credentials performs no erase/program. Current service still quiesces WLAN
for the command. Caller profile is private model RAM and must not alias the
journal cache, which is wiped and reloaded during operations.

Delete first commits a newer credential-free tombstone in the other sector,
then erases/verifies the old sector. Before the tombstone becomes valid, an
interrupted operation may retain the old profile; do not report success yet.
Once tombstone is valid, an interrupted old-sector erase must never reactivate
that profile. Boot reloads the tombstone, retries old-sector cleanup and stays
unconfigured even if cleanup fails. It does not erase the last tombstone.
A later explicit save may supersede it.

Explicit delete can also recover incompatible/ambiguous records. For ambiguous
selection overwrite slot A with a tombstone immediately newer than slot B's
intact envelope, then clean B. For no intact envelope use sequence 1. This is
an intentional user erase, never an automatic boot-time format/migration.
Success is emitted only after readback and old-secret cleanup. Failed SDK exit
may mean a write already completed; reload current contents, retain an error
and do not claim success. Repeating save/delete is safe and bounded.

## Pico flash exclusion

Core 0 calls `flash_safe_execute_core_init` before launching Core 1. The pinned
SDK launch temporarily disables the FIFO IRQ during its boot handshake. Core 1
also initializes flash safety before storage work. The SDK multicore-lockout
backend is explicitly enabled; no ASSUME_CORE_SAFE shortcut is used.

Only Core 1 writes. It disconnects the WLAN model, deinitializes CYW43, closes
raw packet queues, then opens the flash window with no cross-core lock held.
Every operation checks locked Amiga pins, initialized Core-0 victim and **all
DMA channels neither claimed nor busy**. Core 0 has no DMA user in this stage.
Unknown DMA activity rejects the request instead of aborting another peripheral.

`flash_safe_execute` parks Core 0 in the SDK SRAM handler and disables local
interrupts before the callback. Entry/exit timeout is 1000 ms; callback is not
called after failed entry. The RAM callback uses only SDK RAM/ROM erase/program
functions and aligned SRAM data buffers, never USB/CYW43/logging. Each operation
releases the exclusion before readback. The existing hardware watchdog remains
active; no unbounded watchdog-feed loop is added. Real erase/program duration,
USB pause and reset behavior still need hardware verification.

At boot only journal reads and, when a valid tombstone requires it, cleanup run
before driver initialization. A valid profile is copied into the private WLAN
model and starts the existing retry state machine without waiting for USB.
Invalid/unsupported storage has no automatic write, no profile and no boot loop.
The public status contains SSID, flags, sequence and errors, never passphrase.
`stored` compares RAM with committed profile; `flash_profile` reports existence.

## Verification boundary

Host tests model interruption at every byte boundary of NOR erase/program for
save and delete, then recreate boot state. This is not a physical brownout model
or proof of all real flash failure modes. CRC32 is corruption detection, not
authentication. Deliberate mutation, physical flash damage and forensic secret
recovery are outside this journal's guarantees. Real cold starts, interrupted
operations and profile-preserving UF2 update remain hardware acceptance items.

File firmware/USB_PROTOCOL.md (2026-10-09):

# FunkOtto W3 USB raw protocol v1

Development/test protocol, not the later parallel-port ABI. One CDC interface;
ASCII `raw on\n` explicitly enters binary mode. DTR low exits, flushes the
packet queues and restores the console without clearing the WLAN profile.
SDK and console stdio output is disabled during binary mode. Binary I/O uses
the SDK USB driver's mutex-protected byte functions, bypassing CRLF conversion.

Each message is `00 COBS(decoded-message) 00`. Repeated zero delimiters are
ignored. Encoded messages are bounded to 1543 bytes, decoded to 1535 bytes.
Oversize/bad COBS/header/CRC messages are discarded without side effects.
Both ends resynchronize at the next delimiter. No unsolicited binary messages.

All multibyte fields use network byte order; no packed C struct is transmitted.

| Offset | Bytes | Meaning |
| --- | --- | --- |
| 0 | 1 | Version = 1 |
| 1 | 1 | Type; response has bit 7 set |
| 2 | 2 | Payload length, max 1515 |
| 4 | 4 | Sequence, starts at 1; never wraps in a session |
| 8 | 8 | Random nonzero session ID |
| 16 | length | Payload |
| 16 + length | 4 | CRC-32/ISO-HDLC over header + payload; same as Python zlib.crc32 |

The Pico generates a fresh session ID when `raw on` is processed. First request
is HELLO, seq=1, session=0, empty payload. Response contains the real session ID.
Every subsequent request uses that ID and the next sequence number. Host allows
one outstanding request. Same sequence and **identical complete request bytes**
replay the cached response; a pending TX replay waits for the same completion.
Same sequence with altered content, an old/future sequence or a different request
while TX is pending returns SEQUENCE without advancing state. Wrong session
returns SESSION. Sequence 0 is invalid. Reopen the session before sequence wraps.

A missing/truncated response is retried with exactly the same request. The client
uses four attempts, two seconds each by default. After final timeout or changed
session, report unknown TX outcome and close the session; never blindly submit
that packet as a new request. SDK writes have a 10 ms no-progress limit; missing
USB bytes are detected by framing/CRC and recovered through response replay.

| Request type | Request payload | Response payload |
| --- | --- | --- |
| 1 HELLO | empty | status u8, station MAC 6 bytes, link u8, max frame u16=1514, slot count u8=8, epoch u32 |
| 2 STATS | empty | status u8, link u8, TX used u8, RX used u8, epoch u32, 16 counters u32 |
| 3 TX | Ethernet frame, 14..1514 bytes, no FCS | status u8, signed SDK error i32; response after SDK returns or request aborts |
| 4 RX | empty | status u8, then Ethernet frame only when OK |

Status values: 0 OK, 1 EMPTY, 2 BUSY, 3 NO_LINK, 4 INVALID, 5 ABORTED,
6 DRIVER, 7 PENDING (internal only), 8 SESSION, 9 SEQUENCE. Protocol errors use
a one-byte status payload. Unknown commands/payload lengths return INVALID.

STATS counter order: tx_queued, tx_ok, tx_error, tx_aborted, tx_busy, tx_invalid,
rx_queued, rx_full, rx_inactive, rx_invalid, rx_flushed, tx_high_water,
rx_high_water, bad_frames, replays, sequence_errors. All counters wrap modulo
2^32. Ethernet counters persist for the boot; protocol counters reset per session.
Link epoch comes from the WLAN state machine. The test client rejects a completed
run if its final epoch differs from HELLO, and a new run is required after loss.

## Packet and ownership contract

- Ethernet II only; EtherType >= 0x0600. VLAN 0x8100/0x88a8 and EAPOL 0x888e
  are rejected; CYW43 owns authentication. No VLAN/802.3 LLC/FCS support.
- TX source MAC must equal the station MAC. Destination may be unicast,
  multicast or broadcast. Short frames are zero-padded to 60 bytes.
- Eight TX and eight RX slots each own a 1600-byte buffer; accepted wire frame
  maximum remains 1514. No per-packet allocation.
- Core 0 submits copies; Core 1 claims the oldest TX and copies to its private
  staging buffer. The cross-core critical section is released before the SDK
  call. The pinned CYW43 `cyw43_ll_send_ethernet` copies into `spid_buf` before
  returning; `is_pbuf=false`. Staging storage is reusable after return.
- RX callback checks interface, pointer/type/length and copies into owned memory
  before returning. It performs no SDK call, logging, sleep or flash operation.
  Only a short memory-copy critical section protects the cross-core queues.
- TX completion remains in its slot until consumed, so completion records cannot
  overflow independently. SDK success means accepted, not delivered/acknowledged
  by the peer. The peer's matching ICMP reply supplies end-to-end evidence.
- RX full drops the new frame, increments rx_full, never overwrites an older one.
  Frames arriving outside an active session/link are counted and discarded.
- Link down/epoch change flushes RX and marks queued/inflight TX ABORTED. No old
  queued packet is automatically retransmitted after reconnect. A packet already
  handed to CYW43 cannot be recalled. Late SDK completion cannot overwrite an
  aborted/reused slot. New USB sessions discard all old queue/completion state.
- Replaying a cached successful RX/TX response reports the original operation's
  result, even if the link has since changed; it does not dequeue/transmit again.
  Check link epoch separately, and start a new test after a link change.
- USB is stop-and-wait and RX is host-pulled. This protocol measures functionality,
  not maximum radio throughput or the future Amiga parallel-port performance.

The pinned CYW43 raw-send implementation retains a link-time reference to
`pbuf_copy_partial` even with `CYW43_LWIP=0`. `cyw43_no_lwip.c` supplies a fatal
guard for this unreachable branch; it does not emulate pbuf or add lwIP. An
accidental `is_pbuf=true` call stops the service and the watchdog resets it.
Core 0 retains the SDK's 4 KiB scratch-bank stack; packet-sized protocol
workspaces are static. Core 1 uses the existing explicit 8 KiB SRAM stack.

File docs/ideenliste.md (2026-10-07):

# FunkOtto – Ideenliste

Hier sammeln wir neue Einfälle und Erweiterungswünsche fortlaufend.
Ein Eintrag ist zunächst eine Idee; die Umsetzung wird später gesondert entschieden.
Neue Ideen erhalten eine fortlaufende ID und ein Datum. Bestehende Einträge werden
bei Bedarf ergänzt; ihr Status bleibt nachvollziehbar.

## IDEA-001 – Nachrüstbare Traffic-LED

- **Aufgenommen:** 07.10.2026
- **Status:** Vorgemerkt
- **Zeitpunkt:** Später, wenn die Grundfunktion zuverlässig läuft
- **Ziel:** Gesendete und empfangene Netzwerkpakete sichtbar anzeigen.

### Mögliche Umsetzung

Eine externe LED mit Vorwiderstand an einem freien Pico-GPIO anschließen.
Im geprüften Hardwarestand Rev B1 sind **GP27 / Modulpin 32** und
**GP28 / Modulpin 34** frei und im Trägersockel vorhanden.

Vorschlag für eine gemeinsame TX/RX-Anzeige:

- GP27 / Pin 32 über beispielsweise 1 kΩ zur Anode einer roten LED.
- LED-Kathode an GND, beispielsweise Modulpin 38.
- Nachrüstung über angelötete Leitungen; später optional eigener LED-Anschluss
  in einer neuen Boardrevision.
- Firmware steuert die Anzeige anhand der Paketaktivität.
- Kurze Ereignisse auf etwa 50 ms sichtbar verlängern, ohne blockierende
  Wartezeiten im Datenpfad; bei hoher Last die Anzeige zeitlich begrenzen.

**Variante:** Zwei getrennte LEDs für TX und RX an GP27 und GP28.

### Bei Umsetzung festzulegen

- Gemeinsame Traffic-Anzeige oder getrennte TX/RX-Anzeige.
- Welche tatsächlich übertragenen Pakete den Impuls auslösen.
- LED-Typ, Helligkeit und passender Vorwiderstand.
- Mechanischer Einbau und Anschluss.
- Erneute Prüfung, ob die GPIOs im dann aktuellen Hardware-/Firmwarestand
  weiterhin frei sind.

Die Pins sind mit diesem Eintrag noch nicht verbindlich reserviert.
Die Idee ist noch nicht in Hardware oder Firmware umgesetzt.

## IDEA-002 – Polyfuse in der 5-V-Versorgung

- **Aufgenommen:** 07.10.2026
- **Status:** Vorgemerkt
- **Ziel:** Rückstellende Überstromsicherung für die 5-V-Versorgung des Adapters.
- **Möglicher Einbauort:** In Reihe zum 5-V-Eingang der USB-C-Trägerversorgung,
  vor der Verteilung auf Pico-Versorgung und 3,3-V-Regler.

### Bei Umsetzung festzulegen

- Halte- und Auslösestrom anhand der gemessenen Stromaufnahme, Einschaltströme
  und WLAN-Lastspitzen auswählen; Umgebungstemperatur berücksichtigen.
- Spannungsabfall und verbleibende Versorgungsspannung unter Last prüfen.
- Auslöseverhalten bei Überlast/Kurzschluss und Rückstellung nach Abkühlung prüfen.
- Passenden Bauteiltyp, Bauform und Platzierung festlegen; dabei auch den
  separaten Pico-USB-Servicebetrieb und dessen Versorgungspfad berücksichtigen.

Die Idee ist noch nicht im Schaltplan oder Board umgesetzt.

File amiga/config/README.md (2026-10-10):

# FunkOttoConfig – erster Amiga-Teststand

Shell-Programm für 68000 und neuer, Ziel Kickstart/Workbench 1.3.
**Diese Ausgabe arbeitet nur mit einem lokalen simulierten Adapter.**
Keine Platine und kein Pico erforderlich. Keine CIA-Zugriffe, keine echten
WLAN-Verbindungen und keine Dateien mit Zugangsdaten. Vorhandene Firmware
kann unverändert bleiben. Bitte nur ein erfundenes Testpasswort verwenden.

## Auf dem A500 starten

ZIP auf dem PC entpacken und `FunkOttoConfig` binär auf den Amiga kopieren.
In der Amiga-Shell in das Verzeichnis wechseln. Falls das Kopierwerkzeug das
Ausführungsrecht nicht erhalten hat: `Protect FunkOttoConfig +e`.

```text
Stack 8192
FunkOttoConfig SELFTEST
FunkOttoConfig SIM
```

SELFTEST muss mit dieser Zeile enden:

```text
PASS: local FOC1 configuration selftest; no CIA access.
```

SIM öffnet ein eigenes RAW:-Textfenster. Bitte in diesem Fenster tippen.
Es übernimmt das Echo selbst, damit das Passwort verborgen bleibt und die
aufrufende Shell ihren Eingabemodus behält. Workbench-Doppelklick wird in dieser
Ausgabe noch nicht unterstützt. Das Fenster mit `quit` schließen.

## Testablauf

Jeden Befehl und jede Eingabe mit Return abschließen:

1. `status`: anfangs `UNCONFIGURED`, `configured=0`, `stored=0`.
2. `scan`: drei künstliche Ergebnisse, zweimal `Demo WLAN` mit unterschiedlichen
   BSSIDs und Kanälen sowie eine versteckte SSID. Das ist keine Umgebungsmessung.
3. `set`: SSID `Demo WLAN`, danach ein erfundenes Passwort wie `test1234`.
   Das Passwort darf nicht auf dem Bildschirm erscheinen. `set` verbindet noch
   nicht und speichert noch nicht im simulierten Flash.
4. `connect`: `LINK_UP` und `stored=0`.
5. `save`, danach `YES`: simuliertes Profil gespeichert. `status` zeigt
   `stored=1`, `sequence=1`. Ein zweites identisches Save erhöht die Sequenz nicht.
6. `reboot`, danach gegebenenfalls zweimal `status`: simulierte automatische
   Wiederverbindung mit gespeichertem Profil. Keine echte Hardware wird resettet.
7. `disconnect`, danach `scan`: Scan wieder möglich. Ein Scan bei aktivem
   Verbindungswunsch liefert absichtlich `job_reply=1` (BUSY).
8. `erase`, danach `YES`, `reboot`, `status`: `UNCONFIGURED`, `stored=0`,
   `flash_state=2`, `sequence=2` (wenn zuvor genau ein neues Profil gespeichert wurde).
9. `quit`: Fenster zu, Rückkehr in die Shell ohne Absturz.

Die simulierten Daten leben nur bis zum Beenden. Ein neuer Programmstart beginnt
leer; `reboot` testet das Laden des simulierten Flash innerhalb derselben Sitzung.

Zusatzprüfungen: Backspace korrigiert die letzte Eingabe; ein kurzes Passwort oder
zu lange SSID wird abgelehnt. Cursor-/Funktionstasten und andere Steuersequenzen
verwerfen die ganze Zeile. ASCII-SSID mit Leerzeichen ist möglich, nicht-ASCII-
Eingabe und Auswahl direkt aus der Scanliste folgen später. Ctrl-C/Ctrl-D beendet
das Programm; je nach Handler wird ein externer Break erst bei Rückkehr aus Read
ausgewertet. `quit` im Fenster ist der normale Weg zum Beenden.

## Fehler und Grenzen

`client=-1`: Transportfehler; `-2`: ungültige Antwort; `-3`: Wartezeit abgelaufen;
`-4`: Abbruch; `-5`: Protokoll- oder Jobfehler. `job_reply=255` bedeutet, dass kein
abgeschlossenes Jobergebnis vorliegt. Bei einem Timeout/Abbruch kann eine zuvor
angenommene Aktion schon erfolgt sein. Mutationen werden nicht blind wiederholt.

Der Transport besitzt eine separate Austauschfunktion und eine wartende Funktion.
Der Client nutzt dieselbe FOC1-Payload-Spezifikation wie das PC-USB-Werkzeug; der
Simulator verwendet direkt den Produktionsdecoder der Firmware. Ein künftiger
Paralleltransport ist noch **nicht implementiert**. Er folgt nach M0-/M2-Abnahme.
SANA-II, Intuition-GUI und echter WLAN-Betrieb vom Amiga sind weitere Schritte.

## Entwicklung und Prüfung

```sh
python tools/build_amiga_config.py --source-id development
python tests/run_config_amiga_emulation.py build/amiga-config/FunkOttoConfig
python tests/run_host_tests.py
python tools/package_amiga_config.py build/amiga-config build/funkotto-amiga-config.zip
```

Compiler und Emulator sind wie beim M2-Diagnosetool in der CI festgelegt:
GCC 13.3.0 m68k, Binutils 2.42 und Unicorn 2.1.4. Kein Amiga-SDK, Linux-Laufzeitcode
oder Kickstart-ROM wird mitgeliefert. `-fno-store-merging` verhindert zusammengefasste
Stores auf ungeraden Protokolloffsets. Der HUNK-Test kontrolliert tatsächlich alle
Word-/Long-Zugriffe der ausgeführten Pfade auf 68000-Ausrichtung.

Die lokalen Prüfungen verwenden OS-Mocks; der erste echte OS-1.3-Test dieses
Programms steht aus. Ein früherer erfolgreicher FunkOttoDiag-Test zählt nicht
als Abnahme von FunkOttoConfig. Bitte die SELFTEST-Ausgabe und Auffälligkeiten
beim obigen SIM-Ablauf zurückmelden.

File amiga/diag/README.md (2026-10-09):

# FunkOttoDiag M2

Eigenständiges CLI-Diagnoseprogramm für 68000 und AmigaOS 1.3 (V34).
Kein SANA-II-Treiber. Start von Workbench wird ohne Portzugriff beendet und die
Workbench-Nachricht beantwortet. Befehle und Laborablauf: [M2_TEST](../../firmware/M2_TEST.md).

```text
Stack 8192
FunkOttoDiag SELFTEST
FunkOttoDiag RUN M0-VERIFIED 64
```

Der erste Befehl greift nicht auf die CIA zu. Der zweite ist der aktive
Labortest und setzt M0 sowie explizit aktivierte M2-Firmware voraus.

## Reproduzierbarer Build

Ubuntu 24.04: `gcc-13-m68k-linux-gnu` 13.3.0-6ubuntu2~24.04cross1,
`binutils-m68k-linux-gnu` 2.42-4ubuntu2.10. Keine fremde Amiga-SDK- oder
Kickstart-Distribution. Der Crosscompiler erzeugt ausschließlich freistehenden
68000-Code (`-m68000`, `-msoft-float`, ohne libc/CRT/Linux-Aufrufe).

```sh
python3 tools/build_amiga_diag.py --source-id <quellstand>
python3 -m pip install unicorn==2.1.4
python3 tests/run_m2_amiga_emulation.py build/amiga-m2/FunkOttoDiag
```

`--cc`, `--prefix`, `--output` erlauben abweichende Werkzeugpfade. Der Linker
erstellt eine ELF-Zwischenstufe mit Relokationen. Der geprüfte Konverter erzeugt
einen Amiga-CODE-Hunk mit RELOC32. Unbekannte Relokationen und externe Symbole
werden abgelehnt. Das ELF ist kein Amiga-Programm; auszuführen ist ausschließlich
`FunkOttoDiag`. Ein Manifest nennt Compiler, Quellstand und Prüfsumme.

Die Bibliotheksstubs übersetzen die C-Aufrufkonvention in Amiga-Registerargumente,
einschließlich D0→A0 bei Zeigerrückgaben. Nur V34-taugliche Aufrufe; kein
`ReadArgs`, `Printf`, `ReadEClock` oder sonstiges V36-API. Kurze Disable/Enable-
Abschnitte schützen einzelne CIA-Registerfolgen. Wartephasen bleiben unterbrechbar.

Die Emulation lädt die tatsächliche HUNK-Datei an einer anderen Basisadresse,
wendet ihre Relokationen an, nutzt ein 68000-CPU-Modell, prüft ungerade Wortzugriffe,
ABI und Fehlerpfade. OS-Vektoren und CIA/Adapter sind simuliert; das ist kein
vollständiger OS-1.3-/FS-UAE-Nachweis und keine elektrische Hardwareabnahme.

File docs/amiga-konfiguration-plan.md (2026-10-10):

# Amiga-Konfiguration: Plan und erster Stand

Ziel: WLAN-Konfiguration auf A500 / Kickstart 1.3 / Workbench 1.3 / 68020,
mit einem auch für den 68000 übersetzten Programm. Die Trägerplatine fehlt
noch; aktive Parallelport-Tests bleiben von M0 abhängig.

## Schritte

1. **FOC1-Client und austauschbarer Transport.** INFO, STATUS, SCAN/SCAN_GET,
   SET, CONNECT/DISCONNECT, SAVE/ERASE und JOB; Bytezugriffe für Big Endian
   und ungerade Protokolloffsets. Antworten vor der Anzeige prüfen.
2. **Lokaler Adapter-Simulator.** Produktionsdecoder `config_protocol.c`,
   simuliertes WLAN-Backend, verzögerte Jobs, Scan mit doppelter/versteckter
   SSID, RAM-Profil und simulierter Flash. Kein Zugriff auf CIA oder Datenträger.
3. **OS-1.3-Textprogramm.** Shell-Start, eigenes RAW:-Textfenster für verdeckte
   Passworteingabe; Status, Scan und Profilverwaltung. SELFTEST funktioniert
   direkt in der Shell. Keine Funktionen ab V36. Dies ist die erste Umsetzung.
4. **Prüfung und Paket.** Client-Negativtests, ausführbare HUNK-Datei unter
   68000-Emulation mit V34-OS-Mocks; Eingabe, Passwortausgabe, Abbruch, Fehler,
   Aufräumen und Registerkonvention. Danach manueller Test auf dem echten A500.
5. **Echter Adaptertransport – nach M0/M2-Hardwarefreigabe.** Konfigurations-
   kanal in den Paralleltransport integrieren, exklusiven Besitz gegenüber
   SANA-II koordinieren, Sitzungswechsel/Reset und ausstehende Jobs testen.
   Keine automatische Wiederholung unsicher abgeschlossener Mutationen.
6. **Bedienoberfläche.** Nach bestätigtem Textprogramm eine Intuition-Oberfläche
   für 1.3 mit Netzwerkliste, Passworteingabe, Status und Speicheraktionen.

## Umfang des ersten Pakets

`FunkOttoConfig SELFTEST` prüft den lokalen Protokollablauf.
`FunkOttoConfig SIM` startet eine interaktive Simulation. Speichern bedeutet
hier ausschließlich ein zweites RAM-Profil im laufenden Programm. `reboot`
simuliert einen Adapterneustart und übernimmt dieses Profil; nach `quit` ist
alles weg. Weder ein Pico noch ein SANA-II-Treiber werden dabei angesprochen.
Die vorhandene Pico-Firmware e92d982f16d1 muss dafür nicht geändert werden.

Der USB-Konfigurationspfad bleibt das PC-Testwerkzeug. Die gemeinsame Grenze
für PC und Amiga ist die FOC1-Befehlsebene; USB-COBS-Framing gehört nicht in
den Amiga-Bediencode. Der Amiga-Client wartet mit DOS Delay auf Jobs und
Verbindungsstatus (begrenzt auf etwa 30 Sekunden), statt die CPU zu beschäftigen.
Dies legt nicht den späteren Interruptbetrieb des SANA-II-Datenpfads fest.

## Grenzen und Abnahmekriterien

- Erstfassung: ASCII-Eingabe für SSID; 1–32 Bytes, Leerzeichen erlaubt. Schlüssel
  8–63 druckbare ASCII-Zeichen, keine Kommandozeilenoption dafür, kein Echo und
  keine Dateiablage. Empfangene SSIDs werden unabhängig davon byteweise sicher
  dargestellt. Scan-Auswahl nach BSSID und nicht-ASCII-Eingabe folgen später.
- `set` bearbeitet das RAM-Profil. `save` und `erase` verlangen im Programm YES.
  Gleiche gespeicherte Zugangsdaten erhöhen die simulierte Flash-Sequenz nicht.
- Abbruch/Timeout kann eine bereits angenommene Aktion nicht zurücknehmen.
  Kein automatisches erneutes SET/SAVE/ERASE nach Transportfehlern.
- Ein bestandener Emulatorlauf ist kein Test von Kickstart 1.3, dem realen
  RAW:-Handler, WLAN oder elektrischen Signalen. Diese Freigaben getrennt halten.
- Reale Erstabnahme: SELFTEST, Scanliste, verstecktes Testpasswort, Connect,
  Save/Reboot, Erase/Reboot und Beenden ohne Guru. Anleitung unter
  `amiga/config/README.md`.

## Quellen für die OS-Schnittstelle

- AmigaDOS-Dokumentation zu CON:/RAW: und byteorientierter Eingabe:
  https://wiki.amigaos.net/wiki/AmigaDOS_Introduction
- Console-Device-Dokumentation zu Eingabebytes und Sondertasten-Sequenzen:
  https://wiki.amigaos.net/wiki/Console_Device

RAW: ist ein eigenes Fenster; die Shell muss nicht in einen anderen Modus
geschaltet werden. Der Parser verwirft Zeilen mit Steuersequenzen oder Überlänge
vollständig. Unterstützt werden Return, Backspace und Abbruch, kein Cursor-Editor.

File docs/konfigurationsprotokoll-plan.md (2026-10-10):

# M4-Konfigurationsprotokoll und USB-Testzugang

Stand: 10.10.2026. Die Trägerplatine fehlt; M0 und die aktive M2-Abnahme bleiben
unverändert offen. W5 bleibt ausgelassen. Dieser Schritt verwendet nur den Pico
2 W am PC-USB und gibt keine Parallelportleitung frei.

## Umsetzung

1. **Gemeinsamer Kommandokern:** byteweise definierte, versionierte Formate für
   Fähigkeiten, Status, Scan, RAM-Profil, Connect/Disconnect, Save/Erase und
   Auftragsabfrage. Bestehenden WLAN-Service und W4-Journal wiederverwenden;
   keine Änderung des Flashformats. Befehlsannahme, Serviceabschluss und
   WLAN-Linkbereitschaft sind unterschiedliche Zustände.
2. **Eigener USB-Modus:** explizit `config on`, neue Transportversion, HELLO mit
   Sitzung, CRC32/COBS, begrenzte Pakete, eine offene Übertragung und exakte
   Wiederholung der letzten Anfrage. DTR-Verlust und Inaktivität beenden die
   Sitzung. Kein automatisches Wiederholen von Änderungen in einer neuen Sitzung.
3. **PC-Werkzeug:** Fähigkeiten vor Änderungen prüfen, Status/Scan auslesen,
   Passwort verdeckt abfragen, RAM-Profil setzen und separat verbinden/speichern.
   Flash-Löschen nur explizit. Keine Passwörter als CLI-Argumente oder in Reports.
4. **Tests/Build:** echte C-Handler mit simuliertem WLAN-Service prüfen;
   fehlerhafte Rahmen, Längen, Sequenzen/Sitzungen, verlorene Antworten,
   Queue-BUSY, verzögerte Aufträge, Scan-Generationen und Passwortfreiheit der
   Antworten abdecken. Python-Client gegen den C-Server prüfen. Pico-Release
   bauen und ELF/UF2 auf GPIO-/Flash-Invarianten prüfen.
5. **Nutzerprüfung:** Status und Scan am einzelnen Pico, dann RAM-Profil,
   Connect/Disconnect, bewusstes Speichern, Kaltstart und optional Löschen.
   Reale Ergebnisse getrennt von Simulation/Build dokumentieren.

## Lieferumfang dieser ersten Umsetzung

Eigenes Ziel `funkotto_m4_usb` auf W4-Basis, transportunabhängiger Dispatcher,
USB-Framing, `tools/wifi_config.py`, Protokollspezifikation, Hosttests und
Bedienungsanleitung. Bestehende W4-Konsole und `raw on` bleiben verfügbar.
Die gegenseitig exklusiven USB-Modi besitzen die WLAN-Kommandos jeweils allein.

## Stand der Umsetzung

Schritte 1–4 sind softwareseitig umgesetzt, lokal geprüft und in der GitHub-CI
bestanden. Schritt 5 begonnen: realer HELLO-/Statustest mit LINK_UP, gespeichertem
Profil (Sequenz 3) und fehlerfreiem USB-Austausch bestanden. Disconnect und
vollständiger Scan mit fünf Einträgen und anschließender Reconnect bis LINK_UP
ebenfalls bestanden. SET mit verdeckter Passworteingabe und anschließender
Verbindung ebenfalls bestätigt (`attempts=3`, `links=3`, keine USB-Fehler).
Das eingegebene Profil entspricht dem gespeicherten (Sequenz 3). Idempotentes
SAVE und anschließender Wiederanlauf mit Autoconnect im angeforderten Kaltstartablauf
sind ebenfalls bestätigt (`attempts=1`, `links=1`, `epoch=2`, Sequenz 3).
ERASE/Neuanlage über den neuen USB-Zugang sowie erweiterte Flash-/Resetprüfungen
bleiben offen; keine vollständige M4-Hardwareabnahme. [Prüfbericht](results/2026-10-10-m4-usb.md).

## Danach

Amiga-Client (68000/V34) mit explizitem lokalem Simulationsmodus, anschließend
Anbindung an den realen M2-Transport nach M0/M2-Messungen. Intuition-Oberfläche
und SANA-II bleiben Folgearbeiten. Ein erfolgreicher USB-Test ist keine
Amiga-Parallelport-Abnahme und keine vollständige M4-Hardwareabnahme.

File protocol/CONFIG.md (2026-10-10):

# FOC1: Konfigurationsbefehle und USB-Testtransport

Version 1.0, erster Implementierungsstand 10.10.2026. Ziel `funkotto_m4_usb`.
Die Befehls-Payloads sind transportunabhängig (`config_protocol.c`); der
USB-Transport (`config_wire.c`) ist ein eigener, exklusiver Modus. Diese
Spezifikation erweitert weder das M2-B1536-Framing noch RAW v1. Eine spätere
M2-Anbindung muss die Fähigkeit explizit melden und Sitzung/Replay garantieren.

## USB-Sitzung

115200 Baud als CDC-Einstellung (USB selbst bestimmt die Übertragungsrate).
Aus der Textkonsole `config on` senden. Nur bei freiem WLAN-Kommando-Mailboxplatz
wird `CONFIG v1 wire=2; ...` ausgegeben; danach keine Textausgaben im Binärmodus.
RAW und CONFIG sind gegenseitig exklusiv. Der Host liest die vollständige
Begrüßungszeile vor seinem HELLO. Der Einstieg deaktiviert den Ethernet-Testempfang,
verändert aber weder Profil noch gewünschten WLAN-Verbindungszustand.

Rahmen: `00 COBS(header || payload || crc32) 00`. Leere Trennrahmen ignorieren.
CRC32/ISO-HDLC (reflektiertes Polynom 0xEDB88320, init/xorout 0xFFFFFFFF), über
Header und Payload; Testvektor ASCII `123456789` = 0xCBF43926. CRC als BE32.
Alle Mehrbytewerte big endian; signierte Werte Zweierkomplement. Keine gepackten
C-Strukturen, keine Nullterminierung von SSIDs, keine Passwort-Rückgabe.

| Headeroffset | Breite | Inhalt |
| --- | --- | --- |
| 0 | 1 | USB-Transportversion **2** (RAW bleibt 1) |
| 1 | 1 | Opcode; Antwort = Anfrage OR 0x80 |
| 2 | 2 | Payloadlänge 0..128 |
| 4 | 4 | Sequenz, beginnend bei 1; 0 unzulässig |
| 8 | 8 | Sitzung |
| 16 | variabel | Payload, anschließend 4 Byte CRC |

Maximal 148 decodierte Bytes, Empfangspuffer 150 COBS-Bytes. Ungültige Version,
CRC, COBS oder Länge: verwerfen, keinerlei Zustandsänderung. Überlauf verwirft bis
zur nächsten Null. Unvollständiger Rahmen wird nach mehr als 2 s ohne Eingabe
verworfen; erst ein Null-Delimiter stellt wieder eine Grenze her. DTR-Verlust
oder mehr als 60 s ohne Eingabe löscht Transportzustand/Replaypuffer und kehrt
zur Textkonsole zurück. Bereits angenommene Serviceaufträge laufen dabei weiter.

HELLO: Opcode 0, Sequenz 1, Sitzung 0, leere Payload. Antwort mit zufälliger,
nichtnulliger 64-Bit-Sitzung und INFO-Payload. Kein WLAN-Link und keine gültige
MAC als Voraussetzung. Danach Sitzung übernehmen und Sequenz um eins erhöhen.
Nur eine Anfrage gleichzeitig. Bei Antwortverlust denselben kompletten Rahmen
wiederholen. Byteidentische letzte Anfrage liefert die gecachte Antwort,
**ohne erneute Befehlsausführung**. Veränderte Wiederholung, Lücken, alte Sequenz
oder ein zweites HELLO nach anderen Befehlen werden abgewiesen. Kein Wrap nach
0xFFFFFFFF: neue Sitzung erforderlich. Wiederholte HELLO direkt nach HELLO sind
erlaubt. Ein Fehler SESSION/SEQUENCE verschiebt die erwartete Sequenz nicht.
Andere gültig sequenzierte Anfragen verbrauchen ihre Sequenz, auch bei BUSY.

Der Replaypuffer hält genau eine Anfrage und Antwort. Eine SET-Anfrage kann
bis zur nächsten angenommenen Anfrage (normalerweise JOB) das Passwort im RAM
enthalten; Ersetzen/Schließen löscht den Puffer. Parser-Zwischenpuffer und lokale
Profilkopien werden unmittelbar gelöscht. Die WLAN-RAM-/Flashkonfiguration
enthält weiter die für Verbindungen benötigten Zugangsdaten. Der USB-Kanal ist
weder verschlüsselt noch authentifiziert; keine echten Zugangsdaten mitschneiden.
Python und Betriebssystempuffer garantieren keine sichere Speicherlöschung.

## Antwortstatus (erstes Payloadbyte bei jedem Befehl)

| Wert | Bedeutung |
| --- | --- |
| 0 OK | Lesebefehl erfolgreich |
| 1 QUEUED | Änderungsauftrag angenommen; BE32-Auftragskennung folgt |
| 2 BUSY | Nicht angenommen; vorherigen Auftrag abwarten |
| 3 INVALID | Falsche Länge/Parameter |
| 4 UNSUPPORTED | Unbekannter Opcode |
| 5 STALE | Unbekannte Auftragskennung oder veraltete Scan-Generation |
| 6 EMPTY | Kein Scan-Eintrag an diesem Index |
| 7 SESSION | Falsche/geschlossene Sitzung |
| 8 SEQUENCE | Unzulässige Reihenfolge oder veränderte Wiederholung |

Fehlerantworten haben genau ein Byte. QUEUED hat genau fünf Bytes. Die folgenden
Offsets gelten jeweils ab Beginn der Antwortpayload, einschließlich Statusbyte.

## Befehle

| Opcode | Name | Anfragepayload | Erfolgsantwort |
| --- | --- | --- | --- |
| 1 | INFO | leer | Fähigkeiten, Format unten |
| 2 | STATUS | leer | WLAN-/Profil-/Scanstatus, Format unten |
| 3 | SCAN | leer | QUEUED + job |
| 4 | SCAN_GET | BE32 Generation + uint8 Index | Ein Eintrag, Format unten |
| 5 | SET_PROFILE | auth=1, SSID-Länge, Key-Länge (je uint8), SSID, Key | QUEUED + job |
| 6 | CONNECT | leer | QUEUED + job |
| 7 | DISCONNECT | leer | QUEUED + job |
| 8 | SAVE_PROFILE | leer | QUEUED + job |
| 9 | ERASE_PROFILE | leer | QUEUED + job |
| 10 | JOB | BE32 job | 8 Bytes: OK, BE32 job, ursprünglicher Opcode, pending, reply |

INFO (18 Bytes, auch HELLO): 0 Status; 1..4 ASCII `FOC1`; 5 Major=1; 6 Minor=0;
7..10 BE32 Fähigkeiten; 11..12 BE16 max_payload=128; 13 max_ssid=32;
14 min_key=8; 15 max_key=63; 16..17 ASCII Land `DE`.
Fähigkeitsbits: 0 Status, 1 Scan, 2 RAM-Profil, 3 Connect/Disconnect,
4 Flash-Save/Erase, 5 asynchrone JOB-Abfrage. Aktuell 0x0000003F.

SET: auth=1 bedeutet WPA2-AES-Personal. SSID 1..32 beliebige Bytes, Passwort
8..63 druckbare ASCII-Bytes (0x20..0x7E). Kein Open/WPA3, keine 64-stelligen
Hex-PSKs. SET beendet die bisherige Verbindung und ändert nur RAM; CONNECT
startet Verbindungsversuche; SAVE ist immer eine getrennte Benutzeraktion.
ERASE löscht RAM und persistentes Profil mit dem bestehenden W4-Verfahren.

Jobnummern starten je Sitzung bei 1, nur der jüngste angenommene Job bleibt
abfragbar. pending=1 bedeutet noch laufend, reply dann 255. pending=0 bedeutet
abgeschlossen: reply 0 OK, 1 BUSY, 2 NO_PROFILE, 3 DRIVER_ERROR, 4 INVALID,
5 FLASH_ERROR. Bis zum Abschluss wird kein weiterer Änderungsauftrag angenommen;
Leseabfragen funktionieren weiter. JOB-Antworten sind ebenfalls Replay-Snapshots:
Fortschritt mit neuer Sequenz abfragen, nicht mit Wiederholung derselben Abfrage.
Bei ausgeschöpften Jobnummern neue Sitzung beginnen. Der Dispatcher setzt einen
exklusiven Core-0-Auftraggeber voraus; USB erzwingt diese Zuständigkeit.

**Serviceabschluss ist nicht Linkbereitschaft:** CONNECT/OK aktiviert die
Verbindungsversuche; anschließend STATUS bis LINK_UP prüfen. SCAN/OK startet den
Scan; anschließend scanning=0, passende scan_done/scan_generation und sdk_error=0
abwarten. Bei gewünschter Verbindung/Autoretry kann SCAN mit Service-BUSY enden;
vorher ausdrücklich DISCONNECT ausführen. SAVE/ERASE-OK bestätigt dagegen den
abgeschlossenen Speicherauftrag einschließlich W4-Verifikation. Kein Exactly-once-
Versprechen über Stromausfall oder Sitzungsende: nach unklarem Ausgang Status
prüfen, niemals automatisch einen neuen Änderungsauftrag senden.

## STATUS (51 + SSID-Länge Bytes)

| Offset | Format | Inhalt |
| --- | --- | --- |
| 0 | u8 | OK |
| 1 | u8 | Zustand: 0 INITIALIZING, 1 UNCONFIGURED, 2 DISCONNECTED, 3 CONNECTING, 4 LINK_UP, 5 RETRY_WAIT, 6 ERROR |
| 2 | u8 | Fehler: 0 OK, 1 NO_PROFILE, 2 TIMEOUT, 3 BADAUTH, 4 NONET, 5 DRIVER, 6 LINK_LOST, 7 JOIN_FAILED |
| 3 | u8 Bits | 0 configured, 1 stored, 2 auto_retry, 3 mac_valid, 4 rssi_valid, 5 scanning, 6 sdk_busy, 7 command_busy |
| 4 | u8 | storage_state: 0 EMPTY, 1 PROFILE, 2 DELETED, 3 CORRUPT, 4 INCOMPATIBLE, 5 AMBIGUOUS |
| 5 | u8 Bits | 0 flash_profile, 1 flash_ready |
| 6 | 6 Bytes | MAC; nur gültig mit mac_valid |
| 12 | BE i32 | RSSI; nur gültig mit rssi_valid |
| 16 | BE i32 | sdk_error |
| 20/24/28 | je BE32 | epoch / attempts / links |
| 32/36 | je BE32 | storage_sequence / storage_error |
| 40/44 | je BE32 | scan_generation / scan_done |
| 48/49 | je u8 | scan_count / scan_truncated |
| 50 | u8 | SSID-Länge |
| 51 | Bytes | SSID, ohne Passwort |

storage_error: 0 OK, 1 IO, 2 VERIFY, 3 FORMAT, 4 NOT_READY.

SCAN_GET: 0 OK; 1..4 BE32 Generation; 5 Index; 6 Anzahl; 7 truncated;
8 auth (roher CYW43-Scanwert, **nicht** SET-auth); 9..10 BE16 Kanal;
11..12 BE i16 RSSI; 13..18 BSSID; 19 SSID-Länge; 20.. SSID-Bytes.
Versteckte SSID darf Länge 0 haben. Während des Scans BUSY; veraltete oder nullige
Generation STALE; Index >= Anzahl EMPTY. SSID/Scanwerte sind keine Terminal-
Steuersequenzen: das PC-Tool gibt sie JSON-escaped aus.

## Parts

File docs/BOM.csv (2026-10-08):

Reference | Value / MPN | Footprint | Notes
C1 | 1uF | C0603_MAS_C1
C2 | 2.2uF | C0603_MAS_C2
C3 | 10uF 10V | C0805_C3
C4 | 100nF | C0603_C4
C5 | 100nF | C0603_C5
C6 | 100nF | C0603_C6
C7 | 100nF | C0603_C7
C8 | 100nF | C0603_C8
C9 | 100nF | C0603_C9
C10 | 100nF | C0603_C10
C11 | 100nF | C0603_C11
D1 | SS14 | SOD123_D1 | External USB to VSYS diode; Pico VBUS is not connected to carrier USB.
J1 | TYPE-C 6P | USB_C_MAS_Original_J1
J2 | DB25 MALE / MAS original | DB25_MAS_Original_J2
R6 | 5.1k | R0603_MAS_R6
R7 | 5.1k | R0603_MAS_R7
R10 | 100 | R0402_R10
R11 | 100 | R0402_R11
R12 | 100 | R0402_R12
R13 | 100 | R0402_R13
R14 | 100 | R0402_R14
R15 | 100 | R0402_R15
R16 | 100 | R0402_R16
R17 | 100 | R0402_R17
R20 | 100 | R0402_R20
R21 | 100 | R0402_R21
R22 | 330 | R0402_R22
R23 | 330 | R0402_R23
R24 | 330 | R0402_R24
R25 | 10k | R0402_R25
R26 | 100k | R0402_R26
R27 | 100 | R0402_R27
R28 | 4.7k | R0402_R28
R29 | 4.7k | R0402_R29
R30 | 10k | R0402_R30
R31 | 10k | R0402_R31
R32 | 10k | R0402_R32
R33 | 10k | R0402_R33
R34 | 10k | R0402_R34
R35 | 10k | R0402_R35
R36 | 100k | R0402_R36
TP1 | +3V3_IF | TP1_TP1
TP2 | GND | TP1_TP2
TP3 | PIO_STROBE_N | TP1_TP3
TP4 | PIO_SEL | TP1_TP4
TP5 | DATA_OE_N | TP1_TP5
TP6 | DATA_DIR | TP1_TP6
TP7 | PICO_RUN_N | TP1_TP7
U1 | LD2981ABU33TR | SOT89_MAS_Original_U1
U2 | SN74LVC4245APWR | TSSOP24_U2
U3 | SN74LVC125APWR | TSSOP14_U3
U4 | SN74LVC4245APWR | TSSOP24_U4
U5 | SN74LVC1G10DBVR | SOT23_6_U5
U6 | SN74LVC1G10DBVR | SOT23_6_U6
U7 | Raspberry Pi Pico 2 W | Pico2W_PartialSocket_15x2_U7 | Rotated 180deg; two 1x15 sockets on module pins 1..15 and 26..40. Antenna overhang 11.3471 mm. Minimum 8.5mm socket spacing recommended. Pins16..25 not soldered.
U8 | SN74LVC2G07DCKR | SC70_6_DCK_U8

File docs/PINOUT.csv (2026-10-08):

Reference | Pin | Pin name | Net
C1 | 1 |  | /GND
C1 | 2 |  | /+5V_USB
C2 | 1 |  | /GND
C2 | 2 |  | /+3V3_IF
C3 | 1 |  | /PICO_VSYS
C3 | 2 |  | /GND
C4 | 1 |  | /+5V_USB
C4 | 2 |  | /GND
C5 | 1 |  | /+3V3_IF
C5 | 2 |  | /GND
C6 | 1 |  | /+3V3_IF
C6 | 2 |  | /GND
C7 | 1 |  | /+5V_USB
C7 | 2 |  | /GND
C8 | 1 |  | /+3V3_IF
C8 | 2 |  | /GND
C9 | 1 |  | /+3V3_IF
C9 | 2 |  | /GND
C10 | 1 |  | /+3V3_IF
C10 | 2 |  | /GND
C11 | 1 |  | /+3V3_IF
C11 | 2 |  | /GND
D1 | 1 |  | /PICO_VSYS
D1 | 2 |  | /+5V_USB
J1 | 1 | GND | /GND
J1 | 2 | SHIELD | /GND
J1 | 3 | SHIELD | /GND
J1 | 4 | SHIELD | /GND
J1 | 5 | CC2 | /USB_CC2
J1 | 6 | VBUS | /+5V_USB
J1 | 7 | GND | /GND
J1 | 8 | CC1 | /USB_CC1
J1 | 9 | VBUS | /+5V_USB
J1 | 10 | SHIELD | /GND
J2 | 1 | STROBE_N | /AM_STROBE_N
J2 | 2 | D0 | /AM_D0
J2 | 3 | D1 | /AM_D1
J2 | 4 | D2 | /AM_D2
J2 | 5 | D3 | /AM_D3
J2 | 6 | D4 | /AM_D4
J2 | 7 | D5 | /AM_D5
J2 | 8 | D6 | /AM_D6
J2 | 9 | D7 | /AM_D7
J2 | 10 | ACK_N | /AM_ACK_N
J2 | 11 | BUSY | /AM_BUSY
J2 | 12 | POUT | /AM_POUT
J2 | 13 | SEL | /AM_SEL
J2 | 14 | 5V_SENSE | /AM_5V_SENSE
J2 | 15 | NC | unconnected-(J2-NC-Pad15)
J2 | 16 | RESET_N | /AM_RESET_N
J2 | 17 | GND | /GND
J2 | 18 | GND | /GND
J2 | 19 | GND | /GND
J2 | 20 | GND | /GND
J2 | 21 | GND | /GND
J2 | 22 | GND | /GND
J2 | 23 | GND | /GND
J2 | 24 | GND | /GND
J2 | 25 | GND | /GND
R6 | 1 |  | /GND
R6 | 2 |  | /USB_CC1
R7 | 1 |  | /GND
R7 | 2 |  | /USB_CC2
R10 | 1 |  | /AM_D0
R10 | 2 |  | /BUS_D0
R11 | 1 |  | /AM_D1
R11 | 2 |  | /BUS_D1
R12 | 1 |  | /AM_D2
R12 | 2 |  | /BUS_D2
R13 | 1 |  | /AM_D3
R13 | 2 |  | /BUS_D3
R14 | 1 |  | /AM_D4
R14 | 2 |  | /BUS_D4
R15 | 1 |  | /AM_D5
R15 | 2 |  | /BUS_D5
R16 | 1 |  | /AM_D6
R16 | 2 |  | /BUS_D6
R17 | 1 |  | /AM_D7
R17 | 2 |  | /BUS_D7
R20 | 1 |  | /AM_STROBE_N
R20 | 2 |  | /STROBE_IN
R21 | 1 |  | /AM_SEL
R21 | 2 |  | /SEL_IN
R22 | 1 |  | /AM_ACK_N
R22 | 2 |  | /ACK_OUT
R23 | 1 |  | /AM_BUSY
R23 | 2 |  | /BUSY_OUT
R24 | 1 |  | /AM_POUT
R24 | 2 |  | /POUT_OUT
R25 | 1 |  | /AM_5V_SENSE
R25 | 2 |  | /HOST_PRESENT
R26 | 1 |  | /HOST_PRESENT
R26 | 2 |  | /GND
R27 | 1 |  | /AM_RESET_N
R27 | 2 |  | /RESET_IN
R28 | 1 |  | /FW_DATA_EN
R28 | 2 |  | /GND
R29 | 1 |  | /FW_CTRL_EN
R29 | 2 |  | /GND
R30 | 1 |  | /DATA_DIR
R30 | 2 |  | /+3V3_IF
R31 | 1 |  | /DATA_OE_N
R31 | 2 |  | /+3V3_IF
R32 | 1 |  | /CTRL_OE_N
R32 | 2 |  | /+3V3_IF
R33 | 1 |  | /PIO_ACK_N
R33 | 2 |  | /GND
R34 | 1 |  | /PIO_BUSY
R34 | 2 |  | /GND
R35 | 1 |  | /PIO_POUT
R35 | 2 |  | /GND
R36 | 1 |  | /RESET_IN
R36 | 2 |  | /GND
TP1 | 1 |  | /+3V3_IF
TP2 | 1 |  | /GND
TP3 | 1 |  | /PIO_STROBE_N
TP4 | 1 |  | /PIO_SEL
TP5 | 1 |  | /DATA_OE_N
TP6 | 1 |  | /DATA_DIR
TP7 | 1 |  | /PICO_RUN_N
U1 | 1 | OUT | /+3V3_IF
U1 | 2 | GND | /GND
U1 | 2@1 | TAB_GND | /GND
U1 | 3 | IN | /+5V_USB
U2 | 1 | VCCA_5V | /+5V_USB
U2 | 2 | DIR | /DATA_DIR
U2 | 3 | A0 | /BUS_D0
U2 | 4 | A1 | /BUS_D1
U2 | 5 | A2 | /BUS_D2
U2 | 6 | A3 | /BUS_D3
U2 | 7 | A4 | /BUS_D4
U2 | 8 | A5 | /BUS_D5
U2 | 9 | A6 | /BUS_D6
U2 | 10 | A7 | /BUS_D7
U2 | 11 | GND | /GND
U2 | 12 | GND | /GND
U2 | 13 | GND | /GND
U2 | 14 | B7 | /PIO_D7
U2 | 15 | B6 | /PIO_D6
U2 | 16 | B5 | /PIO_D5
U2 | 17 | B4 | /PIO_D4
U2 | 18 | B3 | /PIO_D3
U2 | 19 | B2 | /PIO_D2
U2 | 20 | B1 | /PIO_D1
U2 | 21 | B0 | /PIO_D0
U2 | 22 | OE_N | /DATA_OE_N
U2 | 23 | VCCB_3V3 | /+3V3_IF
U2 | 24 | VCCB_3V3 | /+3V3_IF
U3 | 1 | 1OE_N | /CTRL_OE_N
U3 | 2 | 1A | /STROBE_IN
U3 | 3 | 1Y | /PIO_STROBE_N
U3 | 4 | 2OE_N | /CTRL_OE_N
U3 | 5 | 2A | /SEL_IN
U3 | 6 | 2Y | /PIO_SEL
U3 | 7 | GND | /GND
U3 | 8 | 3Y | unconnected-(U3-3Y-Pad8)
U3 | 9 | 3A | /GND
U3 | 10 | 3OE_N | /+3V3_IF
U3 | 11 | 4Y | unconnected-(U3-4Y-Pad11)
U3 | 12 | 4A | /GND
U3 | 13 | 4OE_N | /+3V3_IF
U3 | 14 | VCC | /+3V3_IF
U4 | 1 | VCCA_5V | /+5V_USB
U4 | 2 | DIR | /GND
U4 | 3 | A0 | /ACK_OUT
U4 | 4 | A1 | /BUSY_OUT
U4 | 5 | A2 | /POUT_OUT
U4 | 6 | A3 | unconnected-(U4-A3-Pad6)
U4 | 7 | A4 | unconnected-(U4-A4-Pad7)
U4 | 8 | A5 | unconnected-(U4-A5-Pad8)
U4 | 9 | A6 | unconnected-(U4-A6-Pad9)
U4 | 10 | A7 | unconnected-(U4-A7-Pad10)
U4 | 11 | GND | /GND
U4 | 12 | GND | /GND
U4 | 13 | GND | /GND
U4 | 14 | B7 | /GND
U4 | 15 | B6 | /GND
U4 | 16 | B5 | /GND
U4 | 17 | B4 | /GND
U4 | 18 | B3 | /GND
U4 | 19 | B2 | /PIO_POUT
U4 | 20 | B1 | /PIO_BUSY
U4 | 21 | B0 | /PIO_ACK_N
U4 | 22 | OE_N | /CTRL_OE_N
U4 | 23 | VCCB_3V3 | /+3V3_IF
U4 | 24 | VCCB_3V3 | /+3V3_IF
U5 | 1 | A_FW_ENABLE | /FW_DATA_EN
U5 | 2 | GND | /GND
U5 | 3 | B_HOST_PRESENT | /HOST_PRESENT
U5 | 4 | Y_OE_N | /DATA_OE_N
U5 | 5 | VCC | /+3V3_IF
U5 | 6 | C_RESET_N | /RESET_IN
U6 | 1 | A_FW_ENABLE | /FW_CTRL_EN
U6 | 2 | GND | /GND
U6 | 3 | B_HOST_PRESENT | /HOST_PRESENT
U6 | 4 | Y_OE_N | /CTRL_OE_N
U6 | 5 | VCC | /+3V3_IF
U6 | 6 | C_RESET_N | /RESET_IN
U7 | 1 | GP0 | /PIO_D0
U7 | 2 | GP1 | /PIO_D1
U7 | 3 | GND | /GND
U7 | 4 | GP2 | /PIO_D2
U7 | 5 | GP3 | /PIO_D3
U7 | 6 | GP4 | /PIO_D4
U7 | 7 | GP5 | /PIO_D5
U7 | 8 | GND | /GND
U7 | 9 | GP6 | /PIO_D6
U7 | 10 | GP7 | /PIO_D7
U7 | 11 | GP8 | /PIO_STROBE_N
U7 | 12 | GP9 | /PIO_SEL
U7 | 13 | GND | /GND
U7 | 14 | GP10 | /PIO_BUSY
U7 | 15 | GP11 | /PIO_POUT
U7 | 26 | GP20 | /DATA_DIR
U7 | 27 | GP21 | /FW_DATA_EN
U7 | 28 | GND | /GND
U7 | 29 | GP22 | /FW_CTRL_EN
U7 | 30 | RUN | /PICO_RUN_N
U7 | 31 | GP26 | /PIO_ACK_N
U7 | 32 | GP27 | unconnected-(U7-GP27-Pad32)
U7 | 33 | AGND | /GND
U7 | 34 | GP28 | unconnected-(U7-GP28-Pad34)
U7 | 35 | ADC_VREF | unconnected-(U7-ADC_VREF-Pad35)
U7 | 36 | 3V3_OUT | unconnected-(U7-3V3_OUT-Pad36)
U7 | 37 | 3V3_EN | unconnected-(U7-3V3_EN-Pad37)
U7 | 38 | GND | /GND
U7 | 39 | VSYS | /PICO_VSYS
U7 | 40 | VBUS | unconnected-(U7-VBUS-Pad40)
U8 | 1 | 1A_RESET_N | /RESET_IN
U8 | 2 | GND | /GND
U8 | 3 | 2A_HOST_PRESENT | /HOST_PRESENT
U8 | 4 | 2Y_OD | /PICO_RUN_N
U8 | 5 | VCC | /+3V3_IF
U8 | 6 | 1Y_OD | /PICO_RUN_N

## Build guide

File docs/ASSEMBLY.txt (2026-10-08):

Bestückungshinweise Rev B2

U7 benötigt zwei 1×15-Buchsenleisten mit 2,54-mm-Raster und passende Stiftleisten
nur an den Pico-Pins 1–15 und 26–40. Mechanische Zusatzteile sind nicht als
separate elektrische Bauteile im Schaltplan dargestellt. Verfügbare Sockelhöhe
gegen Bauteile unter dem Modul prüfen; Ziel mindestens 8,5 mm freie Höhe.

0402-Widerstände erfordern geeignete Bestückungsausrüstung. Vor Handbestückung
eine größere Revision mit 0603 erwägen. Kondensatoren C1/C2 gehören zur
übernommenen Reglerbeschaltung: tatsächlichen Typ/ESR zuerst verifizieren.
Zusätzliche 100-nF-Kondensatoren: X7R, >=10 V. C3: 10 uF, >=10 V,
Kapazitätsverlust unter Gleichspannung berücksichtigen. Widerstände 1 %.

J1/J2 und U1 anhand der ursprünglichen Bauteile/Bestellnummern identifizieren;
der übernommene Footprint allein ist keine vollständige Beschaffungsspezifikation.
Nicht mit einem ähnlich aussehenden USB-C- oder DB25-Typ substituieren.
Pico 2 W darf nicht durch Pico W oder einen RP2040-Nachbau ersetzt werden,
ohne Firmware-, Pin- und Stromversorgungsreview.

F.Cu / In1.Cu / In2.Cu / B.Cu: vier Kupferlagen. Keine Gerberfreigabe enthalten.
Original-DB25-Kontakte liegen auf Ober- und Unterseite. Beschriftungen sind
überwiegend auf Dwgs.User, nicht als Fertigungssiebdruck ausgeführt. Für die
Bestückung docs/components.json (Positionen in mm) und Board in KiCad verwenden.
Vor Fertigung Bestückungsdruck und Prüfpunktzugang bei gestecktem Pico prüfen.
Neu U8/C11/R36/TP7: Beschriftung auf Dwgs.User. U8 exakt Open-Drain-Typ
SN74LVC2G07DCKR; Pinbelegung nicht mit U5/U6 gleichsetzen.

B1: Referenztexte auf F.SilkS sind mindestens 0,8 mm hoch. Umrisse U1/J1/U7
liegen auf F.Fab; Resetbauteil-Referenzen wie bisher auf Dwgs.User.
Projektlokale Footprints haben bauteilspezifische Namen, physische Bauformen unverändert.

B2: U8 jetzt SC70-6 (DCK), 0,65-mm-Pinraster. Der bisherige DBVR passt nicht
auf das neue Lötbild. Pin 1 ist im F.Fab-Umriss abgeschrägt. U5/U6 bleiben DBVR.

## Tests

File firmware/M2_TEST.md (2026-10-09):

# FunkOtto M2: erster Amiga-Link

M2 ist als eigene Diagnosefirmware `funkotto_m2` implementiert. W4 bleibt separat
verfügbar. M2 enthält **kein WLAN** und verändert keine WLAN-Profile. Ein normaler
UF2-Update muss weiterhin am Gerät auf Profilerhalt geprüft werden; kein Full-Erase
verwenden. KiCad-Dateien wurden nicht verändert.

## Jetzt ohne aktive Bustests möglich

`FunkOttoDiag` aus `amiga/` auf den Amiga kopieren und aus der Shell starten:

```text
Stack 8192
FunkOttoDiag SELFTEST
```

Erwartet: `HELLO session=...`, `ECHO verified count=0x00000040`, anschließend
`PASS: local protocol selftest; no CIA access.` Dieser Selbsttest benötigt keinen
Adapter und greift nicht auf den Parallelport zu. Die 8-KiB-Stackeinstellung lässt
Reserve für Betriebssystemaufrufe. Bitte Amiga-Modell, CPU,
Kickstart-/Workbench-Version und Ausgabe festhalten. Ein erfolgreicher Nutzerlauf
mit 64 ECHOs ist auf Amiga 500 mit 68020, Kickstart 1.3 und Workbench 1.3
dokumentiert. Ein realer 68000-Lauf bleibt offen.
Die separate 68000-Emulation verwendet simulierte OS-Aufrufe.

Die mitgelieferte `funkotto_m2.uf2` ist ein **gesperrter Standard-Build**:
`active_build=0`. Beim Flashen wie bisher den Pico entnehmen oder DB25 und
USB-C-Trägerversorgung trennen, dann BOOTSEL am Pico benutzen.
USB-Kommandos `info` und `status` funktionieren ohne WLAN und ohne Terminal beim
Boot. Erwartet: `state=0 bus_locked=1`. `link arm M0-VERIFIED` wird in diesem
Build abgelehnt. Ein Stromausfall bleibt damit im sicheren Bootzustand.

## Laborbetrieb nach elektrischer M0-Prüfung

Ein aktiver Build wird bewusst separat erstellt; er ist nicht die Standard-UF2.
Voraussetzung sind die Messungen am Nutzerboard aus dem
[M0-Abschnitt](../docs/firmware-v0.1-plan.md): Versorgung, RUN/Reset,
OE-Sperrung, Pegel und kontrollierte Richtungsübergabe. Keine Abnahme aus einem
CI-Ergebnis ableiten. Die Messungen bei realen Transfers gehören zum Laborablauf.

```sh
cmake -S firmware -B build/m2-lab -G Ninja \
  -DPICO_SDK_PATH=/pfad/zum/gepinnten/pico-sdk \
  -DCMAKE_BUILD_TYPE=Release -DFUNKOTTO_BUILD_WIFI=OFF \
  -DFUNKOTTO_M2_ACTIVE=ON -DFUNKOTTO_SOURCE_ID=<quellstand>
cmake --build build/m2-lab --target funkotto_m2
```

Auch dieser Build startet gesperrt. Nach der Messfreigabe im USB-Terminal:

```text
info
link arm M0-VERIFIED
status
```

Erwartet: `active_build=1`, `ARMED; waiting for host sync`. Nun auf dem Amiga,
ohne parallel.device/printer.device oder einen weiteren Portnutzer:

```text
FunkOttoDiag RUN M0-VERIFIED 64
```

Das Tool reserviert beide Parallelport-Ressourcen, synchronisiert, führt HELLO
und 64 geprüfte ECHOs aus. Längen: 0, 1, 2, 7, 63, 255, 512 und 1500 Bytes.
Muster wechseln zwischen 00, FF, 55, AA, Walking-One, Walking-Zero und
Pseudozufallsbytes. Ein Fehler beendet den Lauf mit Rückgabecode 20;
Erfolg mit 0. Ctrl-C bricht Wartephasen ab. Nach Fehlern nicht blind
fortsetzen: Ausgabe und `status` am Pico sichern.

Bei bestandenem ersten Lauf anschließend größere Serien bis 100.000 ECHOs,
Reset in beiden Richtungen, abgebrochene Transfers und beide Einschaltfolgen
prüfen. Der erste Lauf ist kein Durchsatz- oder Langzeitnachweis. IRQ-/SANA-II-
Treiber, Amiga-WLAN-Konfiguration und Netzwerkverkehr gehören zu Folgepaketen.

Zum Sperren:

```text
link lock
status
```

Wieder erwartet: `state=0 bus_locked=1`. Vor Verwendung des WLAN-Diagnosepfads
die bereits getestete W4-UF2 wieder installieren.

## Statuswerte und Messpunkte

| state | Bedeutung |
| --- | --- |
| 0 | Gesperrt, keine PIO-/DMA-Ressourcen reserviert |
| 1 | Warten auf SEL-Synchronisation; Daten gesperrt |
| 2 | SEL High bestätigt, Daten gesperrt |
| 3 | Empfang / RX-DMA |
| 4 | Request geprüft, Warten auf Host-Richtungsübergabe |
| 5 | TX-DMA lädt erstes Byte; externe Daten noch gesperrt |
| 6 | Antwort senden |
| 7 | Letztes Byte quittiert, Warten auf SEL Low |

`transactions` zählt vollständig quittierte Antworten. `aborts`, `timeouts`
und `invalid` zählen verworfene Transfers. Nach Rückgabe an die Shell kann der
RX-Leerlauf nach zwei Sekunden in state=1 wechseln; das ist keine offene
Datenausgabe. Der nächste RUN synchronisiert neu.

Aufzeichnen: STROBE_N/TP3, SEL/TP4, BUSY, POUT, DATA_OE_N/TP5, DATA_DIR/TP6
und RUN/TP7; einzelne Datenbits in weiteren Messdurchläufen. Prüfen, dass
DDRB vor SEL High auf Eingang steht, DATA_OE_N während der Richtungsänderung
High ist und POUT erst nach stabilem ersten Lesebyte High wird. Digitale
Logikanalysator-Aufnahmen ersetzen keine analogen Pegel-/Flankenmessungen.

[Protokoll](../protocol/M2.md) · [Prüfbericht](../docs/results/2026-10-09-m2.md)

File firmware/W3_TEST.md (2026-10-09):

# FunkOtto W3 – Ethernet über USB prüfen

Firmware `0.1.0-w3`, Ziel `funkotto_w3`, Pico 2 W. W3 implementiert Roh-Ethernet
mit je acht festen TX-/RX-Puffern. Reale Tests am 09.10.2026 mit 12/12 und
anschließend 1.000/1.000 geprüften Antworten einschließlich MTU 1500 bestanden.
Der 1.000er-Lauf wurde anhand von JSON und PCAP geprüft. AP-Ausfall mit
Wiederverbindung und erneutem Pakettest ist vom Nutzer bestätigt; separate
Logs dieses Ausfalltests liegen nicht vor. Langzeitbetrieb und die Ursache
einzelner Latenzausreißer bleiben offen.
Der Amiga-Bus bleibt gesperrt; WLAN-Zugangsdaten bleiben ausschließlich im RAM.

## 1. Flashen und WLAN verbinden

Pico herausnehmen oder **DB25 und USB-C-Trägerversorgung abziehen**, bevor sein
eigener USB-Port verwendet wird. BOOTSEL halten, Pico mit PC verbinden,
`funkotto_w3.uf2` auf `RP2350` kopieren. Kein Update über den Amiga.

Serielles Terminal öffnen (115200, keine Flusssteuerung, lokales Echo aus).
Befehle wie bei W1/W2:

```text
info
status
wifi set
```

SSID und danach Passwort auf die jeweilige Aufforderung eingeben; danach:

```text
wifi connect
wifi status
```

Auf `wifi=LINK_UP` warten. `status` muss weiterhin `bus_locked=1` und
`output_mask=0x00700000` melden. Terminal **schließen**, aber Pico angeschlossen
lassen: Trennen der Stromversorgung löscht das RAM-Profil. Zugangsdaten werden
weder vom PC-Testprogramm benötigt noch in dessen Bericht gespeichert.

## 2. USB-Verbindung prüfen

ZIP vollständig entpacken. Python 3.10 oder neuer und pyserial installieren:

```text
python -m pip install pyserial==3.5
python tools/wifi_diag.py --port COM5
```

`COM5` durch den Pico-Port ersetzen; unter Linux z. B. `/dev/ttyACM0`.
Das Programm aktiviert `raw on` selbst. Es zeigt Stations-MAC, Link, Link-Epoche
und Paket-/Fehlerzähler. Dieser Aufruf prüft nur USB/Status, noch keine LAN-Pakete.
Nach Programmende kann das normale Terminal wieder geöffnet werden.

Beim Werkzeug aus `b09aa6182ef8` kann einmalig `usb_bad_frames=1` erscheinen:
Die Textbegrüßung vor dem Binärmodus wird im Host-Fehlerzähler mitgezählt.
Das ist bei sonst gültigen Antworten und `usb_retries=0` allein kein Beleg für
einen Übertragungsfehler. Zusätzliche Fehler im laufenden Test gesondert prüfen.

## 3. ARP und ICMP über eine LAN-Gegenstelle testen

Benötigt werden eine erreichbare IPv4-Gegenstelle im selben Subnetz, die Ping
beantwortet, und eine **freie Test-IP** für den Pico. Die Test-IP nicht vom PC
oder einem anderen Gerät übernehmen; im Router prüfen und möglichst außerhalb
des DHCP-Pools wählen. Das Programm sendet vor Verwendung drei ARP-Probes und
bricht bei erkanntem Adresskonflikt ab. Ein ausbleibender ARP-Konflikt beweist
nicht, dass ein ausgeschaltetes Gerät die Adresse nie verwendet.

Beispiel, **Adressen und Port an das eigene LAN anpassen**:

```text
python tools/wifi_diag.py --port COM5 --source-ip 192.168.178.250/24 --target-ip 192.168.178.1 --count 12 --pcap w3.pcap --report w3.json
```

- Die Subnetzangabe `/24` bedeutet `255.255.255.0`; die tatsächliche Netzmaske verwenden.
- Die Gegenstelle kann ein Router oder zweiter Rechner sein. Firewall muss ICMP-Echo erlauben.
- Gastnetz/AP-Client-Isolation kann den LAN-Zugriff sperren, obwohl WLAN `LINK_UP` meldet.
- Kein DHCP, Routing oder TCP/IP-Stack auf dem Pico: Das Python-Programm erzeugt
  ARP/IPv4/ICMP und beantwortet ARP-Anfragen für die Test-IP.
- Gesendet wird mit der tatsächlichen Stations-MAC. Der Pico übernimmt Ethernet II
  ohne VLAN, maximal 1514 Bytes ohne FCS; kürzere TX-Frames werden auf 60 Bytes
  mit Nullen aufgefüllt. IP-MTU ist 1500.

Erwartet: `arp peer=...`, zwölf `echo ... verified=1` und abschließend
`"passed": true`, `"lost": 0`. Die vier Payload-Größen 0, 56, 512 und 1472 Bytes
prüfen Mindestlänge, kleine Frames und MTU-Grenze. Jede Echo-Antwort wird auf
MAC/IP-Adressen, Checksummen, Kennung, Sequenz und exakten Nutzinhalt geprüft.

`w3.pcap` enthält TX/RX am USB-Testclient und lässt sich mit Wireshark öffnen.
TX-Einträge bedeuten SDK-Annahme, nicht einen Funkmitschnitt. Für unabhängigen
Nachweis zusätzlich auf der LAN-Gegenstelle ARP/ICMP mitschneiden. Die RTT enthält
USB, Host-Polling und WLAN; sie ist **kein Amiga-Durchsatzbenchmark**.

## 4. Weitere Abnahme

1. Den Lauf mit `--count 1000` wiederholen; Bericht, PCAP und `info` aufbewahren.
2. Während eines Laufs AP ausschalten: Fehler/Timeout ist erwartet; keine
   endlose Blockade. Bei USB-Timeout ist der Ausgang der letzten TX-Anfrage
   unbekannt; nicht automatisch als neues Paket nachsenden.
3. AP einschalten, Testport schließen, Terminal öffnen und automatische
   WLAN-Wiederverbindung prüfen. Danach einen **neuen** Testlauf starten.
4. Terminal öffnen: `status`, `wifi status`, `wifi stats`; Bus unverändert gesperrt.
5. Programm abbrechen/Port schließen und erneut öffnen. Der Client zieht DTR
   beim Start für 150 ms auf Low; das beendet eine alte Rohdatensitzung, ohne
   den Pico oder das RAM-Profil zurückzusetzen.

Bei vollem RX-Ring verwirft die Firmware neue Pakete und erhöht `rx_full`.
Bereits gespeicherte Frames bleiben unverändert. `rx_inactive` zählt Frames
außerhalb einer aktiven Testsitzung, `rx_flushed` bei Link-/Sitzungswechsel
verworfene Warteschlangen. Auf einem belebten LAN sind diese Zähler nicht
zwangsläufig null. `tx_used` umfasst wartende, aktive und noch nicht abgeholte
TX-Abschlüsse. `tx_busy` meldet erschöpfte Slots. Der USB-Test arbeitet bewusst
mit nur einer offenen Anfrage; acht parallele TX-Aufträge und volle Ringe
werden zusätzlich in den nativen C-Tests geprüft.

USB-Prüfsummenfehler führen zum Verwerfen bis zum nächsten Null-Delimiter.
Der Client wiederholt dieselbe Anfrage mit gleicher Sequenz; die Firmware
liefert ihre gespeicherte Antwort erneut, ohne ein zweites Mal zu senden oder
RX zu entnehmen. Ein neuer Pico-/USB-Sitzungsschlüssel wird nicht stillschweigend
akzeptiert. [Protokolldetails](USB_PROTOCOL.md).

## Build und automatische Prüfungen

Gleiche Toolchain und SDK-Pins wie in `README.md`; Standard-CMake baut M1,
W1/W2 und W3 gemeinsam. Beispiel aus dem Repository:

```text
python tools/check_board_contract.py
python tests/run_host_tests.py
python -m unittest discover -s tests -p "test_*.py"
python tools/check_firmware_artifacts.py build/m1 --target funkotto_w3
python tools/package_firmware.py build/m1 .deps/pico-sdk build/m1/funkotto-w3.zip --target funkotto_w3
```

Die beiden Profilsektoren und der eigene RP2350-E10-Sektor bleiben getrennt;
W3 schreibt keine Profile. Ergebnisse im [W3-Prüfbericht](../docs/results/2026-10-09-w3.md).

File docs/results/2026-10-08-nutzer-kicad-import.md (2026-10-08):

# KiCad-Nutzerstand importiert – 08.10.2026

Quelle: `AmiWiFi_Pico2W.zip`, vom Nutzer zur Ablösung der GitHub-KiCad-Dateien bereitgestellt.

- Archiv-SHA-256: `bd613fabed2d811002555808f2d009a6fe154f1ae98b2aa73a1b3ae569d12de9`
- Übernommener Umfang: 79 Projekt-, Schaltplan-, Board-, Symbol- und Footprintdateien einschließlich Bibliothekstabellen und Exportkonfiguration.
- Gegenüber dem vorherigen GitHub-Stand geändert: `hardware/AmiWiFi.kicad_pcb`.
- Zusätzlich im Archiv enthalten und übernommen: `hardware/AmiWiFi.pretty/SOT23_6_U8.kicad_mod`.
- Alle übrigen Projektdateien stimmen bereits bytegenau überein.
- Die importierten KiCad-Dateien wurden nicht automatisch korrigiert, neu gespeichert oder geroutet.
- Automatische Backups, lokale Editorzustände und Produktionsausgaben sind nicht Bestandteil dieses KiCad-Quelldateiimports.

## Prüfsummen der Hauptdateien

| Datei | SHA-256 |
| --- | --- |
| `hardware/AmiWiFi.kicad_pcb` | `b2f32df78c15e37ceb1bc0433f0356848106e7a86a1e82df63c3da5a7e26928c` |
| `hardware/AmiWiFi.kicad_pro` | `1bd2cb8be831d30905e7e794ebb73a12d464ecc978074c5d4fbfebf515615447` |
| `hardware/AmiWiFi.kicad_sch` | `7c79beedb5473c872b8ad4855c7a03fb04484a50e73ab5bca5bac22929186a50` |
| `hardware/AmiWiFi.kicad_sym` | `150ac17792d6702ff94d447a2480fde20160a46e494f226721c1727fed90b6ea` |

## Prüfstatus

Der Import prüft die vollständige, bytegenaue Übereinstimmung der 79 Dateien
mit dem Nutzerarchiv anhand ihrer Git-Blob-Prüfsummen. DRC/ERC wurden für
diesen Import nicht erneut ausgeführt. Vorhandene Berichte unter `validation/`,
Vorschauen unter `preview/` und abgeleitete Bestückungsdaten stammen aus dem
vorherigen Rev-B2-Stand und wurden nicht als neue Ergebnisse übernommen.
Die im ZIP mitgelieferten älteren Berichte ersetzen keine Prüfung des geänderten Boards.

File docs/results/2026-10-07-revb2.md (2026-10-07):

# Rev B2: U8 im SC70-6-Gehäuse

Rev B2 – U8 auf SN74LVC2G07DCKR umgestellt, 07.10.2026

Basis ist die gelieferte Rev B1 mit der vom Nutzer bearbeiteten Platine.
U8 wechselt von DBV (SOT-23-6) auf DCK (SC70-6). Elektrische Pinbelegung,
Open-Drain-Resetfunktion, Bestückungsposition (134, 104 mm) und Orientierung
bleiben gleich. U5/U6 bleiben SN74LVC1G10DBVR.

Projektlokales Lötbild AmiWiFi:SC70_6_DCK_U8 nach TI DCK0006A,
Zeichnung 4214835/D, 11/2024: sechs Pads 0,9 x 0,4 mm, Eckradius 0,05 mm,
Pinraster 0,65 mm, Reihenmittenabstand 2,2 mm. Nominaler Körper 1,25 x 2,0 mm
in Boardorientierung. Courtyard 3,6 x 2,7 mm. Pin-1-Fase auf F.Fab.
Quelle: https://www.ti.com/lit/gpn/sn74lvc2g07 (DCK-Gehäusezeichnung/Layout).

Zehn lokale Leiterbahnsegmente angepasst; GND-Via von (132,5;104) auf
(133,6;104) mm versetzt. Kupferfüllungen neu berechnet. Die anderen 55
Footprints einschließlich Pads und Positionen bleiben identisch zu B1.
Kontur, Netztopologie, Flächenparameter und Projekt-Prüfregeln bleiben gleich.
234 Pad-Netze exakt einschließlich / und NC-Netzen mit dem nativen Export
verglichen. Schaltplan, Symbolbibliothek, Footprintbibliothek, BOM und
Bestückungsdaten synchronisiert. Vorherige Prüfberichte unter reference/.

KiCad 10.0.6: DRC mit --schematic-parity --all-track-errors:
0 Fehler, 0 Warnungen, 0 offene Verbindungen, 0 Schaltplanabweichungen.
ERC: 0 Fehler, 0 Warnungen. Keine neuen Ausnahmen/deaktivierten Prüfregeln.
Elektrische Musterprüfung ist weiterhin offen; keine Fertigungsfreigabe.

## Prüfberichte

- [DRC mit Schaltplanvergleich](2026-10-07-revb2/KiCad_DRC.txt)
- [ERC](2026-10-07-revb2/KiCad_ERC.txt)
- [Änderungs- und Netzabgleich](2026-10-07-revb2/checks.json)

Das separate KiCad-Paket heißt `FunkOtto_Pico2W_RevB2.zip`.
Hardware-Prüfsummen stehen im [Firmwareplan](../firmware-v0.1-plan.md).

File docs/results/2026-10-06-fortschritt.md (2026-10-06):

# FunkOtto – Fortschritt am 06.10.2026

Aktueller Hardwarestand: **Rev B1**, KiCad 10. Softwarestand: Entwicklungsplan
für die erste funktionale Firmware; noch keine implementierte Firmware,
kein SANA-II-Treiber und kein Amiga-Konfigurationsprogramm im Repository.

## Erreicht

| Bereich | Stand |
| --- | --- |
| Hardwarebasis | Vom Nutzer bearbeitete Rev-A-Fassung als Grundlage übernommen |
| Reset-Erweiterung | Pico-RUN-Reset in Schaltplan und Board ergänzt, einschließlich Routing |
| KiCad-Korrektur B1 | Netznamen, NC-Netze, Bauteilattribute, Bibliothekskopien und Beschriftungen abgeglichen |
| PCB-Prüfung | DRC mit Schaltplanvergleich: 0 Fehler, 0 Warnungen, 0 offene Verbindungen, 0 Schaltplanabweichungen |
| Schaltplanprüfung | ERC: 0 Fehler, 0 Warnungen |
| Firmwareplanung | Hardwarezuordnung, Startablauf, Protokollrahmen, WLAN-Rohframes, persistentes Profil und Abnahme definiert |

Die 56 Bauteilpositionen, Padgeometrien, Leiterbahnen, Vias, Kupferflächen und
Außenkontur sind bei der Korrektur von Rev B auf B1 erhalten geblieben.
Beschriftungspositionen und Bibliothekszuordnungen wurden gezielt korrigiert.

## Festgelegte Hardwareentscheidungen

### Reset

Ein am Adapter anliegender Hardware-Amiga-Reset setzt auch den Pico zurück.
Fehlende Hostversorgung hält ihn ebenfalls in Reset. Die vorhandene
Bustreiber-Sperrlogik U5/U6 bleibt erhalten.

Gegenüber der Nutzerfassung Rev A wurden ergänzt:

| Referenz | Bauteil | Funktion |
| --- | --- | --- |
| U8 | SN74LVC2G07DBVR, SOT-23-6 | Zwei nichtinvertierende Open-Drain-Puffer; gemeinsame Ausgänge an Pico RUN |
| C11 | 100 nF | Versorgungspufferung für U8 |
| R36 | 100 kΩ | Pulldown für RESET_IN |
| TP7 | Testpunkt | Messzugang zu PICO_RUN_N |

**U8 ist der einzige zusätzliche IC.** Von Rev B auf B1 kamen keine weiteren
Bauteile hinzu; die drei PWR_FLAG-Symbole sind reine Schaltplankennzeichnungen.

U8 zieht `PICO_RUN_N` auf Low, wenn `RESET_IN` oder `HOST_PRESENT` Low ist.
Pico **Pin 30 (RUN)** wird nach Freigabe durch seinen internen Pullup angehoben.
Die Firmware muss nach diesem Reset vollständig neu starten, eine neue
Protokollsitzung aufbauen und WLAN erneut verbinden. Das gespeicherte Profil
soll im Flash erhalten bleiben; diese Softwarefunktion ist noch umzusetzen.

### Stromversorgung

Der Pico erhält seine Betriebsspannung über **Modulpin 39 (VSYS)**:

`USB-C J1, 5 V → Schottky-Diode D1 (SS14) → PICO_VSYS → Pico Pin 39`

Masse ist unter anderem an **Pin 38 (GND)** angeschlossen. Der Pico erzeugt
seine internen 3,3 V mit dem Regler auf dem Modul. Der Trägerregler versorgt
die externe 3,3-V-Logik. Pico VBUS/Pin 40 und 3V3_OUT/Pin 36 sind nicht an die
entsprechenden Trägerspannungen angeschlossen.

### Installation und Updates

Firmwareinstallation und Updates erfolgen vorerst über USB/BOOTSEL am Pico.
Updates über den Amiga bleiben zurückgestellt.

Für BOOTSEL im Sockel **DB25 und USB-C-Trägerversorgung trennen**, dann den
Pico an seinem eigenen USB-Anschluss verbinden. Alternativ Pico herausnehmen.
Ein versorgter Träger ohne Amiga hält RUN absichtlich Low. Versorgungstrennung
und Rückspeisungsverhalten sind am Prototyp noch zu prüfen.

## Prüfungen und Korrektur der früheren Aussage

Geprüft mit KiCad 10.0.6:

```sh
kicad-cli pcb drc --schematic-parity --all-track-errors -o DRC.rpt hardware/AmiWiFi.kicad_pcb
kicad-cli sch erc -o ERC.rpt hardware/AmiWiFi.kicad_sch
```

Die Befehle werden im entpackten Hardwarepaket ausgeführt. Das Hardwarepaket
liegt separat vor; dieser Fortschrittsstand ergänzt die Dokumentation und
Prüfberichte im Software-Repository.

Die ursprüngliche Prüfung von Rev B ließ den nativen Schaltplanvergleich aus.
Der zusätzliche eigene Vergleich normalisierte Netznamen durch Entfernen von
`/` und übersprang offene Pins. Damit wurden echte KiCad-Projektabweichungen
übersehen. Die Nutzerberichte zeigten 73 DRC-Warnungen, zusätzlich 208
Schaltplan-/Footprintmeldungen und drei ERC-Versorgungsfehler.

Rev B1 korrigiert insbesondere `GND` gegenüber `/GND`, die generierten NC-Netze,
J1-Felder und Testpunktattribute. Der U7-Schaltplan bildet jetzt genau den
bestückten Teil-Sockel mit Pins 1–15 und 26–40 ab. Die Versorgungseinspeisungen
sind mit PWR_FLAG gekennzeichnet. U4 verwendet ein Symbol für die tatsächlich
fest verdrahtete Richtung B→A bei DIR=GND.

Es wurden keine zusätzlichen Prüfregeln deaktiviert oder neuen Ausnahmen
angelegt. Bereits vorher ignorierte Kategorien stehen unverändert am Ende
der Berichte. Die Null-Befunde gelten für die aktiven Projektprüfungen und
belegen noch keine elektrische Funktion oder Fertigungsfreigabe.

Prüfnachweise:

- [Nativer DRC-Bericht](2026-10-06-revb1/KiCad_DRC.txt)
- [Nativer ERC-Bericht](2026-10-06-revb1/KiCad_ERC.txt)
- [Prüfzusammenfassung und Umfang](2026-10-06-revb1/checks.json)

## Nächste Schritte

1. **M0, elektrische Hardwareabnahme:** Versorgung, Einschaltreihenfolgen,
   RESET_IN/HOST_PRESENT/RUN, Pulsbreiten und beide OE-Signale messen.
   Kein Wiederanlauf alter Busausgänge nach Resetfreigabe. Aktive Amiga-Bustests
   erst nach erfolgreicher Abnahme.
2. **M1, Firmwaregrundlage:** Pico-SDK und Toolchain festlegen, reproduzierbaren
   UF2-Build, sichere GPIO-Startpegel und Versions-/Statusausgabe implementieren.
3. **M2, Amiga-Link:** Erst konservativer Handshake, HELLO/ECHO und ein
   68000-/OS-1.3-taugliches Diagnoseprogramm; danach PIO/DMA-Blocktransfers.
4. **M3/M4, WLAN und Profil:** Ethernet-Rohframes nachweisen, Profilbefehle und
   zwei Flashsektoren für unterbrechungssicheres Speichern/Löschen implementieren.
5. **Integration:** ARP/ICMP vom Amiga, Reset während Transfers/Flashoperationen,
   Wiederverbindung, Durchsatz und Dauerlauf messen.

M1 und isolierte WLAN-Arbeiten können bereits vor M0 beginnen. SANA-II-Treiber
und native Amiga-Konfigurationsoberfläche bleiben Folgepakete. Bootzeit und ein
Vorsprung gegenüber der Plipbox sind bisher ungemessene Entwicklungsziele.

Der verbindliche Ablauf steht im [Firmware-v0.1-Plan](../firmware-v0.1-plan.md).

## Identifikation des Hardwarestands

Separates Paket: `FunkOtto_Pico2W_RevB1.zip`. SHA-256:

| Datei | SHA-256 |
| --- | --- |
| ZIP | `71fa696c74a5893066b6ea507cb20f81100e55547d6f991705b95405922db9ba` |
| `hardware/AmiWiFi.kicad_sch` | `f0fb988d79334e68befdd067eee3bf335fcb88e4ed832d5c7ed0fed0b4c8fd65` |
| `hardware/AmiWiFi.kicad_pcb` | `c3a6cf897fa701b54783b80b83dd6cc1cf037b86b4e3dd8d645b2d0211e7ec6f` |

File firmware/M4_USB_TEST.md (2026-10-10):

# M4: WLAN-Konfiguration über USB testen

Dieses Paket ist für den **einzelnen Pico 2 W am PC**, ohne Trägerplatine und
Amiga-Verbindung. Ziel `funkotto_m4_usb`, Version `0.1.0-m4-usb`. Alle
Parallelportleitungen bleiben im sicheren Zustand. W4-Profilformat und
Flashreservierung sind unverändert; die bisherige Textkonsole und der
Rohpakettest `wifi_diag.py` bleiben verfügbar. Keine Amiga-Firmwareupdates.

## Installation

Pico mit BOOTSEL an USB anschließen und `funkotto_m4_usb.uf2` kopieren.
Kein Flash-Nuke/Full-Erase verwenden. Die UF2 lässt die Profilsektoren aus;
der reale Profilerhalt beim Update ist Teil der Prüfung. Terminalprogramme
schließen, bevor das Python-Werkzeug den COM-Port öffnet.

Python 3.10 oder neuer, einmalig:

```text
python -m pip install pyserial==3.5
```

`tools/wifi_config.py` und `tools/wifi_diag.py` müssen zusammen im Ordner bleiben.
Die Beispiele verwenden den bisherigen COM6; bei Bedarf ändern.

## 1. Erst Status lesen (ohne Profiländerung)

```text
python tools/wifi_config.py --port COM6 --report m4-status.json status
```

Erwartet: `protocol=FOC1`, Version 1.0, Fähigkeiten 63 und ein Statusobjekt.
`passed=true` bedeutet erfolgreicher Befehlslauf, nicht automatisch WLAN-Link.
Bei erhaltenem W4-Profil sind `configured`, `stored`, `flash_profile` true;
Verbindungsaufbau kann noch laufen. Erneut `status` aufrufen und LINK_UP prüfen.
Bitte diese erste Ausgabe zurückmelden, bevor das Profil geändert wird.

## 2. Scan (unterbricht die Verbindung erst durch ausdrückliches Disconnect)

```text
python tools/wifi_config.py --port COM6 disconnect
python tools/wifi_config.py --port COM6 --report m4-scan.json scan
python tools/wifi_config.py --port COM6 connect
python tools/wifi_config.py --port COM6 status
```

SCAN darf bei aktivem Auto-Reconnect mit BUSY enden. Das Tool trennt daher nicht
heimlich die Verbindung. Scan liefert Generation, SSID, Kanal, RSSI und Authwert.
CONNECT/OK heißt, dass der Auftrag ausgeführt wurde; erst STATUS=LINK_UP belegt
eine WLAN-Verbindung. Falsches Passwort/fehlender AP bleiben in STATUS sichtbar.

## 3. Optional: neues RAM-Profil setzen und testen

```text
python tools/wifi_config.py --port COM6 set --ssid "Linux"
python tools/wifi_config.py --port COM6 connect
python tools/wifi_config.py --port COM6 status
```

Das Passwort wird interaktiv verdeckt abgefragt. Kein Passwortargument, keine
Passwortausgabe im JSON. Alternativ `set --ssid-hex 4c696e7578`; ohne SSID-Option
fragt das Tool auch die SSID ab. Text-SSID wird UTF-8-kodiert, maximal 32 Bytes.
SET trennt die bisherige Verbindung und verändert nur RAM. Das bisherige
Flashprofil bleibt bis SAVE/ERASE erhalten. Kein automatisches Speichern.

## 4. Bewusst speichern und Kaltstart prüfen

Nach erfolgreichem LINK_UP:

```text
python tools/wifi_config.py --port COM6 save
python tools/wifi_config.py --port COM6 status
```

Erwartet: erfolgreicher Abschluss, `stored=true`, `flash_profile=true`,
`storage_error=0`. SAVE kann WLAN kurz trennen; auf erneutes LINK_UP warten.
Danach Pico vollständig stromlos machen, wieder verbinden und STATUS lesen.
Automatischer Reconnect ohne erneute Eingabe wird getrennt als Hardwaretest
protokolliert, auch wenn er bereits mit der früheren W4-Version bestanden war.

## 5. Optional: absichtlich löschen

Entfernt die WLAN-Zugangsdaten und beendet die Verbindung:

```text
python tools/wifi_config.py --port COM6 erase --confirm
python tools/wifi_config.py --port COM6 status
```

Erwartet: UNCONFIGURED, `stored=false`, `flash_profile=false`; nach Kaltstart
weiterhin unkonfiguriert. Anschließend bei Bedarf SET/CONNECT/SAVE wiederholen.

## Fehler und Wiederholungen

Das Tool öffnet `config on` selbst, prüft HELLO/Fähigkeiten und schließt den Modus
über DTR. Es hält keine dauerhafte Verbindung und benötigt keine Terminaleingabe.
Nur identische USB-Anfragen werden automatisch wiederholt; die Firmware liefert
die gespeicherte Antwort. Bei Pico-Reset oder endgültigem Timeout ist das Ergebnis
eines Änderungsauftrags möglicherweise unbekannt. Keine automatische Wiederholung
in einer neuen Sitzung: zuerst STATUS lesen. Beim Abbruch kann ein bereits
angenommener Speicherauftrag trotzdem erfolgreich zu Ende laufen.

Eine Sitzung endet auch nach 60 s ohne Eingabe. Nach einem Verbindungsabbruch kurz
warten, bis ein laufender Auftrag abgeschlossen ist. Keine echten Passwörter in
USB-Mitschnitten aufzeichnen. USB-Verkehr und Flashprofil sind nicht verschlüsselt.

## Build und Grenzen

```sh
python tools/bootstrap_sdk.py
cmake -S firmware -B build/m4 -G Ninja -DPICO_SDK_PATH="$PWD/.deps/pico-sdk" -DCMAKE_BUILD_TYPE=Release -DFUNKOTTO_SOURCE_ID=development
cmake --build build/m4 --target funkotto_m4_usb
python tools/check_firmware_artifacts.py build/m4 --target funkotto_m4_usb
```

Festgelegte Buildwerkzeuge: `firmware/dependencies.json`. Protokoll:
`protocol/CONFIG.md`. Kein Amiga-Konfigurationsclient, keine SANA-II-Funktion,
keine M0-/M2-Hardwarefreigabe und keine vollständige M4-Abnahme in diesem Paket.

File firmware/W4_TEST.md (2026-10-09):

# FunkOtto W4 – WLAN-Profil speichern und automatisch verbinden

Firmware `0.1.0-w4`, Ziel `funkotto_w4`, Pico 2 W. W4 ergänzt den geprüften
W3-Rohdatenpfad um ein dauerhaftes WLAN-Profil. Gespeichertes Profil und erster
Kaltstart mit automatischer Wiederverbindung sind am Pico bestätigt. Auch Löschtest
und erneutes Einrichten/Verbinden/Speichern sind bestanden; die weitergehende Hardwareabnahme
bleibt offen
([Prüfstand](../docs/results/2026-10-09-w4.md)). Der Amiga-Bus bleibt gesperrt.

## 1. Flashen und einmalig konfigurieren

Pico herausnehmen oder **DB25 und USB-C-Trägerversorgung abziehen**, bevor sein
eigener USB-Port verwendet wird. BOOTSEL halten, Pico am PC anschließen und
`funkotto_w4.uf2` auf `RP2350` kopieren. Beim ersten Wechsel von W3 geht dessen
bisheriges RAM-Profil verloren; SSID und Passwort einmal neu eingeben.

Terminal öffnen (115200, keine Flusssteuerung, lokales Echo aus):

```text
info
status
wifi set
```

SSID und Passwort bei den jeweiligen Aufforderungen eingeben. Dann:

```text
wifi connect
wifi status
```

Auf `wifi=LINK_UP` warten. `status` muss `bus_locked=1` und
`output_mask=0x00700000` anzeigen. Jetzt ausdrücklich speichern:

```text
wifi save
```

`QUEUED` bedeutet nur angenommen. Auf die nachfolgende Meldung
`wifi command=... result=OK` warten. WLAN wird zum Speichern angehalten und bei
vorher aktivem Verbindungswunsch anschließend neu verbunden. USB kann während
der einzelnen Flashoperationen kurz pausieren. Danach `wifi status` prüfen:

```text
configured=1 stored=1 auto_retry=1
storage=PROFILE storage_error=0 flash_profile=1 flash_ready=1
```

Der Link kann unmittelbar nach dem Speichern noch `CONNECTING` sein;
anschließend muss er wieder `LINK_UP` erreichen. Ein zweites `wifi save` mit
identischen Daten schreibt den Flash nicht erneut, unterbricht in dieser
Version aber ebenfalls kurz den WLAN-Dienst.

## 2. Kaltstart ohne Terminal

1. Terminal schließen, Pico vollständig stromlos machen und wieder anschließen.
2. Zunächst kein Terminal öffnen; die Firmware darf darauf nicht warten.
3. Nach einigen Sekunden Terminal öffnen und `info`, `status`, `wifi status`
   und `wifi stats` ausführen.
4. Erwartet: neue kurze Uptime, gespeichertes Profil, `stored=1`,
   `auto_retry=1` und automatisch `LINK_UP`, ohne `wifi set`/`wifi connect`.
5. Terminal schließen, USB angeschlossen lassen und den bekannten Rohdatentest
   erneut ausführen; zum Beispiel mit den bisher verwendeten LAN-Adressen:

```text
python tools/wifi_diag.py --port COM6 --source-ip 192.168.25.234/24 --target-ip 192.168.25.1 --count 1000 --pcap w4-1000.pcap --report w4-1000.json
```

Port und Adressen bei geändertem Aufbau anpassen; die Test-IP muss weiterhin
frei sein. Das Werkzeug bleibt der W3-Protokolltest und nennt deshalb im JSON
`stage=W3`, auch wenn die Firmware W4 ist. `info` identifiziert den Firmwarestand.

Die Kaltstartprüfung zunächst dreimal wiederholen und die Statusausgaben
zurückmelden. Für die weitergehende Abnahme sind 100 Kaltstarts und anschließend
Tests mit fehlendem AP sowie AP aus/an vorgesehen. Ein fehlender AP soll zu
begrenzten Wiederholungen führen; USB-Konfiguration bleibt erreichbar.

## 3. Bedeutung von RAM-Profil und gespeichertem Profil

| Befehl / Status | Verhalten |
| --- | --- |
| `wifi set` / `wifi sethex` | Ändert nur das RAM-Profil und trennt WLAN. Kein automatisches Speichern. |
| `wifi save` | Speichert das aktuelle gültige RAM-Profil; dieses verbindet beim nächsten Start automatisch. |
| `wifi disconnect` | Stoppt die Verbindung für den laufenden Betrieb. Das Flashprofil bleibt für den nächsten Start erhalten. |
| `stored=1` | Das aktuelle RAM-Profil entspricht dem gespeicherten Profil. |
| `stored=0 flash_profile=1` | Ein Flashprofil existiert, entspricht aber nicht dem aktuellen RAM-Profil. Ein Neustart lädt den Flashstand. |
| `flash_ready=1` | SDK-Sicherheitsinitialisierung erfolgreich; DMA-/Busruhe und Kernfreigabe werden vor jedem Schreiben zusätzlich geprüft. |
| `storage_seq` | Sequenznummer des ausgewählten Flashdatensatzes. |

`wifi save` ohne RAM-Profil liefert `NO_PROFILE`. Während eines Scans liefern
Speichern/Löschen `BUSY`; Scan beenden oder mit `wifi disconnect` abbrechen.
Bei laufendem Befehl startet `raw on` keine neue binäre Testsitzung.
Zugangsdaten stehen unverschlüsselt im Flash; CRC schützt vor beschädigten
Datensätzen, nicht vor Auslesen. Passwort und Flashinhalt werden nicht ausgegeben.

## 4. Profil löschen

Im normalen Terminal:

```text
wifi erase
```

Auf `result=OK` warten. Das löscht RAM-Profil und Verbindungswunsch, schreibt
zuerst einen Löschdatensatz und entfernt danach den alten Sektorinhalt.
Erwartet: `UNCONFIGURED`, `configured=0 stored=0 auto_retry=0`,
`storage=DELETED storage_error=0 flash_profile=0`. Auf einem bereits vollständig
leeren Flash darf `storage=EMPTY` bleiben. Nach Strom aus/an weiterhin kein
Profil und kein automatischer Verbindungsaufbau. Anschließend wieder per
`wifi set`, `wifi connect`, `wifi save` einrichten.

Eine Unterbrechung **vor** dem gültigen Commit kann den vorherigen Stand erhalten;
ein nicht bestätigtes Löschen darf nicht als abgeschlossen gelten. Ist der
Löschdatensatz gültig gespeichert, wird das alte Profil nicht mehr verwendet.
Eine unterbrochene Bereinigung wird beim nächsten Start vor WLAN-Nutzung
fortgesetzt. `result=OK` wird erst nach erfolgreicher Bereinigung ausgegeben.
Das ist logisches Löschen und Sektorlöschen, kein forensisch zertifiziertes Löschen.

## 5. Fehlerstatus und Updates

| `storage` | Bedeutung |
| --- | --- |
| `EMPTY` | Beide Sektoren gelöscht; kein Profil. |
| `PROFILE` | Gültiges Profil vorhanden. |
| `DELETED` | Gültiger Löschdatensatz; kein Autoconnect. Bei Fehlerstatus ist Bereinigung eventuell noch offen. |
| `CORRUPT` | Kein gültiger Datensatz, aber Flash nicht leer; kein Autoconnect. Explizit neu speichern oder löschen. |
| `INCOMPATIBLE` | Neuester gültiger Datensatz hat unbekanntes Format; kein Autoconnect und kein Überschreiben durch `wifi save`. `wifi erase` verwirft ihn ausdrücklich. |
| `AMBIGUOUS` | Sequenzen nicht eindeutig; kein Autoconnect. Explizit `wifi erase` ausführen und neu konfigurieren. |

`storage_error`: 0 OK, 1 Flash-/SDK-Aufruf fehlgeschlagen, 2 Rückleseprüfung
fehlgeschlagen, 3 ungültige Eingabe/Format, 4 sichere Flashfreigabe nicht verfügbar.
Bei `FLASH_ERROR` den Vorgang nicht als erfolgreich betrachten: Ein alter oder
bereits neu geschriebener Stand kann erhalten sein. Status prüfen und gezielt
wiederholen; nicht wiederholt neu flashen. Ein bestätigtes Löschen darf keinen
alten WLAN-Schlüssel nach dem Neustart wieder aktivieren.

Normale **FunkOtto-UF2-Updates** schreiben nicht in die Profilsektoren. Das
Buildwerkzeug prüft jeden UF2-Block. Ein vollständiges Flash-Erase oder fremde
Firmware kann Profile trotzdem löschen. W3/M1 können das W4-Profil nicht nutzen,
berühren seine reservierten Sektoren bei unseren normalen UF2-Dateien aber nicht.

[Speicherformat und Sicherungsablauf](PROFILE_FORMAT.md) ·
[W3-Pakettest](W3_TEST.md) · [W4-Prüfbericht](../docs/results/2026-10-09-w4.md)

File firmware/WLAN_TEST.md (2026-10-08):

# FunkOtto W1/W2 – erste WLAN-Testfirmware

Version `0.1.0-w12.1`, Ziel Pico 2 W. Enthält WLAN-Initialisierung, Scan, ein
RAM-Profil und WPA2-Personal-Verbindung im 2,4-GHz-Netz (Länderkennung DE).
**Noch keine Netzwerkfunktion am Amiga und keine dauerhafte Speicherung.**
Empfangene Ethernet-Pakete werden in dieser Stufe gezählt und verworfen.

## Flashen und erster Test

1. Pico am besten aus dem Trägersockel nehmen. Für Service im Sockel DB25 und
   USB-C-Trägerversorgung trennen. Den eigenen USB-Anschluss des Pico verwenden.
2. BOOTSEL halten, USB einstecken, `funkotto_w12.uf2` auf das Laufwerk kopieren.
3. Seriellen USB-Port öffnen (z. B. 115200, 8N1, keine Flusssteuerung).
   Lokales Echo ausschalten, damit das Passwort beim Eingeben nicht angezeigt wird.
4. `info`, `status`, `wifi status` eingeben. Nach WLAN-Initialisierung erwartet:
   `wifi=UNCONFIGURED`, `mac_valid=1`, `bus_locked=1`, `output_mask=0x00700000`.
   Der Start wartet nicht auf ein Terminal. Falls das Banner verpasst wurde: `info`.
5. `wifi scan` eingeben. Nach `scan finished ...` die Liste mit `wifi results`
   anzeigen. Die Liste enthält höchstens 32 BSSIDs; `truncated=1` zeigt Überlauf.
6. `wifi set` eingeben. Zuerst auf die SSID-Abfrage antworten und Enter drücken,
   danach auf die Passwort-Abfrage antworten und Enter drücken. Keine Anführungszeichen
   ergänzen. Leerzeichen werden beibehalten. Auf `result=OK` warten.
7. `wifi connect` eingeben, danach `wifi status`. Erfolg ist `wifi=LINK_UP`;
   das bedeutet authentifizierte WLAN-Verbindung, nicht eine IP-Adresse des Pico.
8. `wifi stats` und `status` abfragen. Der Bus muss weiterhin gesperrt sein.

Bitte als ersten Test `info`, `status`, `wifi status` und `wifi stats` zurückmelden.
Das Passwort nicht mitliefern; für Diagnosezwecke wird es nicht benötigt.

## Befehle

| Befehl | Bedeutung |
| --- | --- |
| `help`, `info`, `status` | Hilfe, Quellkennung und sichere Adapter-GPIOs |
| `wifi status` | Zustand, letzter Fehler/SDK-Code, MAC, RSSI, Versuche, Linkwechsel |
| `wifi scan` | Scan starten, nur ohne laufenden Verbindungsauftrag/Link |
| `wifi results` | Aktuellen Scan-Schnappschuss anzeigen; auch nach Abschluss verfügbar |
| `wifi set` | SSID und Passwort getrennt abfragen; Profil im RAM ersetzen und Verbindung beenden |
| `wifi sethex` | SSID als 2–64 Hexziffern eingeben, danach normales Passwort; für beliebige SSID-Bytes |
| `wifi connect` | RAM-Profil verbinden; anschließend automatisch erneut versuchen |
| `wifi disconnect` | Verbindung/Scan abbrechen und automatische Versuche stoppen |
| `wifi stats` | Init-/Joinzeit, Core-1-Lebenszeichen, RX-Drops und PIO-/DMA-Belegung |
| `wifi save`, `wifi erase` | Noch nicht implementiert; verändern keinen Flash |

`QUEUED` bestätigt nur die Annahme. Danach meldet Core 1 `wifi command=... result=...`.
Ein weiterer Auftrag kann `BUSY` liefern. Scan während Verbindung ist absichtlich
nicht möglich: zuerst `wifi disconnect`, dann scannen und danach wieder verbinden.
Ein ausgefülltes RAM-Profil bleibt bei `disconnect` erhalten.

SSID: 1–32 Bytes; Passphrase: 8–63 druckbare ASCII-Zeichen. Kein WPA3-only,
Enterprise-WLAN oder 64-stelliger Hex-PSK in dieser Stufe. SSIDs in Ergebnislisten
werden sicher maskiert, beispielsweise `\x1b` statt eines Terminal-Steuerzeichens.
Scan-`auth` ist die rohe SDK-Scan-Kennung, keine von uns erfundene Klassifizierung.

Ctrl-C bricht eine begonnene Eingabe ab. Ebenso werden unvollständige Eingaben
bei USB-Terminaltrennung oder nach 60 s ohne Eingabe verworfen. Bei ungültiger
SSID/Passphrase `wifi set` erneut beginnen. Ein Eingabefehler ändert das bisherige
Profil nicht. Die Firmware sendet das Passwort nie zurück; lokales Terminal-Echo
kann trotzdem vom Terminal erzeugt werden.

## Verhalten und weitere Tests

Join-Frist zunächst 15 s nach dem Join-Aufruf. Danach Versuche im Abstand
1/2/4/8/16/30 s, anschließend höchstens alle 30 s. Initialisierung kann zusätzliche
Zeit brauchen. `BADAUTH` wird nur bei entsprechender SDK-Meldung angezeigt;
`TIMEOUT` ist kein eindeutiger Beweis für ein falsches Passwort.

Vor jedem neuen Versuch wird der Funkchip vollständig neu initialisiert. Das
verhindert Übernahme alter Verbindungsereignisse und ist zunächst auf eindeutiges
Verhalten ausgelegt; die zusätzliche Wiederverbindungszeit wird am Pico gemessen.
USB läuft auf Core 0 weiter. `sdk_busy=1` zeigt die Initialisierung an.

Nach erfolgreichem ersten Join prüfen:

- `wifi disconnect`: Zustand `DISCONNECTED`; auch nach 30 s kein neuer Versuch.
- `wifi connect`: erneuter Linkaufbau mit unverändertem RAM-Profil.
- USB-Terminal schließen/öffnen: Verbindung und RAM-Profil bleiben erhalten,
  sofern die Stromversorgung bestehen bleibt.
- Falsches Passwort und fehlendes Netz: Fehler/Wartezustand, USB weiter bedienbar.
- Bei einem passenden Testnetz AP aus/an: Linkverlust und Wiederverbindung prüfen.
- Pico stromlos/an: `UNCONFIGURED` ist in W1/W2 **richtig**, da das RAM-Profil verloren ist.

## Grenzen der bisherigen Prüfung

C-Hosttests verwenden ASan/UBSan. Zusätzlich läuft der tatsächliche Core-1-Service
gegen einen simulierten SDK-Treiber: Scanüberlauf/Abbruch/Timeout, Mailbox-Sperre,
Löschen temporärer Passwörter, Linkverlust, Wiederholung und Init-Fehlerbehandlung.
ELF/UF2-Prüfung kontrolliert eigene Callbacks, kein lwIP/UART und Flashgrenzen.
Diese Prüfungen ersetzen keinen echten Scan/Join oder Test der USB-Latenz.

Watchdog: Hardwarefrist 8 s. Core 0 füttert nur bei eigenem Fortschritt und einem
höchstens 5 s alten Lebenszeichen von Core 1; während ausgewiesener Initialisierung
höchstens 15 s. Bei Stillstand erfolgt der Reset bis zu etwa 8 s nach dem letzten
Füttern, nicht schon exakt nach 5/15 s. Fristen und echte Watchdog-Auslösung sind
am Pico zu prüfen. Ein Watchdog-Reset verliert in W1/W2 das RAM-Profil.

Core 0 hat 4 KiB reservierten Stack, Core 1 einen eigenen 8-KiB-Stack im SRAM.
PIO/DMA werden vom SDK dynamisch belegt; `pio_sm_mask` kodiert Bit `PIO*4+SM`,
`dma_mask` Bit `Kanal`. Das sind aktuelle Claim-Masken, keine Zusage freier
Ressourcen für spätere Module. High-Water-Messungen der Stacks folgen am Muster.

M1 bleibt als separates Buildziel erhalten. SDK, CYW43 und Funkfirmware sind
festgelegt; Details stehen in `dependencies.json` und im Buildmanifest. Warnungen
über fehlendes lwIP/Bluetooth sind beim absichtlichen Build ohne diese Module
bekannt. Die elektrische M0-Abnahme bleibt Voraussetzung für aktive Amiga-Bustests.
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

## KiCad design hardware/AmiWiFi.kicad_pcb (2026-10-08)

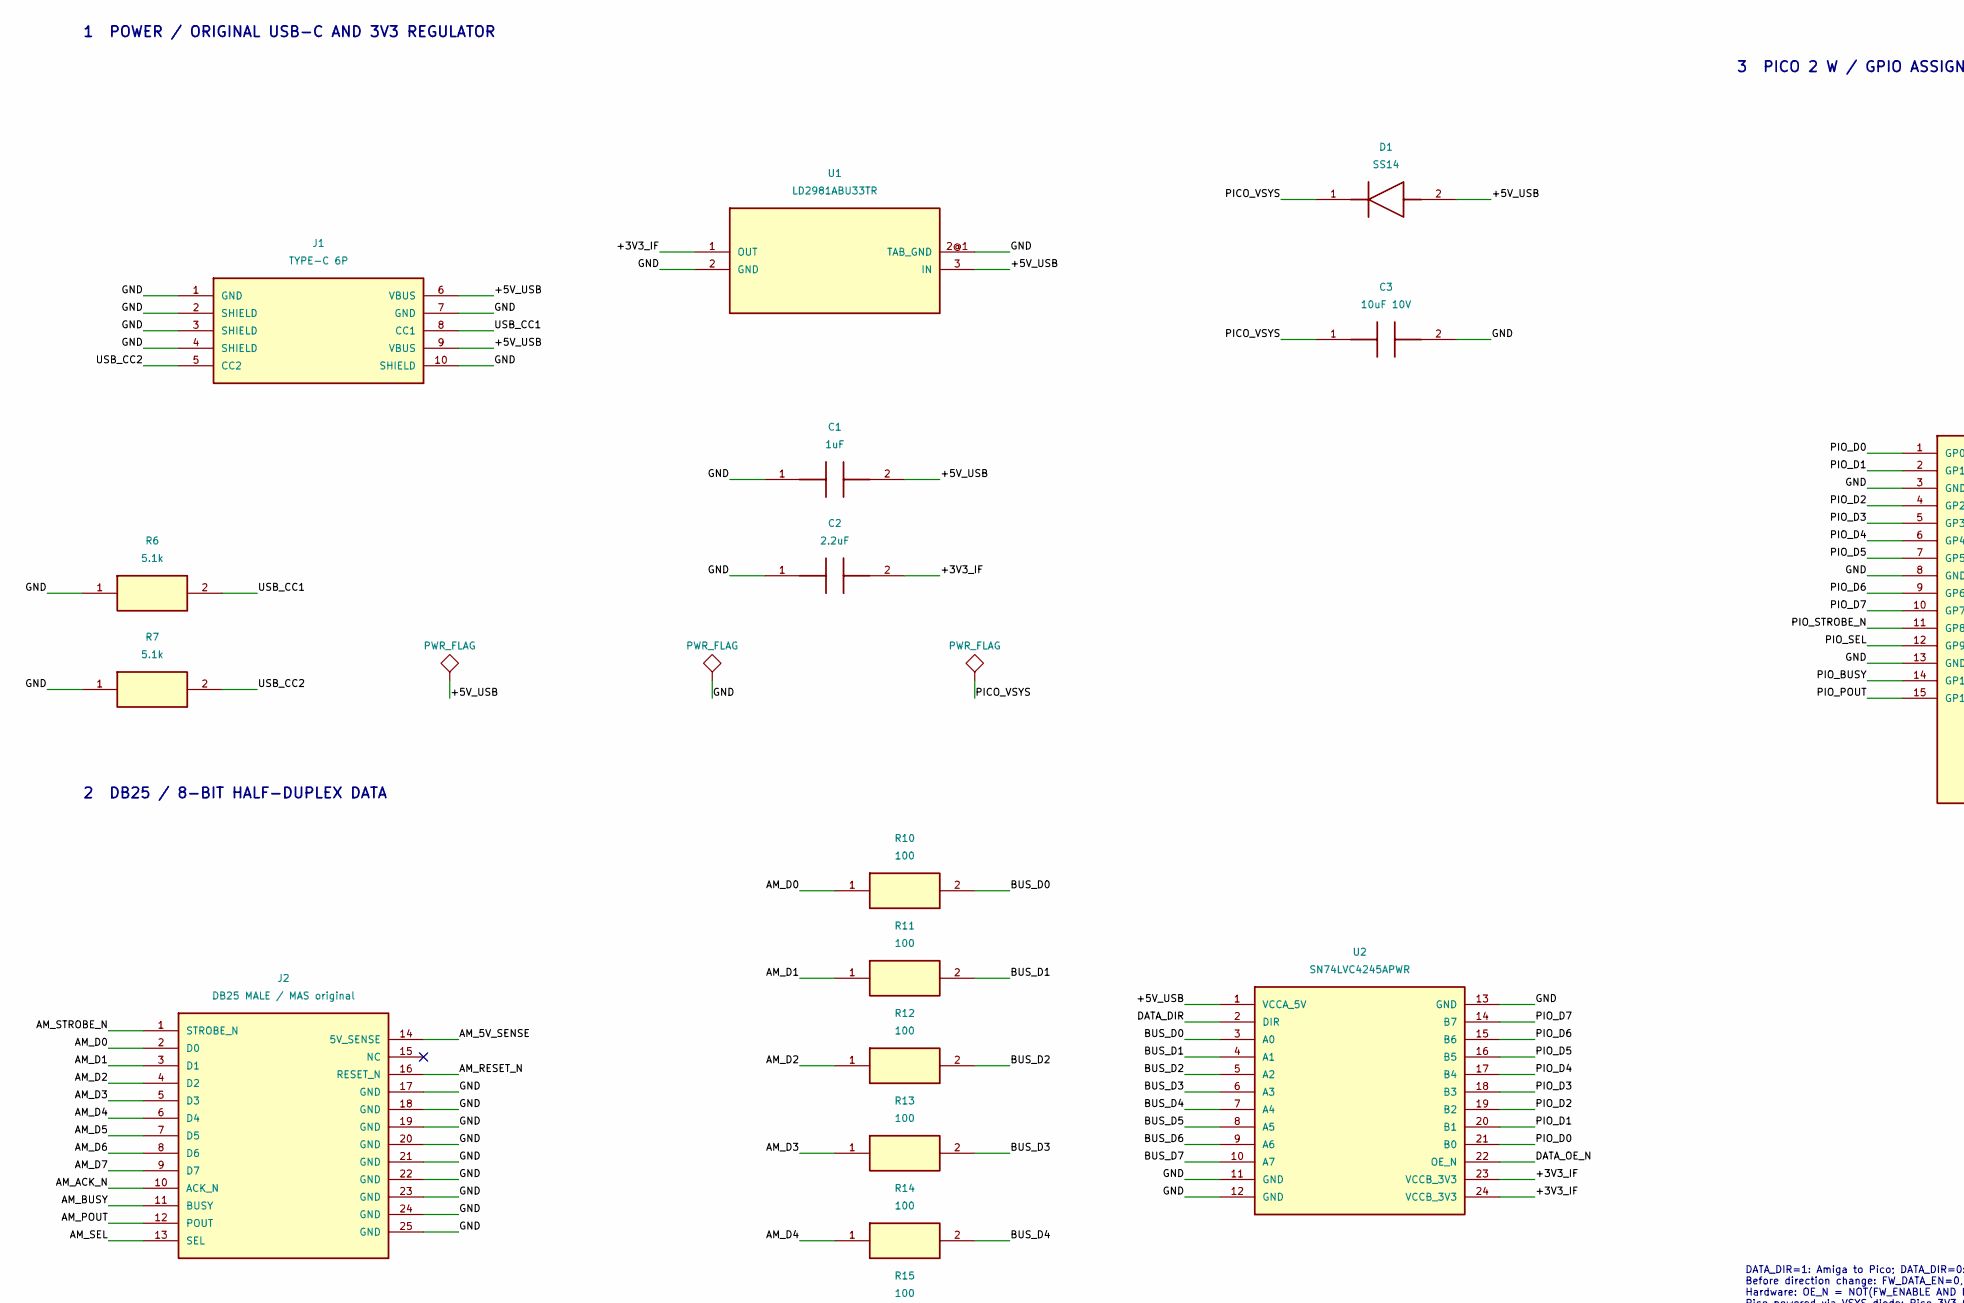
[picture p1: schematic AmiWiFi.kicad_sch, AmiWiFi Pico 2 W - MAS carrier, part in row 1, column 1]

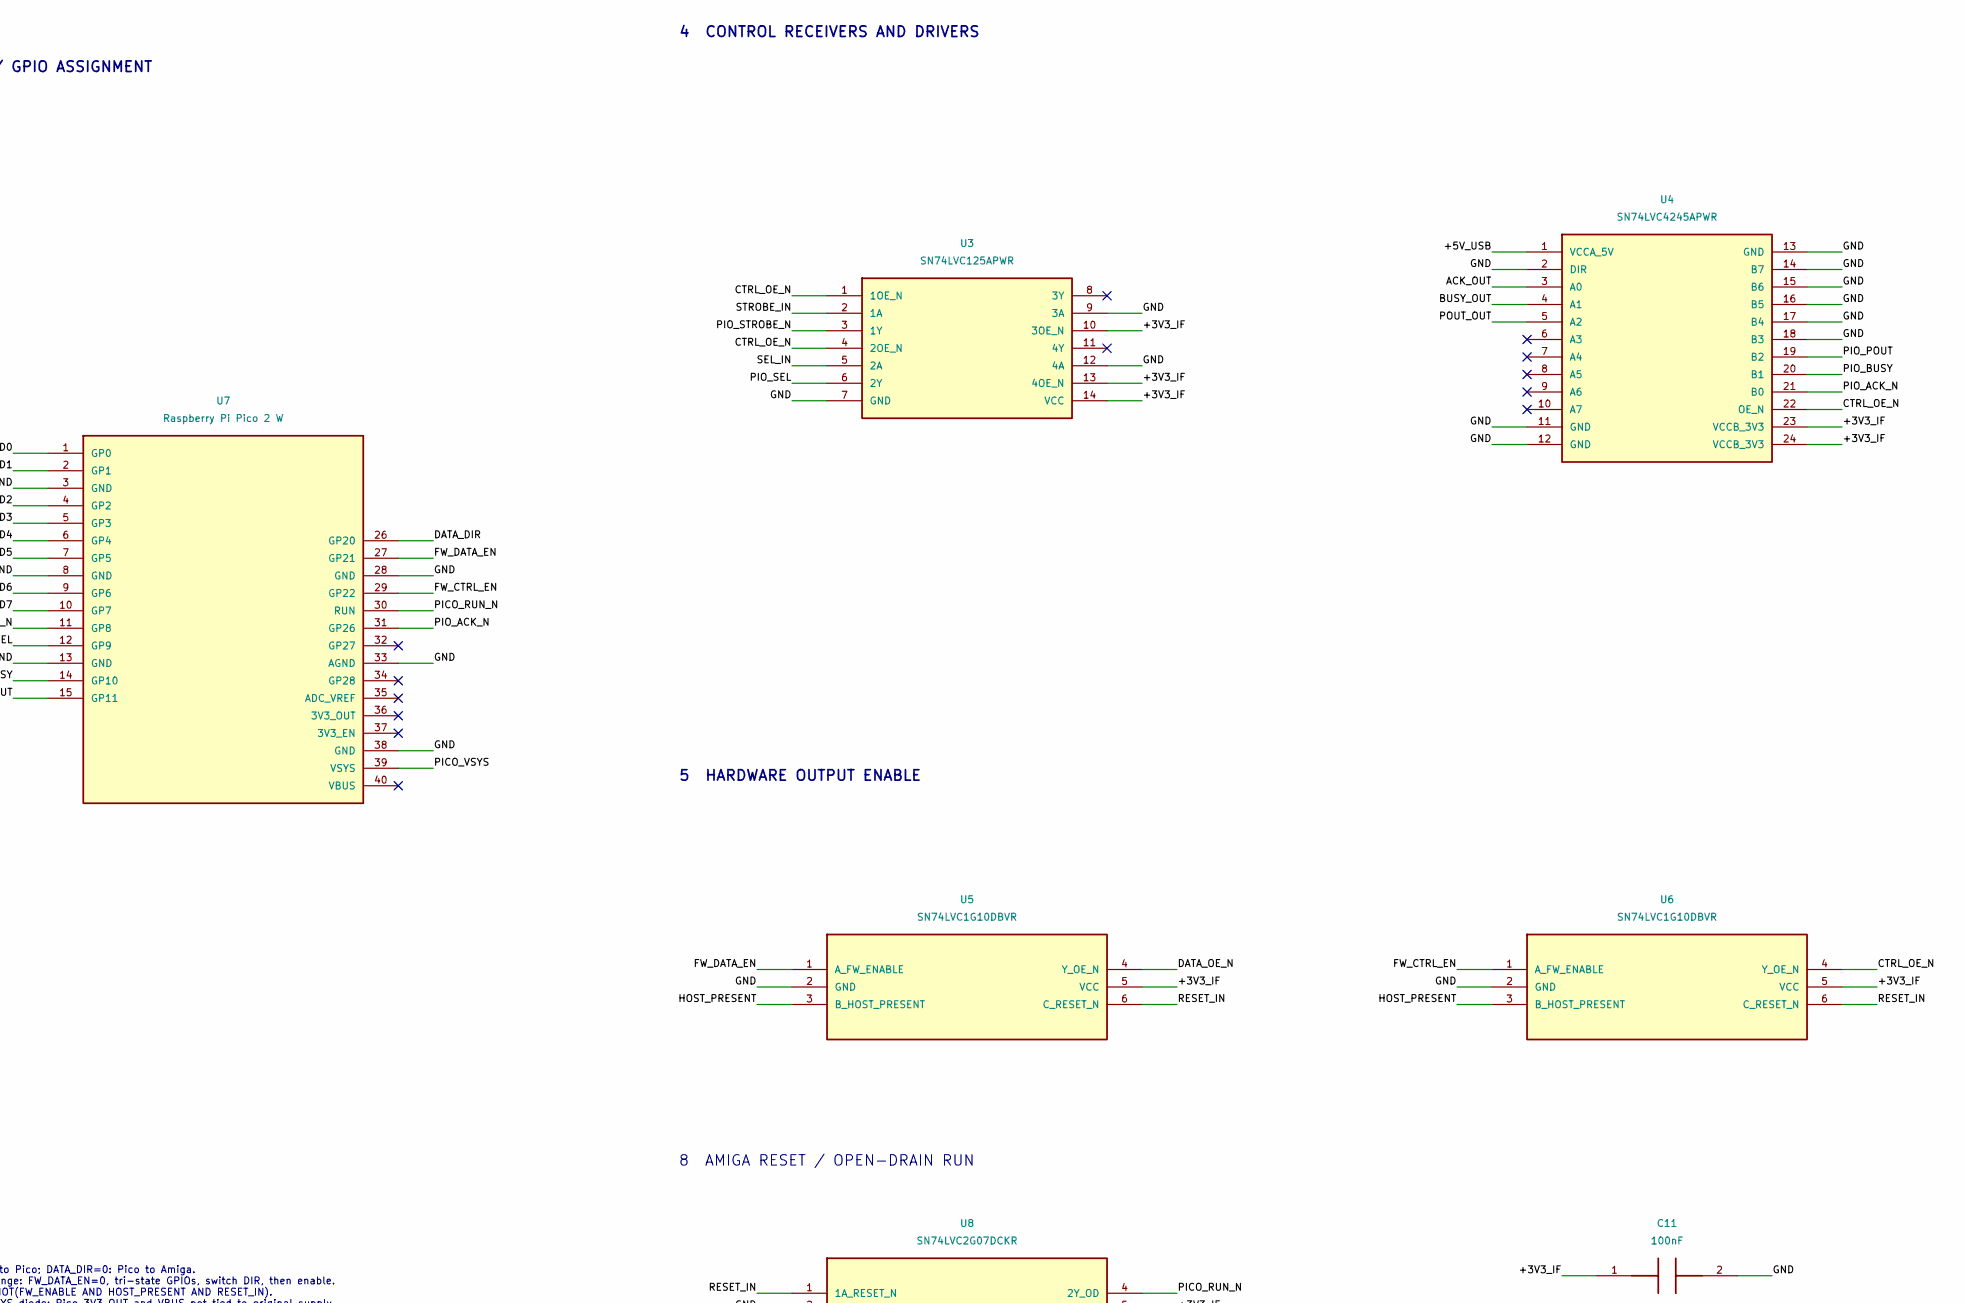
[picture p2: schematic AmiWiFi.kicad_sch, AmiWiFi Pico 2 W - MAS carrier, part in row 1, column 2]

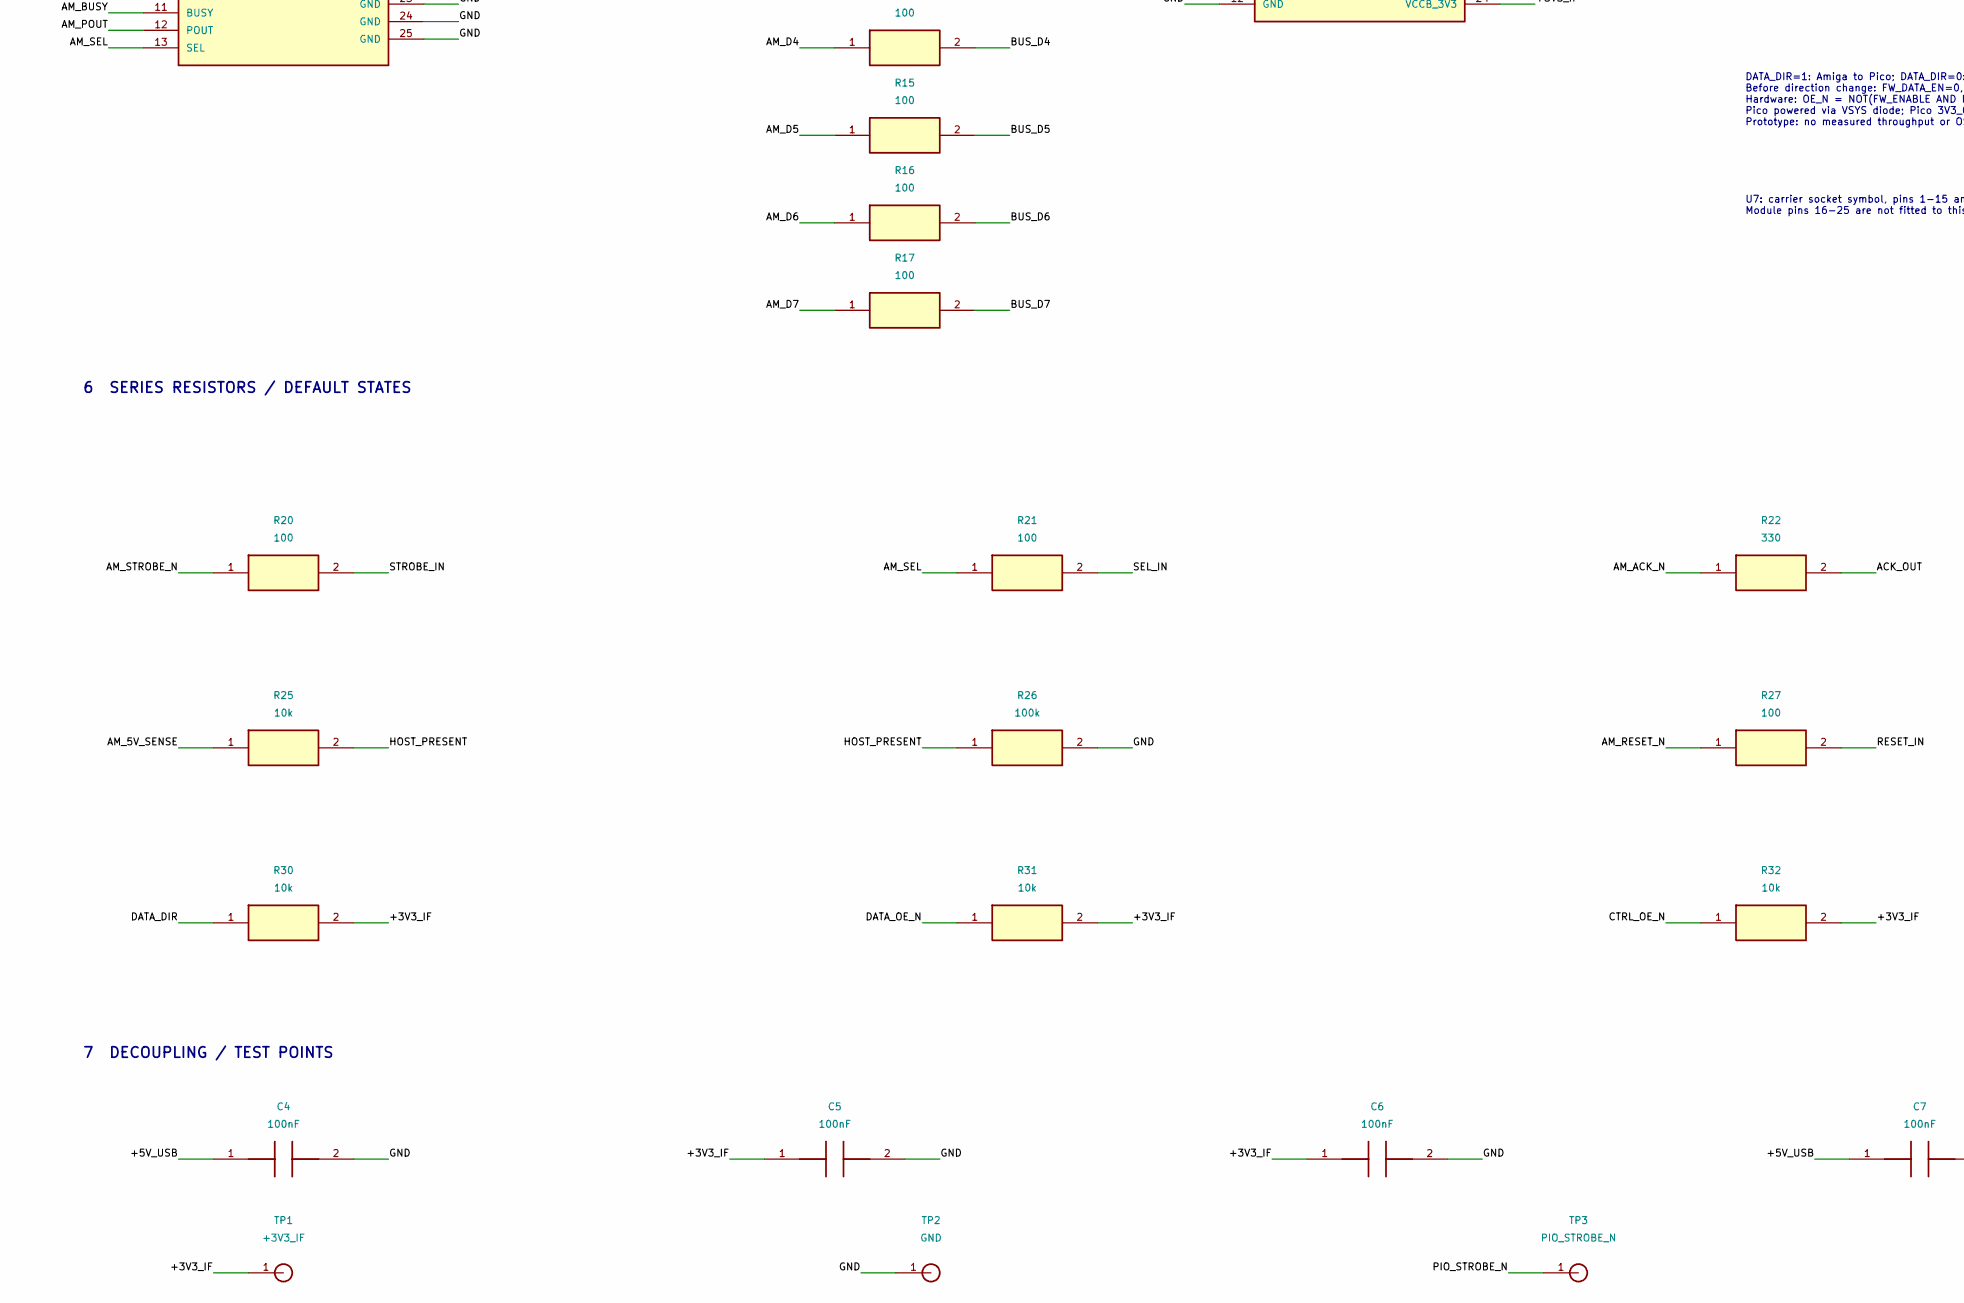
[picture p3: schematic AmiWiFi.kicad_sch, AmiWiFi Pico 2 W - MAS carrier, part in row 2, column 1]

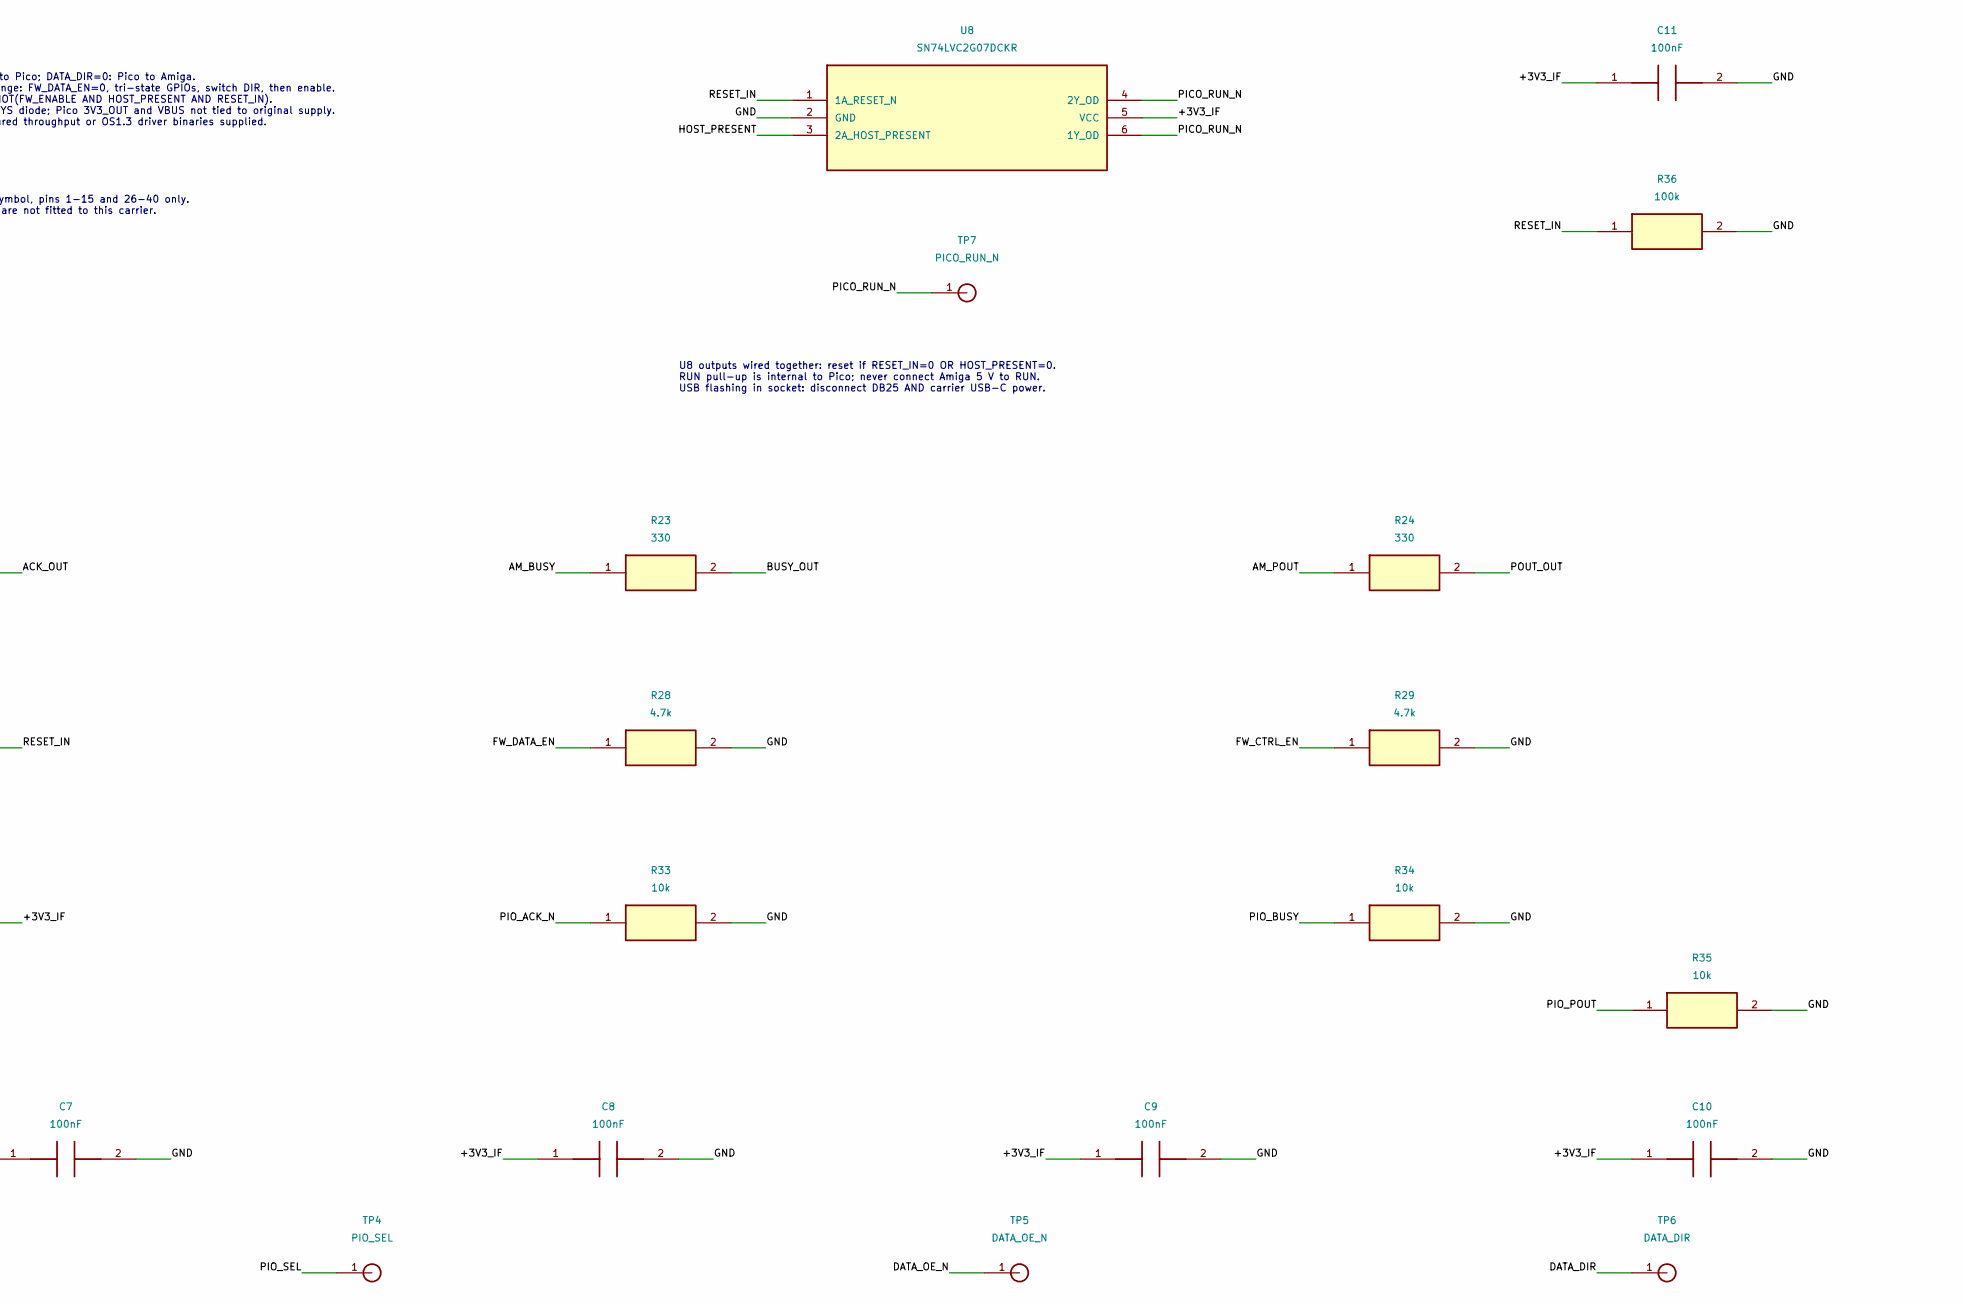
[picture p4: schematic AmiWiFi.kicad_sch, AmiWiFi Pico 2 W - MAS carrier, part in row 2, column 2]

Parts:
C1: 1uF; C0603_MAS_C1
C2: 2.2uF; C0603_MAS_C2
C3: 10uF 10V; C0805_C3
C4: 100nF; C0603_C4
C5: 100nF; C0603_C5
C6: 100nF; C0603_C6
C7: 100nF; C0603_C7
C8: 100nF; C0603_C8
C9: 100nF; C0603_C9
C10: 100nF; C0603_C10
C11: 100nF; C0603_C11
D1: SS14; SOD123_D1
J1: TYPE-C 6P; USB_C_MAS_Original_J1; LCSC C456012
J2: DB25 MALE / MAS original; DB25_MAS_Original_J2
R6: 5.1k; R0603_MAS_R6
R7: 5.1k; R0603_MAS_R7
R10: 100; R0402_R10
R11: 100; R0402_R11
R12: 100; R0402_R12
R13: 100; R0402_R13
R14: 100; R0402_R14
R15: 100; R0402_R15
R16: 100; R0402_R16
R17: 100; R0402_R17
R20: 100; R0402_R20
R21: 100; R0402_R21
R22: 330; R0402_R22
R23: 330; R0402_R23
R24: 330; R0402_R24
R25: 10k; R0402_R25
R26: 100k; R0402_R26
R27: 100; R0402_R27
R28: 4.7k; R0402_R28
R29: 4.7k; R0402_R29
R30: 10k; R0402_R30
R31: 10k; R0402_R31
R32: 10k; R0402_R32
R33: 10k; R0402_R33
R34: 10k; R0402_R34
R35: 10k; R0402_R35
R36: 100k; R0402_R36
TP1: +3V3_IF; TP1_TP1
TP2: GND; TP1_TP2
TP3: PIO_STROBE_N; TP1_TP3
TP4: PIO_SEL; TP1_TP4
TP5: DATA_OE_N; TP1_TP5
TP6: DATA_DIR; TP1_TP6
TP7: PICO_RUN_N; TP1_TP7
U1: LD2981ABU33TR; SOT89_MAS_Original_U1
U2: SN74LVC4245APWR; TSSOP24_U2
U3: SN74LVC125APWR; TSSOP14_U3
U4: SN74LVC4245APWR; TSSOP24_U4
U5: SN74LVC1G10DBVR; SOT23_6_U5
U6: SN74LVC1G10DBVR; SOT23_6_U6
U7: Raspberry Pi Pico 2 W; Pico2W_PartialSocket_15x2_U7
U8: SN74LVC2G07DCKR; SC70_6_DCK_U8

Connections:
/+3V3_IF: C2.2, C5.1, C6.1, C8.1, C9.1, C10.1, C11.1, R30.2, R31.2, R32.2, TP1.1, U1.1 (OUT), U2.23 (VCCB_3V3), U2.24 (VCCB_3V3), U3.10 (3OE_N), U3.13 (4OE_N), U3.14 (VCC), U4.23 (VCCB_3V3), U4.24 (VCCB_3V3), U5.5 (VCC), U6.5 (VCC), U8.5 (VCC)
/+5V_USB: C1.2, C4.1, C7.1, D1.2, J1.6 (VBUS), J1.9 (VBUS), U1.3 (IN), U2.1 (VCCA_5V), U4.1 (VCCA_5V)
/ACK_OUT: R22.2, U4.3 (A0)
/AM_5V_SENSE: J2.14 (5V_SENSE), R25.1
/AM_ACK_N: J2.10 (ACK_N), R22.1
/AM_BUSY: J2.11 (BUSY), R23.1
/AM_D0: J2.2 (D0), R10.1
/AM_D1: J2.3 (D1), R11.1
/AM_D2: J2.4 (D2), R12.1
/AM_D3: J2.5 (D3), R13.1
/AM_D4: J2.6 (D4), R14.1
/AM_D5: J2.7 (D5), R15.1
/AM_D6: J2.8 (D6), R16.1
/AM_D7: J2.9 (D7), R17.1
/AM_POUT: J2.12 (POUT), R24.1
/AM_RESET_N: J2.16 (RESET_N), R27.1
/AM_SEL: J2.13 (SEL), R21.1
/AM_STROBE_N: J2.1 (STROBE_N), R20.1
/BUSY_OUT: R23.2, U4.4 (A1)
/BUS_D0: R10.2, U2.3 (A0)
/BUS_D1: R11.2, U2.4 (A1)
/BUS_D2: R12.2, U2.5 (A2)
/BUS_D3: R13.2, U2.6 (A3)
/BUS_D4: R14.2, U2.7 (A4)
/BUS_D5: R15.2, U2.8 (A5)
/BUS_D6: R16.2, U2.9 (A6)
/BUS_D7: R17.2, U2.10 (A7)
/CTRL_OE_N: R32.1, U3.1 (1OE_N), U3.4 (2OE_N), U4.22 (OE_N), U6.4 (Y_OE_N)
/DATA_DIR: R30.1, TP6.1, U2.2 (DIR), U7.26 (GP20)
/DATA_OE_N: R31.1, TP5.1, U2.22 (OE_N), U5.4 (Y_OE_N)
/FW_CTRL_EN: R29.1, U6.1 (A_FW_ENABLE), U7.29 (GP22)
/FW_DATA_EN: R28.1, U5.1 (A_FW_ENABLE), U7.27 (GP21)
/GND: C1.1, C2.1, C3.2, C4.2, C5.2, C6.2, C7.2, C8.2, C9.2, C10.2, C11.2, J1.1 (GND), J1.2 (SHIELD), J1.3 (SHIELD), J1.4 (SHIELD), J1.7 (GND), J1.10 (SHIELD), J2.17 (GND), J2.18 (GND), J2.19 (GND), J2.20 (GND), J2.21 (GND), J2.22 (GND), J2.23 (GND), J2.24 (GND), J2.25 (GND), R6.1, R7.1, R26.2, R28.2, R29.2, R33.2, R34.2, R35.2, R36.2, TP2.1, U1.2 (GND), U1.2@1 (TAB_GND), U2.11 (GND), U2.12 (GND), U2.13 (GND), U3.7 (GND), U3.9 (3A), U3.12 (4A), U4.2 (DIR), U4.11 (GND), U4.12 (GND), U4.13 (GND), U4.14 (B7), U4.15 (B6), U4.16 (B5), U4.17 (B4), U4.18 (B3), U5.2 (GND), U6.2 (GND), U7.3 (GND), U7.8 (GND), U7.13 (GND), U7.28 (GND), U7.33 (AGND), U7.38 (GND), U8.2 (GND)
/HOST_PRESENT: R25.2, R26.1, U5.3 (B_HOST_PRESENT), U6.3 (B_HOST_PRESENT), U8.3 (2A_HOST_PRESENT)
/PICO_RUN_N: TP7.1, U7.30 (RUN), U8.4 (2Y_OD), U8.6 (1Y_OD)
/PICO_VSYS: C3.1, D1.1, U7.39 (VSYS)
/PIO_ACK_N: R33.1, U4.21 (B0), U7.31 (GP26)
/PIO_BUSY: R34.1, U4.20 (B1), U7.14 (GP10)
/PIO_D0: U2.21 (B0), U7.1 (GP0)
/PIO_D1: U2.20 (B1), U7.2 (GP1)
/PIO_D2: U2.19 (B2), U7.4 (GP2)
/PIO_D3: U2.18 (B3), U7.5 (GP3)
/PIO_D4: U2.17 (B4), U7.6 (GP4)
/PIO_D5: U2.16 (B5), U7.7 (GP5)
/PIO_D6: U2.15 (B6), U7.9 (GP6)
/PIO_D7: U2.14 (B7), U7.10 (GP7)
/PIO_POUT: R35.1, U4.19 (B2), U7.15 (GP11)
/PIO_SEL: TP4.1, U3.6 (2Y), U7.12 (GP9)
/PIO_STROBE_N: TP3.1, U3.3 (1Y), U7.11 (GP8)
/POUT_OUT: R24.2, U4.5 (A2)
/RESET_IN: R27.2, R36.1, U5.6 (C_RESET_N), U6.6 (C_RESET_N), U8.1 (1A_RESET_N)
/SEL_IN: R21.2, U3.5 (2A)
/STROBE_IN: R20.2, U3.2 (1A)
/USB_CC1: J1.8 (CC1), R6.2
/USB_CC2: J1.5 (CC2), R7.2

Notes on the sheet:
2 DB25 / 8-BIT HALF-DUPLEX DATA
6 SERIES RESISTORS / DEFAULT STATES
4 CONTROL RECEIVERS AND DRIVERS
1 POWER / ORIGINAL USB-C AND 3V3 REGULATOR
5 HARDWARE OUTPUT ENABLE
3 PICO 2 W / GPIO ASSIGNMENT
7 DECOUPLING / TEST POINTS
DATA_DIR=1: Amiga to Pico; DATA_DIR=0: Pico to Amiga. Before direction change: FW_DATA_EN=0, tri-state GPIOs, switch DIR, then enable. Hardware: OE_N = NOT(FW_ENABLE AND HOST_PRESENT AND RESET_IN). Pico powered via VSYS diode; Pico 3V3_OUT and VBUS not tied to original supply. Prototype: no measure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
8 AMIGA RESET / OPEN-DRAIN RUN
U8 outputs wired together: reset if RESET_IN=0 OR HOST_PRESENT=0. RUN pull-up is internal to Pico; never connect Amiga 5 V to RUN. USB flashing in socket: disconnect DB25 AND carrier USB-C power.
U7: carrier socket symbol, pins 1-15 and 26-40 only. Module pins 16-25 are not fitted to this carrier.

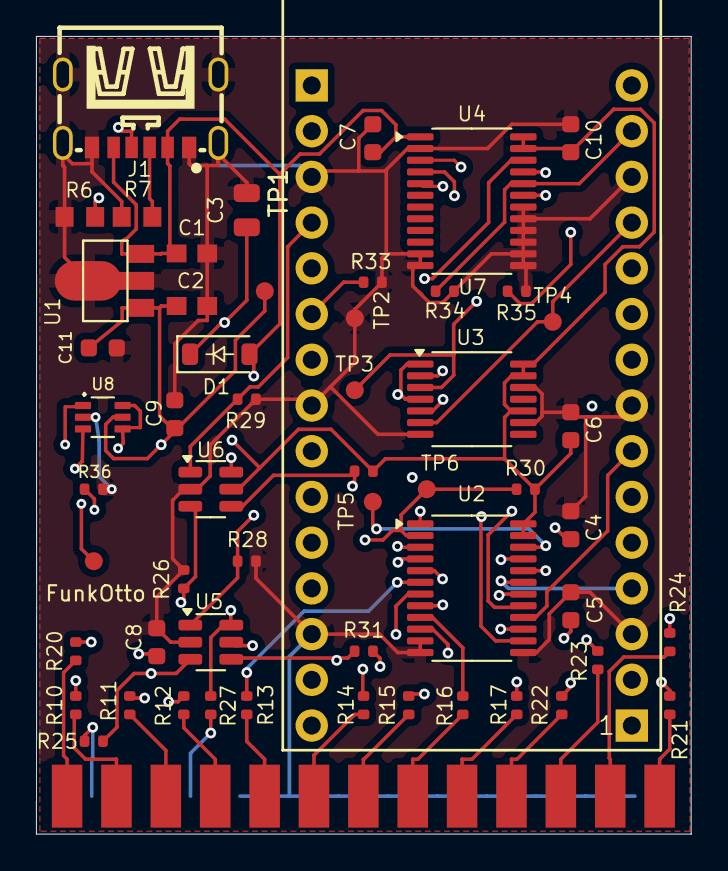
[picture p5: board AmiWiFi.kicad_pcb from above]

Board: 4 copper layers, 36.4 x 44.3 mm, 56 parts (0 on the bottom side), 55 nets.

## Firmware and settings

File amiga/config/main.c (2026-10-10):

#include <string.h>
#include "sim.h"
#include "os.h"
#ifndef FO_DIAG_SOURCE
#define FO_DIAG_SOURCE "development"
#endif
void *SysBase,*DOSBase,*MiscBase;
extern uint32_t cfg_os_open(const char *name, uint32_t mode);
extern int32_t cfg_os_close(uint32_t handle);
extern int32_t cfg_os_read(uint32_t handle, void *p, uint32_t n);
extern void cfg_os_delay(uint32_t ticks);
extern int cfg_selftest(void);
static uint32_t output, console;
static bool io_failed, cancelled;
static struct cfg_client client;
static uint8_t line[96], profile[98];
static void put(const char *s) {
    uint32_t n=0; while (s[n]) ++n;
    if (!io_failed && os_write(output,s,n)!=(int32_t)n) io_failed=true;
}
static void number(uint32_t value) {
    static const uint32_t powers[]={1000000000u,100000000u,10000000u,1000000u,
        100000u,10000u,1000u,100u,10u,1u};
    bool started=false;
    for (unsigned i=0;i<10;++i) {
        char digit='0'; while (value>=powers[i]) { value-=powers[i]; ++digit; }
        if (digit!='0' || started || i==9) {
            char s[2]={digit,0}; put(s); started=true;
        }
    }
}
static void signed_number(int32_t value) {
    if (value<0) { put("-"); number(0u-(uint32_t)value); } else number((uint32_t)value);
}
static void hex(uint8_t b) {
    static const char digits[]="0123456789abcdef";
    char s[3]={digits[b>>4],digits[b&15u],0}; put(s);
}
static void bytes(const uint8_t *p, unsigned n) {
    put("\"");
    for (unsigned i=0;i<n;++i) {
        uint8_t b=p[i];
        if (b>=32 && b<=126 && b!='"' && b!='\\') { char s[2]={(char)b,0}; put(s); }
        else { put("\\x"); hex(b); }
    }
    put("\"");
}
static void mac(const uint8_t *p) {
    for (unsigned i=0;i<6;++i) { if (i) put(":"); hex(p[i]); }
}
static bool equal(const uint8_t *p, unsigned n, const char *s) {
    unsigned i=0;
    for (;i<n && s[i];++i) {
        unsigned c=p[i]; if (c>='a' && c<='z') c-=32;
        if (c!=(unsigned char)s[i]) return false;
    }
    return i==n && !s[i];
}
static int wait_tick(void) {
    if (cancelled || io_failed || (os_signals()&4096u)) { cancelled=true; return 0; }
    cfg_os_delay(5); return 1;
}
/* RAW: owns its echo. Reject an entire overflowing/control-sequence line;
 * never send silently truncated credentials. No history or password echo. */
static int read_line(unsigned maximum, bool secret) {
    unsigned n=0; bool bad=false;
    fo_wipe(line,sizeof(line));
    while (!io_failed) {
        uint8_t ch=0;
        if ((os_signals()&4096u) || cfg_os_read(console,&ch,1)!=1 || ch==3 || ch==4) {
            cancelled=true; fo_wipe(line,sizeof(line)); return -1;
        }
        if (ch=='\r' || ch=='\n') { put("\n"); return bad ? -2 : (int)n; }
        if (ch==8 || ch==127) {
            if (n && !bad) { line[--n]=0; if (!secret) put("\b \b"); }
        } else if (ch>=32 && ch<=126) {
            if (n>=maximum) bad=true;
            if (!bad) { line[n++]=ch; if (!secret) { char s[2]={(char)ch,0}; put(s); } }
        } else bad=true;
    }
    return -1;
}
static void result(int value) {
    if (!value) { put("OK\n"); return; }
    put("ERROR client="); signed_number(value);
    put(" protocol="); number(client.remote_result);
    put(" job_reply="); number(client.job_reply);
    put(" (timeout/cancel: operation may already have completed)\n");
}
static void status(void) {
    int rc=cfg_query(&client,CFG_STATUS,NULL,0);
    if (rc) { result(rc); return; }
    const uint8_t *r=client.response;
    put("SIM state="); put(fo_state_name((enum fo_wifi_state)r[1]));
    put(" error="); put(fo_error_name((enum fo_wifi_error)r[2]));
    put(" configured="); number(r[3]&1u); put(" stored="); number((r[3]>>1)&1u);
    put(" auto_retry="); number((r[3]>>2)&1u); put("\nSSID="); bytes(r+51,r[50]);
    put(" MAC="); mac(r+6); put(" RSSI=");
    if (r[3]&16u) signed_number((int32_t)cfg_u32(r+12)); else put("n/a");
    put("\nflash_state="); number(r[4]); put(" sequence="); number(cfg_u32(r+32));
    put(" epoch="); number(cfg_u32(r+20)); put(" links="); number(cfg_u32(r+28)); put("\n");
}
static void scan(void) {
    int rc=cfg_scan(&client); if (rc) { result(rc); put("Use disconnect before scan.\n"); return; }
    uint8_t request[5]; cfg_put32(request,cfg_u32(client.response+40));
    unsigned count=client.response[48];
    put("SIM scan count="); number(count); put(" truncated="); number(client.response[49]); put("\n");
    for (unsigned i=0;i<count;++i) {
        request[4]=(uint8_t)i; rc=cfg_query(&client,CFG_SCAN_GET,request,5);
        if (rc) { result(rc); return; }
        const uint8_t *r=client.response;
        number(i+1u); put(" SSID="); bytes(r+20,r[19]); put(" BSSID="); mac(r+13);
        put(" channel="); number(cfg_u16(r+9)); put(" RSSI="); signed_number((int16_t)cfg_u16(r+11));
        put(" auth=0x"); hex(r[8]); put("\n");
    }
}
static void set_profile(void) {
    fo_wipe(profile,sizeof(profile));
    put("SSID (1..32 ASCII bytes, spaces allowed): ");
    int n=read_line(32,false); if (n<1) goto invalid;
    profile[0]=1; profile[1]=(uint8_t)n; memcpy(profile+3,line,(size_t)n);
    put("Test WPA2 password (8..63 ASCII bytes, hidden): ");
    n=read_line(63,true); if (n<8) goto invalid;
    profile[2]=(uint8_t)n; memcpy(profile+3+profile[1],line,(size_t)n);
    fo_wipe(line,sizeof(line));
    result(cfg_mutate(&client,CFG_SET,profile,3u+profile[1]+profile[2]));
    fo_wipe(profile,sizeof(profile)); return;
invalid:
    fo_wipe(profile,sizeof(profile)); fo_wipe(line,sizeof(line));
    if (!cancelled) put("Invalid input; profile unchanged.\n");
}
static bool confirm(void) {
    put("Simulation only. Type YES to confirm: ");
    int n=read_line(8,false); return n==3 && equal(line,3,"YES");
}
static void help(void) {
    put("status scan set connect disconnect save erase reboot help quit\n"
        "SIM ONLY: no Pico, no WLAN, no CIA access, no disk writes.\n"
        "Use a made-up password. Simulated flash survives reboot, not quit.\n"
        "Input: Return, Backspace; Ctrl-C/Ctrl-D quit. No cursor editing.\n");
}
int diag_main(const uint8_t *args, uint32_t length) {
    DOSBase=os_open_library("dos.library",34); if (!DOSBase) return 20;
    output=os_output(); int exit_code=0;
    while (length && (*args==' ' || *args=='\t')) { ++args; --length; }
    while (length && (args[length-1]==' ' || args[length-1]=='\n' || args[length-1]=='\r')) --length;
    put("FunkOttoConfig M4 / 68000 / OS 1.3 source=" FO_DIAG_SOURCE "\n");
    if (equal(args,length,"SELFTEST")) {
        int failed=cfg_selftest();
        if (failed) { put("FAIL local FOC1 selftest line="); number((uint32_t)failed); put("\n"); exit_code=20; }
        else put("PASS: local FOC1 configuration selftest; no CIA access.\n");
    } else if (equal(args,length,"SIM")) {
        console=cfg_os_open("RAW:0/12/640/180/FunkOttoConfig SIM",1005);
        if (!console) { put("Cannot open RAW console.\n"); exit_code=20; }
        else {
            output=console; client.transport.exchange=cfg_sim_exchange; client.transport.wait=wait_tick;
            cfg_sim_init(); help();
            int rc=cfg_query(&client,CFG_INFO,NULL,0);
            if (rc) { result(rc); exit_code=20; }
            else while (!cancelled && !io_failed) {
                put("SIM> "); int n=read_line(20,false);
                if (n==-1) break;
                if (n==-2) { put("Invalid/too long input.\n"); continue; }
                if (!n) continue;
                if (equal(line,(unsigned)n,"QUIT")) break;
                if (equal(line,(unsigned)n,"HELP")) help();
                else if (equal(line,(unsigned)n,"STATUS")) status();
                else if (equal(line,(unsigned)n,"SCAN")) scan();
                else if (equal(line,(unsigned)n,"SET")) set_profile();
                else if (equal(line,(unsigned)n,"CONNECT")) {
                    rc=cfg_mutate(&client,CFG_CONNECT,NULL,0);
                    if (!rc) rc=cfg_wait_link(&client);
                    result(rc); status();
                } else if (equal(line,(unsigned)n,"DISCONNECT")) result(cfg_mutate(&client,CFG_DISCONNECT,NULL,0));
                else if (equal(line,(unsigned)n,"SAVE")) {
                    if (confirm()) result(cfg_mutate(&client,CFG_SAVE,NULL,0));
                    else put("Cancelled.\n");
                } else if (equal(line,(unsigned)n,"ERASE")) {
                    if (confirm()) result(cfg_mutate(&client,CFG_ERASE,NULL,0));
                    else put("Cancelled.\n");
                } else if (equal(line,(unsigned)n,"REBOOT")) {
                    cfg_sim_reboot(); put("SIM adapter restarted.\n"); status();
                } else put("Unknown command. Type help.\n");
            }
            cfg_sim_close(); cfg_os_close(console); console=0;
        }
    } else { put("Usage: FunkOttoConfig SELFTEST | SIM\nParallel transport is not implemented.\n"); exit_code=10; }
    fo_wipe(line,sizeof(line)); fo_wipe(profile,sizeof(profile)); fo_wipe(&client,sizeof(client));
    if (cancelled) exit_code=5;
    if (io_failed) exit_code=20;
    os_close_library(DOSBase); DOSBase=NULL; return exit_code;
}

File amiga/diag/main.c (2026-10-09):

#include "m2.h"
#include "m2_host.h"
#include "os.h"
#include <string.h>
#ifndef FO_DIAG_SOURCE
#define FO_DIAG_SOURCE "development"
#endif
#define REG(a) (*(volatile uint8_t *)(uintptr_t)(a))
#define PRB REG(0xbfe101u)
#define DDRB REG(0xbfe301u)
#define PRA REG(0xbfd000u)
#define DDRA REG(0xbfd200u)
void *SysBase,*DOSBase,*MiscBase;
static uint32_t output;
static bool owned_port,owned_bits,touched,closing;
static uint8_t saved_ddrb,saved_data,saved_ddra,saved_pra;
static uint8_t request[FO_M2_BLOCK],reply[FO_M2_BLOCK],payload[FO_M2_PAYLOAD];
static struct fo_m2_server local;
static struct fo_m2_io io;
static void text(const char *s) { uint32_t n=0;while(s[n]) ++n;(void)os_write(output,s,n); }
static void hex(uint32_t n) {
    char b[9];for(unsigned i=0;i<8;i++) b[i]="0123456789abcdef"[(n>>(28u-4u*i))&15u];
    b[8]=0;text(b);
}
static uint8_t status(void *c) { (void)c;return PRA&3u; }
static void input(void *c) { (void)c;DDRB=0; }
static void direction_out(void *c) { (void)c;DDRB=255; }
static void select_phase(void *c,bool high) {
    (void)c;os_disable();
    /* Do not restore a saved full PRA byte: upper bits belong to serial I/O. */
    uint8_t v=PRA;PRA=(uint8_t)((v&0xfbu)|(high?4u:0u));os_enable();
}
static void write_byte(void *c,uint8_t b) { (void)c;PRB=b; }
static uint8_t read_byte(void *c) { (void)c;return PRB; }
static uint32_t ticks(void *c) {
    (void)c;os_disable(); /* TOD high latches, low unlatches; no timer writes. */
    uint32_t n=(uint32_t)REG(0xbfea01u)<<16;
    n|=(uint32_t)REG(0xbfe901u)<<8;n|=REG(0xbfe801u);os_enable();return n;
}
static bool cancelled(void *c) { (void)c;return !closing && (os_signals()&4096u)!=0; }
static bool acquire(void) {
    MiscBase=os_open_resource("misc.resource");if(!MiscBase) return false;
    if(os_alloc_misc(2,"FunkOttoDiag")) return false;
    owned_port=true;
    if(os_alloc_misc(3,"FunkOttoDiag")) return false;
    owned_bits=true;
    os_disable();
    /* Timer outputs can override DDRB. Refuse, never alter running timers.
       CIAB serial-output mode would drive BUSY/SP and is also incompatible. */
    if((REG(0xbfee01u)&2u)||(REG(0xbfef01u)&2u)||(REG(0xbfde00u)&64u)) {
        os_enable();return false;
    }
    saved_ddrb=DDRB;saved_data=PRB;saved_ddra=DDRA&7u;saved_pra=PRA&7u;
    DDRB=0;PRA=(uint8_t)(PRA|4u);DDRA=(uint8_t)((DDRA&0xf8u)|4u);
    touched=true;os_enable();return true;
}
static void release(void) {
    if(touched) {
        closing=true;
        bool safe=fo_m2_host_sync(&io)==0;
        os_disable();DDRB=0;
        if(safe) {
            /* Pico acknowledged receive direction. Restoring PRB generates one
               STROBE, but cannot make a valid HELLO or enable Pico outputs. */
            PRB=saved_data;DDRB=saved_ddrb;
            PRA=(uint8_t)((PRA&0xf8u)|saved_pra);
            DDRA=(uint8_t)((DDRA&0xf8u)|saved_ddra);
        } else {
            /* No proof of turnaround: leave all data/status bits as inputs.
               Restoring an output direction here could cause a bus collision. */
            DDRA=(uint8_t)(DDRA&0xf8u);
        }
        os_enable();
        if(!safe) text("Port release: no turnaround confirmation; data/status left as inputs.\n");
    }
    if(owned_bits) os_free_misc(3);
    if(owned_port) os_free_misc(2);
}
static bool transact(bool hardware,uint8_t op,uint16_t seq,uint16_t n) {
    if(!fo_m2_pack(request,op,seq,payload,n)) return false;
    if(hardware) {
        int e=fo_m2_host_exchange(&io,request,reply);
        if(e) { text(e==FO_HOST_CANCEL?"Ctrl-C\n":"Handshake timeout\n");return false; }
    } else if(!fo_m2_request(&local,request,reply)) return false;
    struct fo_m2_frame f;
    return fo_m2_unpack(reply,&f) && f.op==(uint8_t)(op|128u) && f.sequence==seq &&
           f.length>=1 && f.payload[0]==FO_M2_OK;
}
static bool run(bool hardware,uint32_t count) {
    if(fo_m2_crc((const uint8_t *)"123456789",9)!=0x29b1u) return false;
    uint32_t nonce=hardware?ticks(NULL):0x12345678u;
    fo_m2_put32(payload,nonce);fo_m2_put32(payload+4,~nonce);
    if(!transact(hardware,FO_M2_HELLO,0,8)) return false;
    struct fo_m2_frame f;
    if(!fo_m2_unpack(reply,&f)||f.length!=18||memcmp(f.payload+1,payload,8)||
       f.payload[13]!=1 || f.payload[14]!=5 || f.payload[15]!=220 ||
       f.payload[16]!=6 || f.payload[17]!=0) return false;
    uint32_t session=fo_m2_u32(f.payload+9);
    text("HELLO session=");hex(session);text("\n");
    static const uint16_t sizes[]={0,1,2,7,63,255,512,1500};
    uint16_t seq=1;
    for(uint32_t i=0;i<count;i++,seq=(uint16_t)(seq+1u)) {
        uint16_t length=sizes[i&7u];fo_m2_put32(payload,session);
        uint32_t random=i+1u;
        for(unsigned j=0;j<length;j++) {
            random^=random<<13;random^=random>>17;random^=random<<5;
            unsigned pattern=(unsigned)((i>>3)&7u);
            payload[4+j]=pattern==0?0:pattern==1?255:pattern==2?0x55:pattern==3?0xaa:
                pattern==4?(uint8_t)(1u<<(j&7u)):pattern==5?(uint8_t)~(1u<<(j&7u)):(uint8_t)random;
        }
        if(!transact(hardware,FO_M2_ECHO,seq,(uint16_t)(4u+length)) ||
           !fo_m2_unpack(reply,&f) || f.length!=5u+length ||
           memcmp(f.payload+1,payload,4u+length)) { text("ECHO failed at ");hex(i);text("\n");return false; }
    }
    text("ECHO verified count=0x");hex(count);text("\n");return true;
}
static bool token(const char **p,const char *end,const char *word) {
    while(*p<end && (**p==' '||**p=='\n'||**p=='\r')) ++*p;
    const char *q=*p;while(q<end && *word && *q==*word) { ++q;++word; }
    if(*word || (q<end && *q!=' '&&*q!='\n'&&*q!='\r')) return false;
    *p=q;return true;
}
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

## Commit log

2026-10-05 Document Rev B Pico RUN reset based on user-edited KiCad hardware
2026-10-05 Describe selected Pico reset and USB service procedure
2026-10-06 Correct KiCad verification scope and document Rev B1 consistency fixes
2026-10-07 Add ongoing ideas list with optional traffic LED retrofit
2026-10-07 Add idea for resettable polyfuse on adapter 5V supply
2026-10-08 Add complete Rev B2 KiCad hardware, libraries, BOM, previews and validation
    [AmiWiFi.kicad_pcb, AmiWiFi.kicad_sch, BOM.csv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]
2026-10-08 Import user-edited KiCad files from AmiWiFi_Pico2W.zip
    [AmiWiFi.kicad_pcb]
2026-10-08 Implement Pico 2 W M1 USB diagnostics with locked bus and pinned build
    Add safe GPIO startup, bounded USB console and watchdog. Reserve profile flash
    and a separate RP2350-E10 sector; validate hardware pinout and UF2/ELF output.
    Add host tests, CI and build instructions; document pending hardware tests.
2026-10-08 Plan isolated WLAN development and record confirmed Pico cold-start test
    Define W1-W5 for CYW43 integration, USB configuration, raw Ethernet tests,
    profile persistence and recovery. Record user-confirmed M1 USB status and
    cold start without a terminal; keep electrical M0 and watchdog tests open.
2026-10-08 Implement W1/W2 Pico WLAN bring-up, scan and RAM-profile connection
    Run pinned CYW43 without lwIP on Core 1 while keeping USB and the parallel
    bus guard on Core 0. Add bounded USB configuration, retries, diagnostics,
    SDK-fake service tests, artifact checks and a packaged WLAN test build.
    Credentials remain RAM-only; raw Ethernet and Amiga transport are pending.
2026-10-08 Record first user-confirmed WLAN link and receive callbacks
    Document successful first-attempt join, timing and resource diagnostics.
    Keep reconnect and raw-frame validation open; redact network identifiers
    and distinguish changed access point from signal-strength effects.
2026-10-08 Record successful automatic WLAN recovery after access-point outage
    Confirm third link on attempt ten and distinguish retained diagnostic
    history from the current successful connection. Update W1/W2 progress.
2026-10-10 docs: plan configuration development while carrier board is unavailable
2026-10-10 Add OS 1.3 FOC1 configuration client and local adapter simulator
    Plan Amiga configuration independently of the pending carrier-board tests.
    Build FunkOttoConfig SELFTEST/SIM for 68000 with hidden password input,
    profile lifecycle, paced jobs and a replaceable transport. Exercise the real
    FOC1 dispatcher in the simulator; keep parallel hardware access disabled.
    Validate with native sanitizer tests and 20 HUNK emulation scenarios using
    V34 OS mocks. Include packaging, CI and the real A500 test instructions.
    [build_amiga_config.py, main.c, package_amiga_config.py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]
2026-10-13 Prepare FOE1 Ethernet transport core and M5a implementation plan
    Add variable-length CRC32 packets, session/sequence replay protection,
    asynchronous TX tickets, RX, FOC1 encapsulation and generation-based event
    arming. Require atomic epoch checks in the future WLAN backend.
    Exercise the core with production Ethernet queues, sanitizer tests, an
    independent Python wire reference and freestanding 68000 emulation.
    Document remaining Pico, USB, parallel, interrupt and SANA-II integration.
    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
2026-10-15 Align KiCad footprints with user hardware revision and add missing LED components
2026-10-15 Fix F8 symbol identity links and verify full paths against KiCad netlist
2026-10-15 Implement M5 USB Ethernet transport with Pico WLAN backend and diagnostics
    Add synchronized FOE1 queue operations, exclusive bounded COBS USB transport,
    FOC1 configuration access and an eight-ticket PC Ethernet diagnostic client.
    Preserve completions across flash operations and cover replay, epoch changes,
    partial packets and session loss. Document software validation and pending
    real-Pico acceptance; keep parallel bus disabled.
2026-10-15 Record successful real-Pico 1000-ping eight-ticket RX-interleaving test
    Verify uploaded JSON and PCAP: 1000 replies, correct checksums/payloads,
    no inferred RX overflow, no USB errors, all TX slots released.
    Keep configuration/reconnect/USB-abort acceptance pending.
